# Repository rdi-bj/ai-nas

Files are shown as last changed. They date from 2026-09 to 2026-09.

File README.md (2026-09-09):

# AI NAS 开源项目

本仓库是北京 RDI 创新中心 AI NAS 项目的完整开源 monorepo，包含硬件设计源文件与自研软件/部署脚本。

```
ai-nas/
├── ai-nas-hardware/   # 硬件设计源文件（CERN-OHL-P v2）
└── ai-nas-software/   # 自研软件、固件、部署脚本（Mulan PSL v2）
```

## 子项目说明

| 目录 | 内容 | 许可证 |
|---|---|---|
| [`ai-nas-hardware/`](./ai-nas-hardware/README.md) | RISC-V AI NAS 主板、SATA 扩展板、FPC 排线的原理图、PCB 版图与 BOM | CERN-OHL-P v2 |
| [`ai-nas-software/`](./ai-nas-software/README.md) | 板级支持、NAS 服务、Web UI、部署脚本 | Mulan PSL v2（OMV submodule 为 GPLv3） |

## 快速开始

```bash
# 克隆整个 monorepo
git clone git@github.com:rdi-bj/ai-nas.git
cd ai-nas

# 查看硬件设计
cd ai-nas-hardware

# 查看软件与部署
cd ../ai-nas-software
```

## 双平台同步

本仓以 **GitHub 为主仓**，通过 `.github/workflows/mirror-to-gitee.yml` 单向镜像到 **Gitee**，请勿在 Gitee 端直接提交。

## 二进制发布（固件 / 系统镜像）

可烧录 / 部署的二进制资产（引导固件、系统镜像、OMV 安装包、内核 deb 等）通过 **GitHub Releases** 发布，不纳入 git 仓库：

- 最新发布包 `v1.0-sdk-20260722`：[GitHub Releases 下载](https://github.com/rdi-bj/ai-nas/releases/tag/v1.0-sdk-20260722)
- 全部发布历史：[GitHub Releases](https://github.com/rdi-bj/ai-nas/releases)

> 说明：受 Gitee 免费版单文件（≤100 MB）与 LFS 额度限制，本项目的二进制资产集中在 GitHub Releases；Gitee 仅镜像源码，下载请走上述 GitHub 链接。

## 许可证声明

- 硬件设计：CERN Open Hardware Licence v2 - Permissive（见 `ai-nas-hardware/LICENSE`）。
- 自研软件：木兰宽松许可证 v2（见 `ai-nas-software/LICENSE`）。
- 上游 OpenMediaVault（OMV）为 GPLv3，以 git submodule 形式在 `ai-nas-software/src/openmediavault/` 引用，不复制源码到本仓。

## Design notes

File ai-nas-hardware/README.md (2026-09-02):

# AI NAS 硬件开源仓库（ai-nas-hardware）

基于 RISC-V 的家用开源 AI NAS 硬件设计目录。本目录只包含**硬件设计文件**，软件部分见同仓 [`ai-nas-software`](../ai-nas-software/README.md)。

## 许可证

本仓库所有硬件设计文件以 **CERN Open Hardware Licence v2 - Permissive（CERN-OHL-P v2）** 发布。许可证全文见 [`LICENSE`](./LICENSE)。

> CERN-OHL-P v2 是最宽松的硬件开源许可证，允许任何人自由使用、研究、修改、制造与分发基于本设计的硬件产品，无"传染性"义务，仅要求保留声明（Notices）。

## 目录结构

```
ai-nas-hardware/
├── LICENSE                 # CERN-OHL-P v2 许可证全文
├── NOTICE.md               # 版权、软著与第三方归属声明
├── README.md
├── .gitignore
├── design/                # 设计源文件（按板卡分子目录）
│   ├── MainBoard/          # 主板（00-SCH 原理图 / 01-PCB 版图 / 02-BOM 物料）
│   ├── SATABoard/          # SATA 扩展板
│   └── FPCCable/           # FPC 排线（扁平软板）
└── docs/                  # 文档
    └── user-manual/       # 用户手册
```

> 各板卡的 `.DSN` / `.BRD` 为 Cadence Allegro 专有格式（需 Allegro 授权编辑），配套 `.pdf` 为可读版本；BOM 见各板卡 `02-BOM/`。详细的文件清单见 [`design/README.md`](./design/README.md)。

## 如何获取与组装本硬件

1. 各板卡 `02-BOM/` 提供元器件清单，可据此采购；
2. 软件固件与系统镜像见同仓 [`ai-nas-software`](../ai-nas-software/README.md)。

> 本仓库仅包含硬件**设计源文件**（原理图、PCB 版图、BOM）。Gerber 制板文件、结构件（3D 模型 / 2D 图纸）与制板工艺说明（fab-notes）**不纳入开源范围**，不随仓库公开。

## 声明

- 本仓库所含板级设计归项目承担单位所有，并已在 `NOTICE.md` 中声明。
- SoC（EIC7700）、内存、电源管理芯片等核心器件分别由其原厂所有，遵循各自厂商许可，不在本仓库许可范围内。
- 本仓库不含任何固件二进制或系统镜像；此类文件通过 Releases 分发。

## 关联目录

| 目录 | 内容 | 许可证 |
| --- | --- | --- |
| `ai-nas-hardware` | 硬件设计 | CERN-OHL-P v2 |
| `ai-nas-software` | 自研软件 / 固件 / 部署 | Mulan PSL v2  |

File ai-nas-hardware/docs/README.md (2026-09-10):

# docs/ — 文档

本目录存放 AI NAS 硬件相关**文档**，按用途分子目录：

| 子目录 | 内容 |
|---|---|
| `user-manual/` | 用户手册（开箱、接线、指示灯、注意事项） |

## user-manual/ 清单

| 文档 | 说明 |
|---|---|
| `AI NAS用户使用指导手册_CN_V1.1.docx` | 用户使用指导手册（中文） |
| `AI_NAS_板卡识别与烧录指南.docx` | 板卡识别与固件烧录指南 |

> 物料清单（BOM）已随各板卡在 `design/<板卡>/02-BOM/` 下开源（.xlsx 格式，含位号 / 型号 / 封装 / 用量）。

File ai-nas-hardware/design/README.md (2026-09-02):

# design/ — 设计源文件

本目录存放 AI NAS 板卡的**设计源文件**，按**板卡（board）**分子目录。每个板卡下沿用原交付物命名约定：

- `00-SCH/` 原理图（Allegro `.DSN` + 导出 PDF）
- `01-PCB/` PCB 版图（Allegro `.BRD`）
- `02-BOM/` 物料清单（`.xlsx`）

## 已归集的板卡

| 板卡 | 内容 | 原理图 | PCB | BOM |
| --- | --- | --- | --- | --- |
| `MainBoard/` | 主板（AI NAS 核心板，含 RISC-V SoC） | `00-SCH/AI_NAS_MB_A1_0723.DSN` + `.pdf` | `01-PCB/AI_NAS_MB_A2_pcb.brd`  | `02-BOM/SIBPAAINASE-001_V1.0_长鑫4GB 8533MHZ&长鑫64GB eMMC_260724.xlsx` |
| `SATABoard/` | SATA 扩展板 | `00-SCH/AI_NAS_DB_A1_0723.DSN` + `.pdf` | `01-PCB/AI_NAS_DB__A2_PCB.brd` | `02-BOM/SIBPAAINASC-001_V1.0_260724.xlsx` |
| `FPCCable/`  | FPC 排线（扁平软板，无独立子目录） | `AI_NAS_FPC_A0.DSN` + `.brd` + `.pdf` | （同目录 `.brd`） | `SIBPAAINASD-000_V1.0.xlsx` |

> **关于文件格式**：`.DSN` / `.BRD` 为 Cadence Allegro 专有格式，需 Allegro 授权方可编辑；配套 `.pdf` 为可读版本，便于无 Allegro 许可的社区成员查看。建议后续补充 **PDF 格式的 PCB 丝印/叠层图**，进一步降低阅读门槛。

## 来源

上述文件由`AI_NAS`项目交付物归集而来（版本：主板 A1/A2、SATA 板 A1/A2、FPC A0）。

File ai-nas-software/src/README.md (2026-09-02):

# src/ — 自研源码

本目录存放 AI NAS 的**自研软件源码**（以 Mulan PSL v2 许可）。底层存储管理系统 OpenMediaVault（OMV，GPLv3）以 git submodule 方式引用，见 `src/openmediavault/`（克隆后需 `git submodule update --init`）。

| 子目录 | 内容 | 许可建议 |
|---|---|---|
| `nas-services/` | 自研 NAS 服务（存储编排、网络、AI 推理、监控等） | Mulan PSL v2 |
| `web-ui/` | 管理界面前端 | Mulan PSL v2 |

> **板级支持（设备树、defconfig、U-Boot / OpenSBI 适配）不在本目录**，
> 已独立存放于仓库根目录的 [`board-support/`](../board-support/README.md)。
> 原因是这些文件源自上游 Linux / U-Boot / OpenSBI，须遵循 **GPL-2.0 / BSD-2-Clause** 等上游许可，
> 与 `src/` 的 Mulan PSL v2 自研区做许可证隔离，便于合规审计。

> 判定"衍生作品"时：仅调用 OMV 公开 API / 以独立进程通信的组件可用 Mulan PSL v2；直接修改或链接 OMV 内部、构成其衍生作品的插件须保持 GPLv3 兼容。具体以法务意见为准。

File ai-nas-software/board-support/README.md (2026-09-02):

# board-support — 板级支持（EIC7700 AI NAS）

本目录保存本项目针对 `eic7700-ai-nas` 板卡，对上游 Linux / U-Boot / OpenSBI 所做的**板级配置与适配**。

> **目录结构刻意保持与上游源码树一致**，便于直接将文件覆盖（或打补丁）到 submodule 挂载点。
> 例如 `board-support/linux/arch/riscv/configs/xxx` 对应 `source/linux/arch/riscv/configs/xxx`。

## 目录与许可

| 子目录 | 内容 | 许可 | 对应 submodule |
|---|---|---|---|
| `linux/` | 内核 defconfig、设备树、LED 绑定头、NPU 固件 | **GPL-2.0** | `source/linux` |
| `uboot/` | U-Boot defconfig、板级目录 `board/eswin/eic7700_nas` | **GPL-2.0+** | `source/uboot` |
| `opensbi/` | OpenSBI `platform/eswin/eic770x` 平台支持 | **BSD-2-Clause** | `source/opensbi` |

## 内容清单

### linux/
| 文件 | 说明 |
|---|---|
| `arch/riscv/configs/eic7700_ai_nas_defconfig` | 内核构建配置 |
| `arch/riscv/boot/dts/eswin/eic7700-ai-nas.dts` | 板卡主设备树 |
| `arch/riscv/boot/dts/eswin/eic7700-opptable.dtsi` | 工作点/调频表 |
| `arch/riscv/boot/dts/eswin/eic7700-pinctrl.dtsi` | 引脚复用定义 |
| `arch/riscv/boot/dts/eswin/eswin-win2030-die0-soc.dtsi` | SoC 级定义（die0） |
| `arch/riscv/boot/dts/eswin/eswin-win2030-die0-noc.dtsi` | NoC 互联定义（die0） |
| `arch/riscv/boot/dts/eswin/eswin-win2030-arch.dtsi` | 架构级公共定义 |
| `include/dt-bindings/leds/leds-ainas.h` | **本项目特有**：AI NAS 指示灯 LED 绑定宏 |
| `vendor/eswin/firmware/*.bin` | NPU 固件（二进制，授权见根目录 `NOTICE.md`） |

> 设备树依赖链已完整递归解析：修改 `eic7700-ai-nas.dts` 时，上述 `.dtsi` 均为其传递依赖，缺一不可编译。

### uboot/
| 文件 | 说明 |
|---|---|
| `configs/eic7700_ai_nas_defconfig` | U-Boot 构建配置 |
| `board/eswin/eic7700_nas/{Kconfig,Makefile,MAINTAINERS,eic7700_nas.c}` | 板级初始化代码 |

### opensbi/
| 文件 | 说明 |
|---|---|
| `platform/eswin/eic770x/` | EIC770x 平台支持（DRAM、mailbox、UART、platform） |

## 使用方式

```bash
# 1. 挂载上游源码
git submodule update --init source/linux source/uboot source/opensbi

# 2. 将板级配置覆盖到上游源码树（以 Linux 为例）
cp -r board-support/linux/* source/linux/

# 3. 编译（详见仓库根目录 setenv.sh）
make ARCH=riscv eic7700_ai_nas_defconfig
make ARCH=riscv CROSS_COMPILE=riscv64-unknown-linux-gnu- -j$(nproc)
```

## 重要限制

上游官方 Linux / U-Boot / OpenSBI **不包含芯片厂商的 SoC 支持代码**（驱动、时钟、pinctrl 等私有补丁），
这些补丁由芯片厂商提供且未包含在本仓库中。因此：

- 仅挂载上游 submodule **无法直接完成可启动的构建**；
- 本目录提供的板级配置需配合厂商 SDK 方能生效；
- 若要构建可运行的镜像，请先获取厂商 SDK，再将本目录内容覆盖到对应位置。

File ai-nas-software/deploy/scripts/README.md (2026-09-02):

# deploy/scripts/ — 部署 / 烧录脚本

集中存放设备部署相关脚本，例如：

- `build.sh`：本地构建 / 打包；
- `flash.sh`：将镜像写入 eMMC / SD / SPI Flash；
- `firstboot.sh`：首次启动初始化（分区扩容、服务注册）；
- `upgrade.sh`：OTA / 增量升级。

脚本请保持幂等、可重复执行，并在文件头注明用途、依赖与风险。

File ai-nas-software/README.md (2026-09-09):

# AI NAS 软件开源仓库（ai-nas-software）

基于 RISC-V（EIC7700）的家用开源 AI NAS 的**软件**目录。硬件设计见同仓 [`ai-nas-hardware`](../ai-nas-hardware/README.md)。

## 许可证

各部分许可**不同**，请勿混用：

| 范围 | 许可 |
| --- | --- |
| 本仓库自行整理/编写的部分（构建脚本、文档、目录组织） | **Mulan PSL v2** |
| `src/`（自研服务、Web UI） | **Mulan PSL v2** |
| `board-support/linux/**` | **GPL-2.0** |
| `board-support/uboot/**` | **GPL-2.0+** |
| `board-support/opensbi/**`  | **BSD-2 |
| 二进制固件（`*.bin`） | 见 `NOTICE.md` |

> Mulan PSL v2 是国内首个通过 OSI 认证的开源许可证，中英双语、含显式专利授权与防御性终止条款，宽松无传染性，适合本土企业与法务。

**第三方归属与完整许可声明见 [`NOTICE.md`](./NOTICE.md)。**

## 目录结构

```
ai-nas-software/
├── LICENSE                 # Mulan PSL v2 许可证全文
├── NOTICE.md               # 版权、第三方许可与脱敏声明（重要）
├── README.md
├── CONTRIBUTING.md
├── SECURITY.md
├── CODE_OF_CONDUCT.md
├── .gitignore
├── .gitmodules             # 上游源码 submodule 声明（linux / uboot / opensbi）
├── setenv.sh               # SDK 构建入口（已脱敏）
├── board-support/          # 本项目板级配置（保持上游目录结构，便于覆盖）
│   ├── linux/              #   defconfig、设备树、LED 绑定、NPU 固件   [GPL-2.0]
│   ├── uboot/              #   defconfig、board/eswin/eic7700_nas      [GPL-2.0+]
│   └── opensbi/            #   platform/eswin/eic770x                  [BSD-2-Clause]
├── source/                 # 上游与本项目自有内容
│   ├── linux/              #   submodule 挂载点 → torvalds/linux
│   ├── uboot/              #   submodule 挂载点 → u-boot/u-boot
│   ├── opensbi/            #   submodule 挂载点 → riscv-software-src/opensbi
│   ├── firmware/           #   预编译固件（仅 eic7700-ai-nas 使用部分）
│   └── mkimg/              #   镜像打包工具、es-* 服务、rootfs 构建脚本
├── src/                    # 自研源码 [Mulan PSL v2]
│   ├── nas-services/       # NAS 服务（存储/网络/AI 推理/监控）
│   └── web-ui/             # 管理界面前端
├── deploy/                 # 部署脚本与配置模板
└── docs/                   # 文档
```

## 上游源码：以 submodule 引用，不复制

上游源码体积约 **1.5 GB / 10 万文件**，不放入主仓。本仓库通过 `.gitmodules` 声明依赖，
**需要时按需挂载**：

```bash
# 全部挂载（约 1.5 GB，耗时较长）
git submodule update --init --recursive

# 或只挂载需要的组件
git submodule update --init source/linux
git submodule update --init source/uboot
git submodule update --init source/opensbi
```

| 组件 | 版本 | 许可 |
| --- | --- | --- |
| Linux | 6.6.138 | GPL-2.0 |
| U-Boot  | 2024.01 | GPL-2.0+ |
| OpenSBI | — | BSD-2-Clause |

> **重要限制**：上游官方源码**不含芯片厂商的 SoC 支持代码**（驱动、时钟、pinctrl 等私有补丁），
> 这些补丁由厂商提供且未包含在本仓库。因此仅挂载 submodule **无法直接构建出可启动镜像**；
> 需先获取厂商 SDK，再将 `board-support/` 内容覆盖到对应位置。

## 构建说明

```bash
# 1. 配置源码服务器（原 SDK 使用乙方内部 Gerrit，已脱敏为变量）
export GIT_SERVER_BASE="https://your-git-server.com"

# 2. 配置 Debian 软件源（原为乙方私有源，已脱敏为变量）
export DEBIAN_REPO_BASE="https://your-debian-mirror.com/debian"

# 3. 设置 rootfs 用户口令（切勿使用默认的弱口令 eswin）
export USER_PASSWORD="<强口令>"

# 4. 执行构建，交互菜单中选择板卡 eic7700-ai-nas
bash setenv.sh
```

构建环境要求：Debian/Ubuntu，工具链 `riscv64-unknown-linux-gnu-`（默认位于 `/opt/riscv/bin`）。

# 

## ⚠️ 安全提示

`source/mkimg/` 构建出的镜像**默认用户为 `eswin`、密码 `eswin`**，属弱口令。
任何接入同一网络的人都可登录设备。**部署到生产环境前务必修改口令**。

## 关联目录

| 目录 | 内容 | 许可证 |
| --- | --- | --- |
| `ai-nas-hardware` | 硬件设计 | CERN-OHL-P v2 |
| `ai-nas-software` | 软件、板级配置、构建脚本 | Mulan PSL v2（GPL/BSD 部分见上表） |

## 双平台同步

本仓以 **GitHub 为主仓**，通过 `.github/workflows/mirror-to-gitee.yml` 单向镜像到 **Gitee**（国内加速 + 数据本地化）。
请勿在 Gitee 端直接提交，避免双向同步冲突。

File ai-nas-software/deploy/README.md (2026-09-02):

# deploy/ — 部署

与设备部署、烧录、升级相关的文件。

| 子目录 | 内容 |
| --- | --- |
| `scripts/` | 烧录 / 部署 / 升级脚本（如镜像写入、分区、首次启动配置） |
| `configs/` | 配置模板（网络、存储、服务启停等，不含任何真实密钥） |

>

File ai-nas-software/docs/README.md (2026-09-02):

# docs/ — 文档

本目录存放软件侧设计文档，按类型分子目录：

| 子目录 | 内容 |
|---|---|
| `architecture/` | 架构设计、模块划分、数据流、构建体系说明 |
| `api/` | 对外 API / 内部接口文档（建议 OpenAPI / 注释生成） |

> 用户手册等面向终端用户的文档在硬件仓 `ai-nas-hardware/docs/` 中维护，避免重复。

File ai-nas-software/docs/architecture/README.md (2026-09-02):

# docs/architecture/ — 架构文档

存放 AI NAS 软件整体架构与关键设计决策记录（ADR）：

- 系统分层（板级支持 / 系统服务 / 应用服务 / 管理界面）；
- 存储与网络数据流；
- 与 OpenMediaVault 的集成边界；
- 构建、烧录、升级流程；
- 重决策记录（如为何选用某组件、许可证划分依据）。

建议新增设计变更时同步更新此处，并标注版本 / 日期。

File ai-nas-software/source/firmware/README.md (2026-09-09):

# firmware — 预编译固件（eic7700-ai-nas）

本目录包含 `eic7700-ai-nas` 板卡启动所需的**预编译二进制固件**。

## 内容清单

| 文件 | 用途 | 来源 |
| --- | --- | ---- |
| `secboot_eic7700_ai_nas/die0_sec_fw.bin` | 安全启动固件（die0） | 芯片厂商 |
| `secboot_eic7700_ai_nas/die1_sec_fw.bin` | 安全启动固件（die1） | 芯片厂商 |
| `ddr_fw_die0.bin` / `ddr_fw_die1.bin` | DDR 初始化固件 | 芯片厂商 |
| `ddr_fw_die0_nospi.bin` / `ddr_fw_die1_nospi.bin` | DDR 恢复用固件（无 SPI） | 芯片厂商 |
| `d2d.bin` | Die-to-Die 互联固件  | 芯片厂商 |
| `bootchain.config` | 启动链打包配置（文本） | SDK  |
| `bootchain_die0.config` / `bootchain_die1.config` | 分 die 启动链配置（文本）  | SDK  |

#

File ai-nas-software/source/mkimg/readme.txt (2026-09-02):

# 执行过gpt_partition 就可以flash分区
-> in uboot
fastboot usb 0

-> host
fastboot flash boot boot*.ext4
fastboot flash root root*.ext4

-> in boot
boot

就可以进系统了 用户eswin 密码eswin

> ⚠️ **安全提示**：默认口令 `eswin/eswin` 为弱口令，任何接入同一网络的人都可登录设备。
> 构建前请通过环境变量设置强口令：
>   export USER_PASSWORD="<你的强口令>"
> 首次登录后也请立即执行 `passwd` 修改。

# mkrootfs.sh
需要在debian环境下运行 

> 注意：脚本中的软件源地址已改为变量 `${DEBIAN_REPO_BASE}`，
> 原乙方私有源不随本项目发布，请先配置可用的镜像源地址。

依赖：
sudo apt install -y gdisk dosfstools build-essential autoconf automake autotools-dev ninja-build make \
                                  libncurses-dev gawk flex bison openssl libssl-dev tree \
                                  gcc-riscv64-linux-gnu gfortran-riscv64-linux-gnu libgomp1-riscv64-cross \
                                  qemu-user-static binfmt-support mmdebstrap

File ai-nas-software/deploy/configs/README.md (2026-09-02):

# deploy/configs/ — 配置模板

存放部署所需的**配置模板**（非真实运行配置）。

- 仅包含可公开的默认参数；
- 敏感字段（密钥、令牌、密码）一律以 `<PLACEHOLDER>` 占位；
- 真实配置通过部署时注入，不入库。

建议按环境分子目录（如 `default/`、`prod/`）。

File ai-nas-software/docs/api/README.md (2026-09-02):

# docs/api/ — API 文档

存放对外 / 内部接口文档：

- 管理界面调用的后端 API（建议 OpenAPI 3.0 描述）；
- 设备间 / 服务间内部接口；
- Webhook / 事件约定。

> 优先采用"文档即代码"：用注释或 schema 文件统一生成，避免文档与实现漂移。

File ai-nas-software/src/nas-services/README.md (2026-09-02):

# src/nas-services/ — 自研 NAS 服务

AI NAS 的核心自研服务，可包含（按需分模块）：

- 存储编排与管理（卷、配额、快照、RAID 之上的增值能力）；
- 网络与共享协议适配（SMB/NFS/iSCSI 等之上的增强）；
- AI 推理服务（本地模型加载、推理调度）；
- 监控、告警与运维 Agent。

以 **Mulan PSL v2** 许可发布。若某模块为 OMV 插件且构成衍生作品，须保持 GPLv3 兼容并在文件头声明。

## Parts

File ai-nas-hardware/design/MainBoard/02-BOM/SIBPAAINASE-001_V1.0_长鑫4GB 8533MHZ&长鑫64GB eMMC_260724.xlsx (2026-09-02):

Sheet: Changelist
Change From SIBPAAINASA-000-000-BOM_V1.3 to SIBPAAINASE-001_V2.0
Date | 2026-04-16 |  | Author | Zhangwenqiu | Version | 1.2
Item | Action | Part Reference | Before |  |  |  | After
 |  |  | Value | Description | Manufacture | MFT_Part_Number | Value | Description | Manufacture | MFT_Part_Number
1 | Change | U2,U3 | RS1G32LO5D2FDB-23BT | LPDDR5, 4GB, x32bits, 2channels, 315FBGA, 8533mbps,-25°C to +85°C | Rayson | RS1G32LO5D2FDB-23BT | CXDD5DBAM-MC-M | LPDDR5, 4GB, x32bits, 2channels, 315FBGA, 8533mbps,-25°C to +85°C | CXMT | CXDD5DBAM-MC-M
2 | Change | U10 | RS70B32G4S15G | 32GB EMMC Flash, 153-ball VFBGA, -25°C to +85°C | Rayson | RS70B32G4S15G | YMEC7C0TG1A2C3 | 64GB EMMC Flash, 153-ball VFBGA, -25°C to +85°C | YMTC | YMEC7C0TG1A2C3
3 | Change | D16,D19 | BAT54CW,115 | Vr 30V, Io 200mA, Vf 0.8V@100mA, Dual Diodes, SOT-323-3,BAT54CW,115 | Nexperia | BAT54CW,115 | BAT54CW | Vr 30V, Io 200mA, Vf 0.8V@100mA, Dual Diodes, SOT-323-3,BAT54CW,115 | R+O(宏嘉诚) | BAT54CW
4 | Change | U105 | 74LVC1G08GW,125 | Logic and gate 2 input 1 channel, 1.65v~5.5v,74LVC1G08GW,125 | Nexperia | 74LVC1G08GW,125 | AiP74LVC1G08GC353.TR | Logic and gate 2 input 1 channel, 1.65v~5.5v,AiP74LVC1G08GC353.TR | I-CORE(中微爱芯) | AiP74LVC1G08GC353.TR

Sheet: SIBPAAINASE-001
EIC7700X AI NAS BOM V2.0 8GB
Item | Part_Type | Value | Character1 | Quantity | Reference | Description | Manufacture | MFT_Part_Number | PCB Footprint
1 | MLCC | 22uF | 10V 20% | 59 | C1,C5,C6,C9,C10,C11,C12,C29,C35,C37,C38,C41,C62,C63,C183,C188,C200,C307,C334,C372,C435,C497,C499,C506,C517,C543,C562,C602,C612,C632,C846,C849,C1502,C1503,C1698,C1706,C1709,C1710,C1728,C1729,C1816,C1855,C1856,C1871,C1872,C2016,C2025,C2045,C2046,C2130,C2131,C2132,C2139,C2140,C2145,C2155,C2157,C2158,C2159 | MLCC,22uF,10V,20%,X5R,0603 | SAMSUNG | CL10A226MP8NUNE | C0603
2 | MLCC | 0.1uF | 50V 10% | 108 | C2,C7,C15,C30,C39,C47,C57,C64,C70,C75,C77,C121,C125,C127,C138,C181,C182,C184,C185,C186,C187,C190,C274,C1475,C1497,C1498,C1500,C1504,C1553,C1555,C1600,C1607,C1629,C1676,C1680,C1681,C1682,C1684,C1686,C1687,C1688,C1691,C1695,C1702,C1703,C1707,C1708,C1711,C1713,C1716,C1727,C1782,C1806,C1851,C1857,C1859,C1862,C1867,C1873,C1874,C1878,C1881,C2001,C2012,C2013,C2014,C2015,C2017,C2020,C2022,C2023,C2024,C2026,C2027,C2028,C2029,C2033,C2034,C2035,C2036,C2040,C2065,C2114,C2115,C2116,C2117,C2118,C2120,C2121,C2127,C2128,C2133,C2134,C2135,C2137,C2141,C2147,C2150,C2151,C2156,C2175,C2176,C2177,C2179,C2182,C2184,C2185,C2193 | MLCC,0.1uF,50V,10%,X7R,0402 | muRata | GRM155R71H104KE14D | C0402
3 | MLCC | 22uF | 25V 20% | 32 | C3,C59,C78,C80,C165,C1136,C1471,C1472,C1474,C1494,C1495,C1496,C1499,C1554,C1597,C1598,C1678,C1701,C1803,C1821,C1849,C1850,C1865,C1866,C1999,C2000,C2002,C2113,C2119,C2125,C2126,C2136 | MLCC,22uF,25V,20%,X5R,0805 | muRata | GRM21BR61E226ME44L | C0805
4 | MLCC | 2.2uF | 50V 10% | 2 | C8,C1493 | MLCC,2.2uF,50V,10%,X5R,0805 | SAMSUNG | CL21A225KBQNNNE | C0805
5 | MLCC | 0.1uF | 6.3V 10% | 259 | C13,C22,C23,C24,C25,C26,C27,C40,C42,C43,C45,C48,C49,C50,C51,C52,C56,C192,C193,C196,C197,C202,C203,C205,C206,C208,C209,C210,C212,C217,C221,C225,C229,C230,C231,C232,C233,C236,C238,C241,C272,C273,C278,C280,C289,C290,C291,C292,C293,C294,C295,C296,C297,C298,C299,C300,C301,C302,C303,C304,C315,C316,C318,C319,C320,C321,C322,C323,C324,C325,C326,C327,C328,C329,C343,C345,C346,C347,C348,C349,C351,C352,C353,C354,C355,C356,C357,C358,C359,C360,C361,C362,C363,C364,C366,C367,C368,C382,C383,C384,C385,C386,C387,C388,C389,C390,C391,C392,C393,C394,C395,C396,C397,C398,C399,C400,C401,C402,C403,C404,C496,C498,C500,C501,C502,C503,C504,C505,C507,C509,C515,C519,C520,C521,C522,C523,C524,C525,C526,C527,C530,C531,C532,C542,C546,C547,C548,C549,C550,C551,C552,C553,C554,C555,C556,C557,C558,C559,C560,C561,C563,C564,C565,C566,C567,C568,C572,C573,C574,C575,C576,C577,C578,C579,C580,C581,C589,C590,C591,C592,C593,C594,C595,C596,C597,C598,C599,C600,C601,C604,C605,C606,C607,C608,C609,C610,C613,C614,C615,C616,C617,C620,C621,C622,C623,C624,C625,C626,C627,C628,C629,C630,C631,C636,C637,C638,C639,C640,C641,C642,C643,C644,C645,C646,C647,C648,C649,C650,C651,C653,C654,C655,C656,C657,C658,C659,C660,C661,C662,C663,C664,C665,C666,C668,C669,C670,C671,C672,C673,C674,C1490,C1491,C1492,C1608,C1609,C1610,C1611,C2143,C2144 | MLCC,0.1uF,6.3V,10%,X7R,0201 | YAGEO(国巨) | CC0201KRX7R5BB104 | C0201
6 | MLCC | 22nF | 10V 10% | 6 | C14,C240,C827,C828,C829,C830 | MLCC,22nF,10V,10%,X5R,0201 | SAMSUNG | CL03A223KP3NNNC | C0201
7 | MLCC | 1uF | 6.3V 20% | 33 | C16,C17,C18,C19,C20,C21,C239,C242,C271,C287,C288,C313,C314,C317,C340,C341,C342,C344,C350,C380,C381,C449,C453,C454,C455,C512,C514,C571,C603,C635,C667,C821,C822 | MLCC,1uF,6.3V,20%,X5R,0201 | muRata | GRM033R60J105MEA2D | C0201
8 | MLCC | 0.22uF | 10V 10% | 3 | C36,C2153,C2154 | MLCC,0.22uF,10V,10%,X7R,0402 | SAMSUNG | CL05B224KP5NNNC | C0402
9 | MLCC | 4.7uF | 6.3V 20% | 19 | C44,C211,C216,C220,C224,C228,C235,C277,C279,C281,C285,C312,C338,C339,C378,C379,C448,C451,C1468 | MLCC,4.7uF,6.3V,20%,X5R,0201 | muRata | GRM035R60J475ME15D | C0201
10 | MLCC | 10uF | 6.3V 20% | 30 | C46,C191,C195,C201,C214,C215,C219,C223,C234,C284,C308,C309,C310,C311,C373,C450,C452,C513,C518,C544,C545,C569,C570,C618,C619,C633,C634,C847,C850,C1718 | MLCC,10uF,6.3V,20%,X5R,0402 | SAMSUNG | CL05A106MQ5NUNC | C0402
11 | MLCC | 8.2pF | 25V 0.25pF | 2 | C54,C55 | MLCC,8.2pF,25V,0.25pF,C0G,0201 | SAMSUNG | CL03C8R2CA3GNNC | C0201
12 | MLCC | 47uF | 6.3V 20% | 18 | C60,C61,C82,C83,C305,C306,C330,C331,C332,C333,C369,C371,C533,C1696,C1697,C1705,C1853,C1854 | MLCC,47uF,6.3V,20%,X5R,0603 | muRata | GRM188R60J476ME15D | C0603
13 | MLCC | 220pF | 50V 5% | 6 | C71,C76,C1694,C1699,C1868,C2129 | MLCC,220pF,50V,5%,C0G,0402 | SAMSUNG | CL05C221JB5NNNC | C0402
14 | MLCC | 1uF | 10V 10% | 48 | C72,C126,C189,C1556,C1712,C1717,C1875,C1876,C1879,C2067,C2068,C2070,C2072,C2073,C2074,C2075,C2076,C2077,C2078,C2079,C2080,C2082,C2085,C2086,C2087,C2088,C2089,C2090,C2091,C2093,C2094,C2095,C2096,C2097,C2098,C2099,C2101,C2102,C2103,C2104,C2107,C2109,C2110,C2111,C2112,C2171,C2172,C2180 | MLCC,1uF,10V,10%,X5R,0402 | SAMSUNG | CL05A105KP5NNNC | C0402
15 | MLCC | 4.7pF | 50V 0.25pF | 3 | C122,C123,C124 | MLCC,4.7pF,50V,0.25pF,C0G,0402 | SAMSUNG | CL05C4R7CB5NNNC | C0402
16 | MLCC | 4.7uF | 10V 10% | 10 | C180,C199,C588,C652,C1577,C1578,C1580,C1581,C2160,C2181 | MLCC,4.7uF,10V,10%,X5R,0402 | SAMSUNG | CL05A475KP5NRNC | C0402
17 | MLCC | 1nF | 50V 10% | 6 | C194,C198,C237,C1465,C1467,C2174 | MLCC,1nF,50V,10%,X7R,0201 | muRata | GRM033R71H102KA12D | C0201
18 | MLCC | 10nF | 10V 10% | 9 | C213,C218,C222,C226,C407,C408,C414,C415,C516 | MLCC,10nF,10V,10%,X7R,0201 | muRata | GRM033R71A103KA01D | C0201
19 | MLCC | 12pF | 25V 1% | 2 | C266,C268 | MLCC,12pF,25V,1%,C0G,0201 | muRata | GRM0335C1E120FA01D | C0201
20 | MLCC | 1nF | 50V 10% | 3 | C269,C1579,C1582 | MLCC,1nF,50V,10%,X7R,0402 | SAMSUNG | CL05B102KB5NNNC | C0402
21 | POS-CAP | 330uF | 2.5V 20% | 2 | C286,C1780 | POS-cap, 330uF,2.5V,20%,9m ohm@300KHZ,3.5x2.8x2mm | ROHM | TCOB0E337M8R-EN2 | CASE-B-3528-H2P0
22 | MLCC | 22uF | 6.3V 20% | 15 | C335,C336,C337,C508,C510,C2069,C2071,C2081,C2083,C2084,C2092,C2100,C2105,C2106,C2108 | MLCC,22uF,6.3V,20%,X5R,0402 | muRata | GRM155R60J226ME11D | C0402
23 | MLCC | 100uF | 6.3V 20% | 12 | C695,C777,C823,C825,C826,C890,C1140,C1704,C1778,C1844,C1869,C1870 | MLCC,100uF,6.3V,20%,X5R,1206 | SAMSUNG | CL31A107MQHNNNE | C1206
24 | MLCC | 47uF | 16V 20% | 14 | C862,C1135,C1690,C1700,C1792,C1796,C1797,C1798,C1822,C1823,C1863,C1864,C2146,C2194 | MLCC,47uF,16V,20%,X5R,1206 | TAIYO YUDEN(太诱) | EMK316BBJ476ML-T | C1206
25 | MLCC | 10nF | 50V 10% | 2 | C1464,C2178 | MLCC,10nF,50V,10%,X7R,0402 | SAMSUNG | CL05B103KB5NNNC | C0402
26 | TA-Polymer | 220uF | 6.3V 20% | 2 | C1473,C1599 | TA-Polymer,220uF,6.3V,20%,SMD-3528 | AVX | TLJB227M006R0500 | SMD-3528
27 | MLCC | 22pF | 50V 5% | 2 | C1501,C2138 | MLCC,22pF,50V,5%,C0G,0402 | SAMSUNG | CL05C220JB5NNNC | C0402
28 | MLCC | 12pF | 50V 1% | 2 | C1630,C1631 | MLCC,12pF,50V,5%,C0G,0402 | muRata | GRM1555C1H120JA01D | C0402
29 | MLCC | 0.22uF | 10V 10% | 26 | C1714,C1715,C1719,C1722,C1732,C1733,C2047,C2048,C2049,C2050,C2051,C2052,C2053,C2054,C2055,C2056,C2057,C2058,C2059,C2060,C2061,C2062,C2199,C2200,C2201,C2202 | MLCC,0.22uF,10V,10%,X5R,0201 | SAMSUNG | CL03A224KP3NNNC | C0201
30 | MLCC | 10pF | 50V 0.25pF | 3 | C1720,C1721,C2063 | MLCC,10pF,50V,0.25pF,C0G,0402 | SAMSUNG | CL05C100CB5NNNC | C0402
31 | E-CAP | 270uF | 16V 20% | 2 | C1771,C2192 | E-cap, 270uF,16V,20%,6.3x7.7mm | NCC | APXJ160ARA271MF80J | CAP-SMD-D6_3
32 | MLCC | 1nF | 2KV 10% | 7 | C1785,C1786,C1787,C1788,C2183,C2190,C2191 | MLCC,1nF,2KV,10%,X7R,1206 | FH | 1206B102K202NT | C1206
33 | MLCC | 2.2nF | 50V 10% | 1 | C2149 | MLCC,2.2nF,50V,10%,X7R,0402 | SAMSUNG | CL05B222KB5NNNC | C0402
34 | MLCC | 470pF | 50V 5% | 1 | C2205 | MLCC,470pF,50V,5%,C0G,0402 | muRata | GRM1555C1H471JA01D | C0402
35 | MLCC | 4.7nF | 50V 5% | 1 | C2206 | MLCC,4.7nF,50V,5%,C0G,0402 | muRata | GRM1555C1H472JE01D | C0402
36 | MLCC | 0.1uF | 6.3V 10% | 1 | C2207 | MLCC,0.1uF,6.3V,10%,X5R,0201 | SAMSUNG | CL03A104KQ3NNNC | C0201
37 | Diodes | B5819WS | 40V | 1 | D2 | Vr 40V, Io 1A, Vf 600mV@1A, Single Diodes, SOD_323,B5819WS | CJ | B5819WS | SOD323
38 | ESD | ESD5341N | Vbr=7.0V MIN | 19 | D3,D4,D7,D8,D9,D10,D11,D75,D76,D79,D80,D96,D97,D98,D100,D101,D120,D121,D123 | 1-Line bi-directional TVS, Vbr = 7.0V min,20KV,1pF,ESD5341N-2/TR | WILLSEMI | ESD5341N-2/TR | DFN1006-2
39 | Diodes | BAS70W-05 | 70V | 1 | D5 | Vr 70V, Io 70mA, Vf 1V@15mA, Dual Diodes, SOT-323,BAS70W-05 | CJ | BAS70W-05 | SOT-323-S
40 | Diodes | BAT54CW | 30V | 2 | D16,D119 | Vr 30V, Io 200mA, Vf 0.8V@100mA, Dual Diodes, SOT-323-3,BAT54CW,115 | R+O(宏嘉诚) | BAT54CW | SOT-323-S
41 | Diodes | NSR0620P2T5G | 20V | 1 | D124 | Vr 40V, Io 3A, Vf 350mV@100mA, Single Diodes, SOD-923,NSR0620P2T5G | ONSEMI | NSR0620P2T5G | SOD-923
42 | Diodes | DDZ22BSF-7 | 21.71V | 1 | D46 | D_ZENER_SOD323-DDZ22BSF-7,21.71V,5mA,0.9V@10MA,0.5W | DIODES | DDZ22BSF-7 | SOD323
43 | LED | LED | Red,White | 4 | D86,D89,D90,D91 | Red&White ,White Vf MAX=3.2V, Red Vf MAX=2.4V,HQ19-2232RWC | 宏齐光 | HQ19-2232RWC | LED0603-4P-1P6X1P5
44 | LED | LED | Green | 1 | D104 | Brilliant Yellow Green,Vf=1.75~2.35V, 19-21/G6C-FM1N2B/3T | EVERLIGHT | 19-21/G6C-FM1N2B/3T | Led0603
45 | Ferrite-Bead | 120R@100MHz | 2A | 13 | FB1,FB2,FB3,FB4,FB5,FB8,FB9,FB10,FB63,FB65,FB67,FB68,FB69 | FerriteBead,120R@100MHz,RDC=55mohm,2A | muRata | BLM15PX121SN1D | R0402
46 | FUSE | BSMD2920L-1000-24V | 24V | 1 | F1 | MAX voltage:24V,max current:30A,hold current:10A,trip current:20A,-40℃ to +85℃； | BHFUSE(佰宏) | BSMD2920L-1000-24V | F2920
47 | Screw | LLZN-NUT-0155 | M2 | 2 | H3,H4 | M2*4.5*4.85+0.75,SMT | Sinhoo | ZEC01-002CNJ | circle_pad_c3p5-smt
48 | Screw | LLZN-NUT-0200 | M2 | 3 | H5,H6,H19 | M2*5.0*0.7,SMT | Sinhoo | ZEC01-001CYJ | HOLE_C3R00_C5R00
49 | FAN CON | 4P-1.25 | 1.25mm | 1 | J2 | 1x4PIN,1.25mm,立贴,针座 | DEALON(德艺隆) | 1.25-4PS | CON4-1P25-9P8X4P0
50 | CON | RJ45 FC-GS15MWB6NL | 1x1 | 1 | J3 | RJ45, 1x1, W/ transformer, 10/100/1000M,-40~85℃,6''U Gold,FC-GS15MWB6NL,FLY-CORE | FLY_CORE | FC-GS15MWB6NL | RJ45-1X1-GS15MWB6NL
51 | CON | U231-091N-4BLCC14-F5 | TYPEA | 1 | J7 | USB3.0, Type A, Signle Port, Vertical, U231-091N-4BLCC14-F5,XKB | XKB | U231-091N-4BLCC14-F5 | TYPE-A-TH-13
52 | CON | MC-281-CH510 | TypeC | 1 | J8 | USB3.1, Type C, 5A Vbus max,侧贴,24pin,MC-281-CH510 | HANBO | MC-281-CH510 | TYPEC30-24P-MC281CH510
53 | CON | DC-JACK | MALE | 1 | J19 | DC-Jack, male, 10A@20V,-40~85°C，DC-044B-D025,G-SWITCH | G-Switch | DC-044B-D025 | DC-044B-D020-10A
54 | CON | HDMI-001C | HDMI | 1 | J21 | CON-HDMI,-40~85℃,弯插,HDMI-001C | XUNPU | HDMI-001C | CON_HDMI_TH1X1_LIE_C
55 | CON | BS-08-B2AA020 | CR2032 | 1 | J27 | CR2032 battery connector,30mohm,-25 to 85℃,SMD,BS-08-B2AA020 | MYOUNG | BS-08-B2AA020 | CR2032-BS-08-B2AA020
56 | CON | OK-118RF050/2-35 | 50PIN | 1 | J29 | 0.35mm,50pin,SMD,OK-118RF050/2-35 | 深圳亚奇科技 | OK-118RF050/2-35 | CON50-0p35-OK-118RF
57 | CON | WF13-131G1R | 13PIN | 1 | J30 | 1.25mm,13pin,SMD,WF13-131G1R | COTEX | WF13-131G1R | con13-1p25-21p4x6p7
58 | FAN CON | 2510 3+1 | 2.54mm | 1 | J32 | 1x4PIN,2.54mm,2510 3+1直针黑色 | 中元 | 2510 3+1直针黑色 | CON-254-4P-X2510WV
59 | CON | 40-42406-067B1HF | 75PIN | 2 | J33,J34 | M.2 M key connector, 0.5mm, Gold flash,6.4mm height,40-42406-067B1HF | SHENZHEN DEREN | 40-42406-067B1HF | PCIE75-M2-KEY-M-2280
60 | CON | GT-USB-7004N | TypeC | 1 | J35 | USB2.0, Type C, 5A Vbus max,GT-USB-7004N | G-Switch | GT-USB-7004N | TYPEC20-12P-7004N
61 | PIN Header | 5P-2_54 | 2.54mm | 1 | J36 | 1x5PIN,2.54mm | 连盛 | PH-00759 | CON5_2_54_1X5
62 | PIN Header | 4P-2_54 | 2.54mm | 1 | J37 | 1x4PIN,2.54mm | 连盛 | PH-00316 | CON4_2_54_1X4
63 | Inductor | 0.33uH | 6.8A | 2 | L1,L34 | 0.33uH, 20%, RDC=17mohm, Irms=6.1A,Isat=7.8A | CJIANG | FTC252012SR33MBCA | SMD2520
64 | Inductor | 0.68uH | 6.7A | 1 | L2 | 0.68uH, 20%, RDC=23mohm, Irms=7.5A,Isat=6.7A | CJIANG | FTC252012SR68MBCD | SMD2520
65 | Inductor | 3.3uH | 6.3A | 2 | L5,L30 | 3.3uH, 20%, RDC=35mohm, Irms=6.3A,Isat=8A | CJIANG | FTC404020S3R3MGCA | L414120
66 | Inductor | 0.15uH | 37A | 1 | L11 | 0.15uH, 20%, RDC=0.94mohm, Irms=37A,Isat=47A | YOUCHI(佑驰) | HCMC-0624-R15-M | SMD0624
67 | Inductor | 2.2uH | 2.5A | 3 | L18,L20,L37 | 2.2uH, 20%, RDC=120mohm, Irms=2.5A,Isat=3.0A | CJIANG | FTC201610S2R2MBCA | SMD2016
68 | Inductor | 0.47uH | 11.5A | 3 | L23,L31,L35 | 0.47uH, 20%, RDC=8.4mohm, Irms=11.5A,Isat=18A | CJIANG | FXL0618-R47-M | L706618
69 | Inductor | 1.5uH | 7.4A | 1 | L36 | 1.5uH, 20%, RDC=23.5mohm, Irms=7.4A,Isat=5.8A | CJIANG | FEXL0420A-1R5M | L414120
70 | MOS | RUM001L02T2CL | N-Channel | 20 | Q1,Q3,Q4,Q8,Q9,Q16,Q19,Q31,Q45,Q46,Q47,Q48,Q53,Q56,Q84,Q85,Q86,Q87,Q92,Q93 | N-Channel MOSEFET,Vds 20V,Id 100mA,3.5ohm@4.5V/5.3ohm@1.8V,Vgs(th) 1.1V@100uA,SOT-723,RUM001L02T2CL | ROHM | RUM001L02T2CL | SOT-723
71 | MOS | AONR21357 | P-Channel | 1 | Q17 | P-Channel MOSEFET,Vdss 30V,Id 34A,Vgs(th) 2.3V@250uA,AONR21357 | AOS | AONR21357 | DFN3X3-8
72 | BJT | MMBT3904 | NPN | 1 | Q32 | NPN,Vceo 40V,Ic 200mA,Pd 200mW,MMBT3904 | CJ | MMBT3904 | SOT23
73 | MOS | CJ3400 | N-Channel | 1 | Q49 | N-Channel MOSEFET,Vdss 30V,Id 5.8A,35mohm@10V 5.8A,Vgs(th) 1.4V@250uA,SOT-23,CJ3400 | CJ | CJ3400 | SOT23
74 | MOS | 2SK3018 | N-Channel | 13 | Q71,Q72,Q73,Q74,Q75,Q76,Q77,Q78,Q79,Q80,Q81,Q88,Q89 | N-Channel MOSEFET,Vds 30V,Id 100mA,7.5ohm@10V 400mA,Vgs(th) 2V@100uA,SOT-323,2SK3018 | CJ | 2SK3018 | SOT-323
75 | RES | 5R1 | 0.01 | 1 | R2 | RES,SMD,THKF,5R1,1%,0402,1/16W | YAGEO(国巨) | RC0402FR-075R1L | R0402
76 | RES | 0R | 0.01 | 60 | R3,R9,R11,R17,R27,R38,R42,R138,R203,R250,R254,R255,R259,R260,R689,R2303,R2304,R2389,R2415,R2471,R2473,R2476,R2506,R2530,R2534,R2540,R2561,R2583,R2584,R2593,R2646,R2657,R2665,R2692,R2774,R2826,R2840,R2841,R2842,R2843,R2861,R2907,R2908,R2929,R2930,R2959,R2960,R2961,R2962,R2964,R2966,R2967,R2968,R2969,R3009,R3010,R3011,R3012,R3014,R3019 | RES,SMD,THKF,0R,1%,0402,1/16W | YAGEO(国巨) | RC0402FR-070RL | R0402
77 | RES | 3.4K | 0.01 | 1 | R7 | RES,SMD,THKF,3.4K,1%, 0402, 1/16W | YAGEO(国巨) | RC0402FR-073K4L | R0402
78 | RES | 4.7K | 0.01 | 26 | R10,R20,R86,R2454,R2455,R2734,R2757,R2758,R2761,R2762,R2765,R2766,R2771,R2772,R2786,R2812,R2813,R2847,R2868,R2869,R2870,R2871,R2872,R2873,R2985,R2986 | RES,SMD,THKF,4.7K,1%,0402,1/16W | YAGEO(国巨) | RC0402FR-074K7L | R0402
79 | RES | 100K | 0.01 | 46 | R14,R25,R87,R231,R242,R244,R246,R247,R248,R257,R694,R706,R712,R2365,R2385,R2386,R2388,R2402,R2527,R2528,R2529,R2547,R2553,R2637,R2659,R2732,R2787,R2788,R2789,R2790,R2791,R2792,R2793,R2794,R2801,R2810,R2814,R2815,R2860,R2910,R2915,R2916,R2917,R2918,R3008,R3016 | RES,SMD,THKF,100K,1%,0402,1/16W | YAGEO(国巨) | AC0402FR-07100KL | R0402
80 | RES | 1M | 0.01 | 7 | R19,R21,R50,R51,R2592,R2999,R3000 | RES,SMD,THKF,1M,1%,1206,250mW | YAGEO(国巨) | RC1206FR-071ML | R1206
81 | RES | 510R | 0.01 | 3 | R22,R23,R2844 | RES,SMD,THKF,510R,1%,0402,1/16W | YAGEO(国巨) | AC0402FR-07510RL | R0402
82 | RES | 10K | 0.01 | 55 | R24,R96,R97,R98,R99,R124,R147,R149,R151,R153,R155,R156,R157,R160,R161,R215,R594,R2322,R2323,R2412,R2468,R2469,R2470,R2491,R2492,R2493,R2495,R2499,R2503,R2504,R2505,R2539,R2541,R2548,R2590,R2733,R2736,R2773,R2775,R2848,R2939,R2940,R2943,R2944,R2945,R2946,R2947,R2948,R2952,R2955,R2965,R2970,R2973,R2974,R3015 | RES,SMD,THKF,10K,1%,0402,1/16W | YAGEO(国巨) | RC0402FR-0710KL | R0402
83 | RES | 4.7K | 0.01 | 10 | R29,R30,R32,R35,R36,R40,R2297,R2299,R2300,R2302 | RES,SMD,THKF,4.7K,1%,0201,1/20W | YAGEO(国巨) | RC0201FR-074K7L | R0201
84 | RES | 1.8K | 0.01 | 3 | R41,R109,R110 | RES,SMD,THKF,1.8K,1%, 0402,1/16W | YAGEO(国巨) | RC0402FR-071K8L | R0402
85 | RES | 22R | 0.01 | 16 | R44,R45,R46,R47,R48,R49,R166,R651,R2899,R2900,R2901,R2902,R2903,R2904,R2905,R2906 | RES,SMD,THKF,22R,1% 0201,1/20W | YAGEO(国巨) | RC0201FR-0722RL | R0201
86 | RES | 120R | 0.01 | 2 | R53,R57 | RES,SMD,THKF,120R,1%,0201,1/20W | YAGEO(国巨) | RC0201FR-07120RL | R0201
87 | RES | 240R | 0.01 | 2 | R54,R56 | RES,SMD,THKF,240R,1%,0201,1/20W | YAGEO(国巨) | RC0201FR-07240RL | R0201
88 | RES | 13.3K | 0.01 | 1 | R83 | RES,SMD,THKF,13.3K,1%,0402,1/16W | YAGEO(国巨) | RC0402FR-0713K3L | R0402
89 | RES | 1K | 0.01 | 21 | R88,R2366,R2519,R2521,R2522,R2523,R2602,R2609,R2610,R2611,R2612,R2660,R2727,R2728,R2827,R2831,R2832,R2833,R2837,R2839,R2954 | RES,SMD,THKF,1K,1%, 0402, 1/16W | YAGEO(国巨) | RC0402FR-071KL | R0402
90 | RES | 22R | 0.01 | 11 | R103,R104,R105,R106,R107,R108,R120,R122,R2498,R2542,R2933 | RES,SMD,THKF,22R,1% 0402,1/16W | YAGEO(国巨) | RC0402FR-0722RL | R0402
91 | RES | 27K | 0.01 | 2 | R111,R2324 | RES,SMD,THKF,27K,1%,0402,1/16W | YAGEO(国巨) | RC0402FR-0727KL | R0402
92 | RES | 0R | 0.01 | 50 | R117,R118,R2307,R2308,R2325,R2326,R2327,R2328,R2329,R2330,R2403,R2404,R2405,R2406,R2607,R2608,R2708,R2709,R2710,R2711,R2712,R2713,R2824,R2825,R2874,R2875,R2876,R2877,R2878,R2879,R2880,R2881,R2882,R2883,R2884,R2885,R2886,R2887,R2888,R2889,R2890,R2893,R2975,R2976,R2977,R2978,C2195,C2196,C2197,C2198 | RES,SMD,THKF,0R,1%,0201,1/20W | YAGEO(国巨) | RC0201FR-070RL | R0201
93 | RES | 33R | 0.01 | 7 | R123,R2532,R2535,R2549,R2551,R2667,R2668 | RES,SMD,THKF,33R,1%, 0402, 1/16W | YAGEO(国巨) | RC0402FR-0733RL | R0402
94 | RES | 200R | 0.01 | 4 | R131,R132,R135,R136 | RES,SMD,THKF,200R,1%,0201,1/20W | YAGEO(国巨) | RC0201FR-07200RL | R0201
95 | RES | 30K | 0.01 | 2 | R133,R134 | RES,SMD,THKF,30K,1%,0402,1/16W | YAGEO(国巨) | AC0402FR-0730KL | R0402
96 | RES | 1.62K | 0.01 | 1 | R137 | RES,SMD,THKF,1.62K,1%, 0201, 50mW | YAGEO(国巨) | AC0201FR-071K62L | R0201
97 | RES | 100R | 0.01 | 27 | R162,R163,R647,R711,R2333,R2500,R2501,R2502,R2511,R2520,R2524,R2552,R2613,R2614,R2615,R2616,R2635,R2641,R2650,R2729,R2756,R2811,R2935,R2936,R2937,R2953,R2956 | RES,SMD,THKF,100R,1%, 0402, 1/16W | YAGEO(国巨) | RC0402FR-07100RL | R0402
98 | RES | 220K | 0.01 | 1 | R201 | RES,SMD,THKF,220K,1%, 0402, 1/16W | YAGEO(国巨) | RC0402FR-07220KL | R0402
99 | RES | 22K | 0.01 | 3 | R249,R2531,R2662 | RES,SMD,THKF,22K,1%, 0402, 1/16W | YAGEO(国巨) | RC0402FR-0722KL | R0402
100 | RES | 49.9K | 0.01 | 4 | R258,R2603,R2800,R2909 | RES,SMD,THKF,49.9K,1%,0402,1/16W | YAGEO(国巨) | RC0402FR-0749K9L | R0402
101 | RES | 2R2 | 0.01 | 2 | R270,R2543 | RES,SMD,THKF,2R2,1%, 0402, 1/16W | YAGEO(国巨) | RC0402FR-072R2L | R0402
102 | RES | 220R | 0.01 | 1 | R692 | RES,SMD,THKF,220R,1%, 0402, 1/16W | YAGEO(国巨) | RC0402FR-07220RL | R0402
103 | RES | 1.2M | 0.01 | 1 | R710 | RES,SMD,THKF,1.2M,1%,0402,1/16W | YAGEO(国巨) | RC0402FR-071M2L | R0402
104 | RES | 2.2K | 0.01 | 19 | R773,R774,R2452,R2453,R2586,R2587,R2588,R2589,R2845,R2931,R2932,R2971,R2972,R2983,R2984,R2987,R2988,R2991,R2992 | RES,SMD,THKF,2.2K,1%,0402,1/16W | YAGEO(国巨) | RC0402FR-072K2L | R0402
105 | RES | 402R | 0.01 | 1 | R828 | RES,SMD,THKF,402R,1%,0402,1/16W | YAGEO(国巨) | RC0402FR-07402RL | R0402
106 | RES | 2.49K | 0.01 | 1 | R2301 | RES,SMD,THKF,2.49K,1%,0201,1/20W | YAGEO(国巨) | RC0201FR-072K49L | R0201
107 | RES | 240K | 0.01 | 1 | R2367 | RES,SMD,THKF,240K,1%,0402,1/16W | YAGEO(国巨) | AC0402FR-07240KL | R0402
108 | RES | 60.4K | 0.01 | 3 | R2369,R2663,R2927 | RES,SMD,THKF,60.4K,1%, 0402, 1/16W | YAGEO(国巨) | RC0402FR-0760K4L | R0402
109 | RES | 4.42K | 0.01 | 3 | R2370,R2664,R2928 | RES,SMD,THKF,4.42K,1%,0402,1/16W | YAGEO(国巨) | RC0402FR-074K42L | R0402
110 | RES | 44.2K | 0.01 | 1 | R2390 | RES,SMD,THKF,44.2K,1%, 0402, 1/16W | YAGEO(国巨) | RC0402FR-0744K2L | R0402
111 | RES | 49.9R | 0.01 | 4 | R2537,R2538,R2544,R2545 | RES,SMD,THKF,49.9R,1%, 0402, 1/16W | YAGEO(国巨) | RC0402FR-0749R9L | R0402
112 | RES | 470R | 0.01 | 1 | R2550 | RES,SMD,THKF,470R,1%, 0402, 1/16W | YAGEO(国巨) | RC0402FR-07470RL | R0402
113 | RES | 5.1K | 0.01 | 2 | R2671,R2672 | RES,SMD,THKF,5.1K,1%,0402,1/16W | YAGEO(国巨) | RC0402FR-075K1L | R0402
114 | RES | 20K | 0.01 | 2 | R2799,R2867 | RES,SMD,THKF,20K,1%,0402,1/16W | YAGEO(国巨) | RC0402FR-0720KL | R0402
115 | RES | 12.1K | 0.01 | 3 | R2816,R2834,R2835 | RES,SMD,THKF,12.1K,1%,0402,1/16W | YAGEO(国巨) | RC0402FR-0712K1L | R0402
116 | RES | 19.1K | 0.01 | 1 | R2817 | RES,SMD,THKF,19.1K,1%,0402,1/16W | YAGEO(国巨) | RC0402FR-0719K1L | R0402
117 | RES | 42.2K | 0.01 | 1 | R2818 | RES,SMD,THKF,42.2K,1%, 0201 1/20W | YAGEO(国巨) | RC0402FR-0742K2L | R0402
118 | RES | 137K | 0.01 | 1 | R2819 | RES,SMD,THKF,137K,1%, 0402, 1/16W | YAGEO(国巨) | RC0402FR-07137KL | R0402
119 | RES | 133K | 0.01 | 2 | R2862,R2863 | RES,SMD,THKF,133K,1%, 0402, 1/16W | YAGEO(国巨) | RC0402FR-07133KL | R0402
120 | RES | 63.4K | 0.01 | 1 | R2864 | RES,SMD,THKF,63.4K,1%,0402,1/16W | YAGEO(国巨) | RC0402FR-0763K4L | R0402
121 | RES | 2K | 0.01 | 1 | R2919 | RES,SMD,THKF,2K,1%, 0402, 1/16W | YAGEO(国巨) | RC0402FR-072KL | R0402
122 | RES | 6.8K | 0.01 | 1 | R2934 | RES,SMD,THKF,6.8K,1%, 0402, 1/16W | YAGEO(国巨) | RC0402FR-076K8L | R0402
123 | TOGGLE Switch | 2-bit | 2.54mm | 1 | SW1 | 2-bit Toggle switch,2.54mm,SMT | XUNPU | DSIC-02-TS-GER | SW4-2P54-9P3X5
124 | BUTTON | TS-1088-AR02016 | Touch Button | 4 | S1,S2,S3,S7 | 2PIN Touch Button, 4*3*2mm,SMT,TS-1088-AR02016 | XUNPU | TS-1088-AR02016 | SW-SMD-2-4X3
125 | BUTTON | LYDKFC-L126W6-6AWRW | Touch Button | 1 | S4 | 4PIN Touch Button, DIP,WHITE and RED LED, LYDKFC-L126W6-6AWRW | 力扬达电子 | LYDKFC-L126W6-6AWRW | LYDKFC-L126W6-6AWRW
126 | BUTTON | TC-1101DE-C-A | Touch Button | 1 | S5 | 2PIN Touch Button, 3*6*0.5mm,侧插,WHITE,TC-1101DE-C-A | XKB | TC-1101DE-C-A | SW-TH-TC-1101DE-A-B
127 | IC | EIC7700-XFGCA1 |  | 1 | U1 | EIC7700X AI SoC,ESWIN | ESWIN | EIC7700-XFGCA1 | FCBGA1097-0p65-23x23
128 | DDR | CXDD5DBAM-MC-M | LPDDR5 | 2 | U2,U3 | LPDDR5, 4GB, x32bits, 2channels, 315FBGA, 8533mbps,-25°C to +85°C | CXMT | CXDD5DBAM-MC-M | FBGA315-0p8-12p4X15p0
129 | MCU | GD32F330G8U6TR | MCU | 1 | U4 | ARM Cortex-M4,84MHz, 2.6-3.6V, 64KB@Flash, 8KB@RAM, GD32F330G8U6TR,GigaDevice | GigaDevice | GD32F330G8U6TR | QFN28_0D4_4
130 | IC | RTL8211F-CG | GPHY | 1 | U5 | Integrated 10/100/1000M Ethernet transceiver,support 1.8V/2.5/3.3V; | RealTek | RTL8211F-CG | QFN40_5R00X5R00X0R90_T
131 | Sensor | TMP102AIDRLR | Temp sensor | 1 | U7 | Temp sensor.Voltage range:1.4V~3.6V,Temp range:-40℃~125℃； | TI | TMP102AIDRLR | SOT-563
132 | PWRIC | SY8156IADC | DCDC | 3 | U8,U78,U98 | 6A,4.5-18V,400KHz,Synchronous Step-Down Converter,SY8156IADC | SILERGY | SY8156IADC | TSOT23-6
133 | Flash | YMEC7C0TG1A2C3 | EMMC | 1 | U10 | 64GB EMMC Flash, 153-ball VFBGA, -25°C to +85°C | YMTC | YMEC7C0TG1A2C3 | BGA153C50P14X14_1150X1300X80R
134 | Flash | PY25Q128LA-SUH-I | SPI flash | 1 | U11 | 1.8V 128M Bit,serial flash memory with dual,quad SPI,SOP8 | PUYA | PY25Q128LA-SUH-I | SOIC8-1P27-7P9X5P3
135 | PWRIC | MP5435GQ | PMIC | 1 | U12 | LPDDR4/4X/5 one-chip power solution, Synchronous Buck Converter,MP5435GQ | MPS | MP5435GQ | QFN17-3X3
136 | PWRIC | TPS549D22RVFR | PMIC | 1 | U24 | 40A,1.5V-16V,315KHz-1.125MHz,Synchronous Step-Down Converter with PMBus,TPS549D22RVFR | TI | TPS549D22RVFR | LQFN40-0P5-5X7
137 | PWRIC | TLV75901PDRVR | LDO | 2 | U27,U59 | 1.0A,1.5~6V input, 0.55~5.5V ADJ output, LDO | TI | TLV75901PDRVR | WSON6-0P65-2X2
138 | ESD | TPD4E05U06 | Vbr=6.4V MIN | 7 | U48,U49,U50,U51,U65,U102,U103 | unidirectional,Vbr = 6.4V min, Contact 12KV,Air 15KV, 0.5pF max, 6Gbps Max,TPD4E05U06DQAR | TI | TPD4E05U06DQAR | USON-10
139 | PWRIC | SY8113BADC | DCDC | 2 | U52,U99 | 3A,4.5~18V,500KHz Synchronous Step-Down Converter,SY8113BADC | SILERGY | SY8113BADC | TSOT23-6
140 | LOGIC_GATE | NC7SZ38P5X | NAND | 2 | U53,U54 | Logic nand gate 2 input 1 channel, 1.65v~5.5v,NC7SZ38P5X | onsemi | NC7SZ38P5X | SC70-5
141 | PWRIC | SY81012VDC | DCDC | 3 | U57,U79,U86 | 12A,3.6~16V,1MHz Synchronous step-down buck controller,SY81012VDC | SILERGY | SY81012VDC | QFN19-0P5-3X4
142 | PWRIC | WS4612EAA-5/TR | Power Switch | 3 | U63,U100,U104 | Load Switch, MAX 2A,Programmable, 2.4~5.5V, WS4612EAA-5/TR | WILLSEMI | WS4612EAA-5/TR | SOT_23_5
143 | IC | FUSB303B | CC logic | 1 | U64 | USB Type-C CC logic controller,DFP,UFP,DRP mode selectable | onsemi | FUSB303BTMX | QFN12-0P4-1P6X1P6
144 | IC | FUSB340TMX | Switch Controller | 1 | U66 | USB Type-C Switch Controller fo SS, 10Gbps, 4 to 2, bi-direction | onsemi | FUSB340TMX | QFN18-0P4-2X2P8
145 | RTC IC | PCF85063ATL/1,118 | RTC IC | 1 | U72 | Real-time clock/calendar,I2C,0.9~5.5V, PCF85063ATL/1,118 | NXP | PCF85063ATL/1,118 | DFN10-0P5-2P6x2P6
146 | Flash | P25Q40SH-TSH-IR | SPI flash | 1 | U75 | 4M bits 3V Single I/O SPI Flash,P25Q40SH-TSH-IR | PUYA | P25Q40SH-TSH-IR | tssop8-0p65-3x6p4 | 预烧录
147 | Buzzer | TMB12A05 | Buzzer | 1 | U77 | Buzzer,12.9*9.5mm,5V,Electromagnetic active buzzer | 华能 | TMB12A05 | TH-TMB12A05
148 | Clock | PI6C557-03BLE | PCIE clk buffer | 1 | U80 | PCIE 3.0 Clock Generator with 2 HCSL outputs, 3.3V,LVDS compatible, 35ps Jitter | DIODES | PI6C557-03BLE | TSSOP16-0P65-5X6P4
149 | PWRIC | ETA355E | PMIC | 1 | U85 | PMIC, 1 Bucks, 2.5V to 5.5V input,5A, microBuck DCDC Converter with PMBus Interface | ETA | ETA355E | CSP20-0P4-1P97X1P57
150 | IC | CH340N | USB2UART | 1 | U87 | USB to UART transfer IC, 3.3/5V,CH340N,WCH | WCH | CH340N | SOIC8
151 | MUX IC | SN74LVC1G3157DCKR | MUX | 5 | U92,U93,U94,U95,U96 | 1 channel 2:1 SPDT MUX, 1.65~5.5V | TI | SN74LVC1G3157DCKR | SC70-6
152 | IC | ASM2812 | PCIE SWITCH 12 Lane | 1 | U97 | PCIE SWITCH,4 Upstream，8 down stream@6ports,ASM2812 | ASMEDIA | ASM2812 | BGA492-0P8-21X21
153 | LOGIC_IC | AiP74LVC1G08GC353.TR | AND | 1 | U105 | Logic and gate 2 input 1 channel, 1.65v~5.5v,AiP74LVC1G08GC353.TR | I-CORE(中微爱芯) | AiP74LVC1G08GC353.TR | SOT353
154 | XTAL | 24MHz | 9pF | 1 | Y1 | Crystal, 24MHz,9pf,±10ppm,-40~85℃,SMD2016 | TXC | 8Y24000028 | SMD2016-4P
155 | XTAL | 25MHz | 8pF | 2 | Y2,Y10 | Crystal, 25MHz,8pf,±10ppm,-40~85℃,SMD2016 | TXC | 8Y25000037 | SMD2016-4P
156 | XTAL | 32.768KHz | 12.5pf | 1 | Y7 | Crystal, 32.768KHz,12.5pf,±20ppm,-40~85℃,SMD2012 | TXC | 9H03200012 | SMD2012-2P
157 | XTAL | 25MHz | 16pF | 1 | Y12 | Crystal, 25MHz,16pf,±10ppm,-40~85℃,SMD2016 | TXC | 8Y25000014 | SMD2016-4P

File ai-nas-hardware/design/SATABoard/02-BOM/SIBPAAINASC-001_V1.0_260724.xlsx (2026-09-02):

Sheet: Changelist
Change From SIBPAAINASC-000-BOM_V1.0 to SIBPAAINASC-000-BOM_V1.1
Date | 2026-07-24 |  | Author | guopeipei | Version | 2
Item | Action | Part Reference | Before |  |  |  | After
 |  |  | Value | Description | Manufacture | MFT_Part_Number | Value | Description | Manufacture | MFT_Part_Number
1 | Add | Q21,Q22,Q23,Q24,Q25,Q26,Q27,Q28 |  |  |  |  | CJ2310 | N-Channel MOSEFET,Vdss 60V,Id 3A,125mohm@4.5V ,Vgs(th) 500mV,SOT-23,CJ2310 | CJ | CJ2310

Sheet: SIBPAAINASC-001
AI NAS DB BOM V2.0
Item | Part_Type | Value | Character1 | Quantity | Reference | Description | Character2 | Character3 | Manufacture | MFT_Part_Number | PCB Footprint
1 | MLCC | 0.22uF | 10V 10% | 8 | C3,C4,C7,C8,C54,C60,C73,C74 | MLCC,0.22uF,10V,10%,X5R,0201 | 201 | X5R | SAMSUNG | CL03A224KP3NNNC | C0201
2 | E-CAP | 270uF | 16V 20% | 5 | C17,C35,C48,C65,C82 | E-cap, 270uF,16V,20%,6.3x7.7mm | 6.3x7.7mm | E-Cap | NCC | APXJ160ARA271MF80J | CAP-SMD-D6_3
3 | MLCC | 0.1uF | 50V 10% | 27 | C18,C19,C25,C27,C33,C39,C42,C46,C50,C53,C59,C63,C66,C68,C78,C80,C1676,C2127,C2128,C2133,C2160,C2161,C2166,C2195,C2196,C2197,C2198 | MLCC,0.1uF,50V,10%,X7R,0402 | 402 | X7R | muRata | GRM155R71H104KE14D | C0402
4 | MLCC | 12pF | 25V 1% | 2 | C20,C21 | MLCC,12pF,25V,1%,C0G,0201 | 201 | C0G | muRata | GRM0335C1E120FA01D | C0201
5 | MLCC | 10nF | 10V 10% | 16 | C23,C24,C28,C29,C38,C41,C43,C44,C55,C56,C57,C61,C69,C70,C75,C76 | MLCC,10nF,10V,10%,X7R,0201 | 201 | X7R | muRata | GRM033R71A103KA01D | C0201
6 | MLCC | 1uF | 25V 10% | 4 | C26,C37,C51,C72 | MLCC,1uF,25V,10%,X5R,0402 | 402 | X5R | muRata | GRM155R61E105KA12D | C0402
7 | MLCC | 22uF | 25V 20% | 18 | C30,C31,C32,C36,C40,C45,C49,C52,C58,C62,C67,C71,C77,C79,C2125,C2126,C2158,C2159 | MLCC,22uF,25V,20%,X5R,0805 | 805 | X5R | muRata | GRM21BR61E226ME44L | C0805
8 | E-CAP | 220uF | 6.3V 20% | 4 | C34,C47,C64,C81 | E-cap, 220uF,6.3V,20%,6.3x4.4mm | 6.3x4.4mm | E-Cap | LELON | OVZ221M0JTR-0604 | CAP-SMD-D6_3
9 | MLCC | 4.7uF | 10V 10% | 2 | C1577,C1578 | MLCC,4.7uF,10V,10%,X5R,0402 | 402 | X5R | SAMSUNG | CL05A475KP5NRNC | C0402
10 | MLCC | 1nF | 50V 10% | 7 | C1579,C2172,C2176,C2180,C2184,C2188,C2192 | MLCC,1nF,50V,10%,X7R,0402 | 402 | X7R | SAMSUNG | CL05B102KB5NNNC | C0402
11 | MLCC | 220pF | 50V 5% | 2 | C2129,C2157 | MLCC,220pF,50V,5%,C0G,0402 | 402 | C0G | SAMSUNG | CL05C221JB5NNNC | C0402
12 | MLCC | 22uF | 10V 20% | 6 | C2130,C2131,C2132,C2163,C2164,C2165 | MLCC,22uF,10V,20%,X5R,0603 | 603 | X5R | SAMSUNG | CL10A226MP8NUNE | C0603
13 | MLCC | 0.1uF | 6.3V 10% | 23 | C2134,C2135,C2136,C2137,C2138,C2139,C2140,C2141,C2142,C2143,C2144,C2145,C2146,C2147,C2148,C2149,C2150,C2151,C2152,C2153,C2154,C2155,C2156 | MLCC,0.1uF,6.3V,10%,X7R,0201 | 201 | X7R | YAGEO(国巨) | CC0201KRX7R5BB104 | C0201
14 | MLCC | 10nF | 50V 10% | 6 | C2171,C2175,C2179,C2183,C2187,C2191 | MLCC,10nF,50V,10%,X7R,0402 | 402 | X7R | SAMSUNG | CL05B103KB5NNNC | C0402
15 | MLCC | 100pF | 50V 5% | 6 | C2173,C2177,C2181,C2185,C2189,C2193 | MLCC,100pF,50V,5%,C0G,0402 | 402 | C0G | muRata | GRM1555C1H101JA01D | C0402
16 | MLCC | 10pF | 50V 0.25pF | 6 | C2174,C2178,C2182,C2186,C2190,C2194 | MLCC,10pF,50V,0.25pF,C0G,0402 | 402 | C0G | SAMSUNG | CL05C100CB5NNNC | C0402
17 | ESD | ESD5451N | Vbr=5.1V MIN | 4 | D1,D2,D4,D6 | 1-Line bi-directional TVS, Vbr = 5.1V min,30KV,17.5pF,ESD5451N-2/TR | DFN1006-2 | COMMON | WILLSEMI | ESD5451N-2/TR | DFN1006-2
18 | Ferrite-Bead | 120R@100MHz | 2A | 6 | FB1,FB2,FB3,FB4,FB5,FB6 | FerriteBead,120R@100MHz,RDC=55mohm,2A | 402 | RDC=55mohm | muRata | BLM15PX121SN1D | R0402
19 | FUSE | BSMD0805-125-6V | 6V | 4 | F1,F3,F5,F7 | MAX voltage:6V,max current:40A,hold current:1.25A,trip current:2.5A,-40℃ to +85℃ | 2A | 60mΩ | BHFUSE(佰宏) | BSMD0805-125-6V | F0805
20 | FUSE | BSMD1210-200-16V | 16V | 4 | F2,F4,F6,F8 | MAX voltage:16V,max current:100A,hold current:2A,trip current:4A,-40℃ to +85℃ | 2A | 70mΩ | BHFUSE(佰宏) | BSMD1210-200-16V | F1210
21 | Screw | LLZN-NUT-0200 | M2 | 2 | H1,H2 | M2*5.0*0.7,SMT | 0.7mm | COMMON | VICTOR | LLZN-NUT-0200 | HOLE_C3R00_C5R00
22 | CON | OK-118RF050/2-35 | 50PIN | 1 | J1 | 0.35mm,50pin,SMD,OK-118RF050/2-35 | SMT | COMMON | 深圳亚奇科技 | OK-118RF050/2-35 | CON50-0p35-OK-118RF
23 | CON | WF13-131G1R | 13PIN | 1 | J2 | 1.25mm,13pin,SMD,WF13-131G1R | SMT | COMMON | COTEX | WF13-131G1R | con13-1p25-21p4x6p7
24 | CON | LYDSA-L5ZLC985M-221N | SATA | 2 | J3,J4 | SATA Connector,22 pin,LYDSA-L5ZLC985M-221N | 22 PIN | COMMON | 力扬达电子 | LYDSA-L5ZLC985M-221N | sata30_22p_v_dip
25 | CON | LYDSF-8639430-683N | U.2 | 2 | J5,J6 | U.2 Connector,68 pin,LYDSF-8639430-683N | 68 PIN | COMMON | 力扬达电子 | LYDSF-8639430-683N | SSF-8639-4030683N
26 | Inductor | 3.3uH | 6.3A | 1 | L5 | 3.3uH, 20%, RDC=35mohm, Irms=6.3A,Isat=8A | 20% | 47mΩ | CJIANG | FTC404020S3R3MGCA | L414120
27 | Inductor | 1.5uH | 7.4A | 1 | L36 | 1.5uH, 20%, RDC=23.5mohm, Irms=7.4A,Isat=5.8A | 20% | 23.5mΩ | CJIANG | FEXL0420A-1R5M | L414120
28 | MOS | CJ3401 | P-Channel | 8 | Q1,Q4,Q5,Q8,Q11,Q13,Q17,Q20 | P-Channel MOSEFET,Vdss 30V,Id 4.2A,65mohm@10V 4.2A,Vgs(th) 1.3V@250uA,SOT-23,CJ3401 | 30V 4.2A | COMMON | CJ | CJ3401 | SOT23
29 | BJT | MMBT3904 | NPN | 4 | Q3,Q7,Q12,Q19 | NPN,Vceo 40V,Ic 200mA,Pd 200mW,MMBT3904 | Vceo 40V | COMMON | CJ | MMBT3904 | SOT23
30 | MOS | CJ2310 | N-Channel | 8 | Q21,Q22,Q23,Q24,Q25,Q26,Q27,Q28 | N-Channel MOSEFET,Vdss 60V,Id 3A,125mohm@4.5V ,Vgs(th) 500mV,SOT-23,CJ2310 | 60V 3A | COMMON | CJ | CJ2310 | SOT-23
31 | RES | 0R | 1% | 28 | R1,R2,R3,R4,R5,R6,R7,R8,R9,R10,R11,R12,R13,R14,R15,R16,R17,R19,R2929,R2930,R2931,R2932,R2933,R2934,R2935,R2936,R2937,R2938 | RES,SMD,THKF,0R,1%,0201,1/20W | 201 | COMMON | YAGEO(国巨) | RC0201FR-070RL | R0201
32 | RES | 12K | 1% | 2 | R21,R22 | RES,SMD,THKF,12K,1%,0201,1/20W | 201 | COMMON | YAGEO(国巨) | RC0201FR-0712KL | R0201
33 | RES | 4.7K | 1% | 1 | R23 | RES,SMD,THKF,4.7K,1%,0201,1/20W | 201 | COMMON | YAGEO(国巨) | RC0201FR-074K7L | R0201
34 | RES | 100K | 1% | 14 | R25,R29,R32,R35,R41,R43,R52,R87,R2385,R2386,R2859,R2860,R2925,R2926 | RES,SMD,THKF,100K,1%,0402,1/16W | 402 | COMMON | YAGEO(国巨) | AC0402FR-07100KL | R0402
35 | RES | 820K | 1% | 4 | R26,R31,R42,R53 | RES,SMD,THKF,820K,1%, 0402, 1/16W | 402 | COMMON | YAGEO(国巨) | RC0402FR-07820KL | R0402
36 | RES | 1K | 1% | 4 | R44,R55,R68,R69 | RES,SMD,THKF,1K,1%, 0402, 1/16W | 402 | COMMON | YAGEO(国巨) | RC0402FR-071KL | R0402
37 | RES | 4.7K | 1% | 2 | R49,R57 | RES,SMD,THKF,4.7K,1%,0402,1/16W | 402 | COMMON | YAGEO(国巨) | RC0402FR-074K7L | R0402
38 | RES | 13.3K | 1% | 1 | R83 | RES,SMD,THKF,13.3K,1%,0402,1/16W | 402 | COMMON | YAGEO(国巨) | RC0402FR-0713K3L | R0402
39 | RES | 20K | 1% | 2 | R201,R2862 | RES,SMD,THKF,20K,1%,0402,1/16W | 402 | COMMON | YAGEO(国巨) | RC0402FR-0720KL | R0402
40 | RES | 10K | 1% | 3 | R2468,R2469,R2470 | RES,SMD,THKF,10K,1%,0402,1/16W | 402 | COMMON | YAGEO(国巨) | RC0402FR-0710KL | R0402
41 | RES | 0R | 1% | 6 | R2471,R2473,R2476,R2593,R2692,R2861 | RES,SMD,THKF,0R,1%,0402,1/16W | 402 | COMMON | YAGEO(国巨) | RC0402FR-070RL | R0402
42 | RES | 91K | 1% | 1 | R2863 | RES,SMD,THKF,91K,1%,0402,1/16W | 402 | COMMON | YAGEO(国巨) | AC0402FR-0791KL | R0402
43 | RES | 300R | 1% | 8 | R2940,R2941,R2942,R2943,R2944,R2945,R2946,R2947 | RES,SMD,THKF,300R,1%,1210,1/2W | 1210 | COMMON | YAGEO(国巨) | RC1210FR-07300RL | R1210
44 | IC | JMB585 | PCIE X2 to 5-Port SATA | 1 | U1 | PCIE Gen3x2 to 5 SATA 6Gb/s Bridge, JMB585 | QFN76 | COMMON | JMicron | JMB585-QHBB0A | QFN76-0P4-9X9
45 | PWRIC | SY8156IADC | DCDC | 2 | U8,U98 | 6A,4.5-18V,400KHz,Synchronous Step-Down Converter,SY8156IADC | TSOT23-6 | COMMON | SILERGY | SY8156IADC | TSOT23-6
46 | PWRIC | TLV75901PDRVR | LDO | 1 | U27 | 1.0A,1.5~6V input, 0.55~5.5V ADJ output, LDO | WSON6 | COMMON | TI | TLV75901PDRVR | WSON6-0P65-2X2
47 | Flash | P25Q40SH-TSH-IR | SPI flash | 1 | U75 | 4M bits 3V Single I/O SPI Flash,P25Q40SH-TSH-IR | TSSOP-8 | COMMON | PUYA | P25Q40SH-TSH-IR | tssop8-0p65-3x6p4 | 预烧录
48 | XTAL | 25MHz | 8pF | 1 | Y1 | Crystal, 25MHz,8pf,±10ppm,-40~85℃,SMD2016 | 10ppm | COMMON | TXC | 8Y25000037 | SMD2016-4P

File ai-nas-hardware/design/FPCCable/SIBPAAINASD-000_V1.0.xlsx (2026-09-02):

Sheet: Changelist
SIBPAAINASD-000-BOM_V1.0 Initial Release
Date | 2026-04-08 |  | Author |  | Version | 1.2
Item | Action | Part Reference | Before |  |  |  | After
 |  |  | Value | Description | Manufacture | MFT_Part_Number | Value | Description | Manufacture | MFT_Part_Number

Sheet: SIBPAAINASA-000
AI NAS FPC BOM V1.0
Item | Part_Type | value | Character1 | Quantity | Reference | Description | Manufacture | MFT_Part_Number | PCB Footprint
1 | CON | OK-118RM050/2-35 | 50PIN | 2 | J29,J30 | 0.35mm,50pin,SMD,OK-118RM050/2-35 | 深圳亚奇科技 | OK-118RM050/2-35 | CON50-0P35-OK-118RM

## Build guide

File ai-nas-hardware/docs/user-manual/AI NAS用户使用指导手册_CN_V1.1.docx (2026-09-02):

AINAS用户使用指导手册

Version 1.1

2026年6月25日

修订记录

文档版本 | 日期 | 说明
Version 1.0 | 2026/6/25 | 初始版本
Version 1.1 | 2026/6/26 | 添加软件部分

## 重要安全信息

警告

- 必须在通风良好的环境中操作AI NAS。
- 只能在平坦、不导电的表面上使用本产品，且任何时候都绝不能与导体接触。
- 将不兼容的设备连接到AI NAS上可能会损坏单板计算机。
- 所有与AI NAS一起使用的配件和外围设备必须符合本国规定标准，且必须贴上相应标签，以确保满足安全要求。
- 所有与AI NAS一起使用的线缆和连接设备必须根据安全标准和要求采取正确的绝缘处理措施。

安全须知

须遵守如下所述的要求，从而避免AI NAS出现故障和损坏。

- 不要让AI NAS接触水或暴露在湿气中。
- 在操作过程中，不要将AI NAS放在或靠近导体表面。
- 不要把AI NAS暴露在高温下，按本文规定，只能在室温和空气流通的环境下使用AI NAS。
- 避免对AI NAS上的印刷电路板、接口和集成电路造成任何机械或电气损坏。
- 当AI NAS通电后，应避免拿起或移动。

目录

# 1.简介

AI NAS单板采用ESWIN EIC7700 SoC芯片，采用64位RISC-V四核CPU和自主研发的13.3 TOPS NPU，支持INT8/INT16/FP16数据格式。该产品具有丰富的接口，强大的音频/视频处理能力。

其他亮点包括高达6400Mbps的64位LPDDR5内存，高速闪存，USB3.2 Gen1的外部连接器，千兆以太网等。

AI NAS主要部件如下图所示。

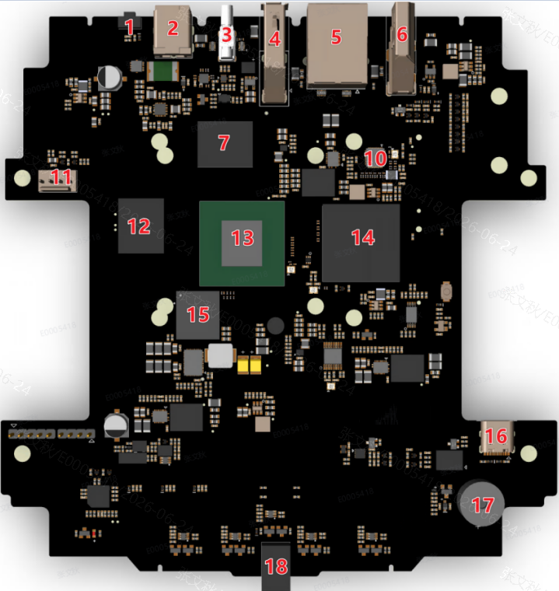
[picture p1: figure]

## Figure 1-1 AI NAS主板表面

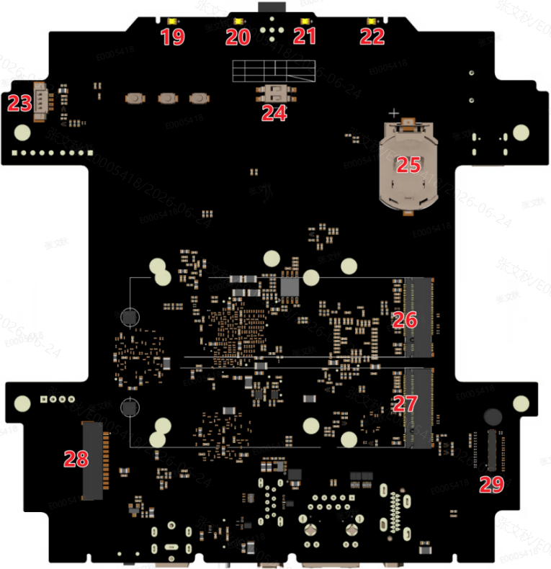
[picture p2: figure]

## Figure 1-2 AI NAS主板底面

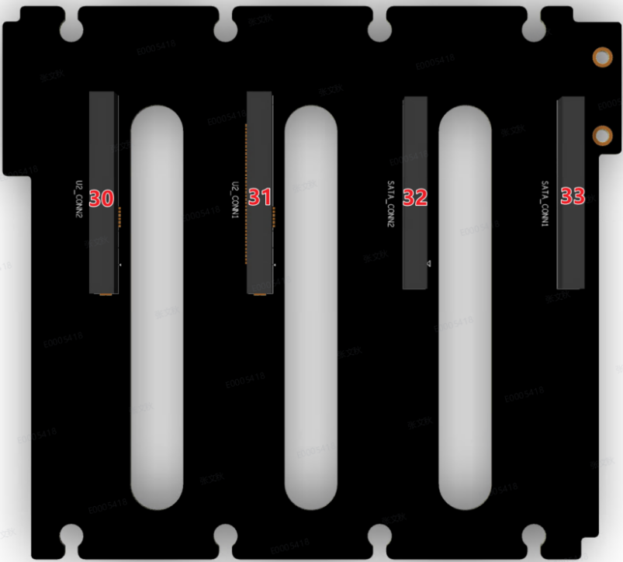
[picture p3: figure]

## Figure 1-3 AI NAS背板

## Table 1 AI NAS组件

编号 | 组件名称 | 编号 | 组件名称 | 编号 | 组件名称
1 | Factory Default Key | 13 | EIC7700 SoC | 25 | RTC BAT Connector
2 | DC Jack | 14 | PCIE Switch | 26 | M.2 NVME Connector
3 | USB 3.0 Gen 1 type C host only | 15 | EMMC Flash | 27 | M.2 NVME Connector
4 | USB 3.0 Gen 1 type A host only | 16 | Debug USB Type C | 28 | Data board power connector
5 | 1000Mbps RJ45 | 17 | Buzzer | 29 | Data board signal connector
6 | HDMI2.0 Type A | 18 | Power Key | 30 | SATA/U.2 Connector
7,12 | LPDDR5 | 19,20,21,22 | SATA LED Indicator | 31 | SATA/U.2 Connector
10 | Gigabit PHY | 23 | Fan Connector | 32 | SATA Connector
| | 24 | Toggle switch for boot mode sel. | 33 | SATA Connector

# 2.设计框图

## 2.1.系统框图

## Figure 2-1 AI NAS系统框图

## 2.2.AI NAS效果图

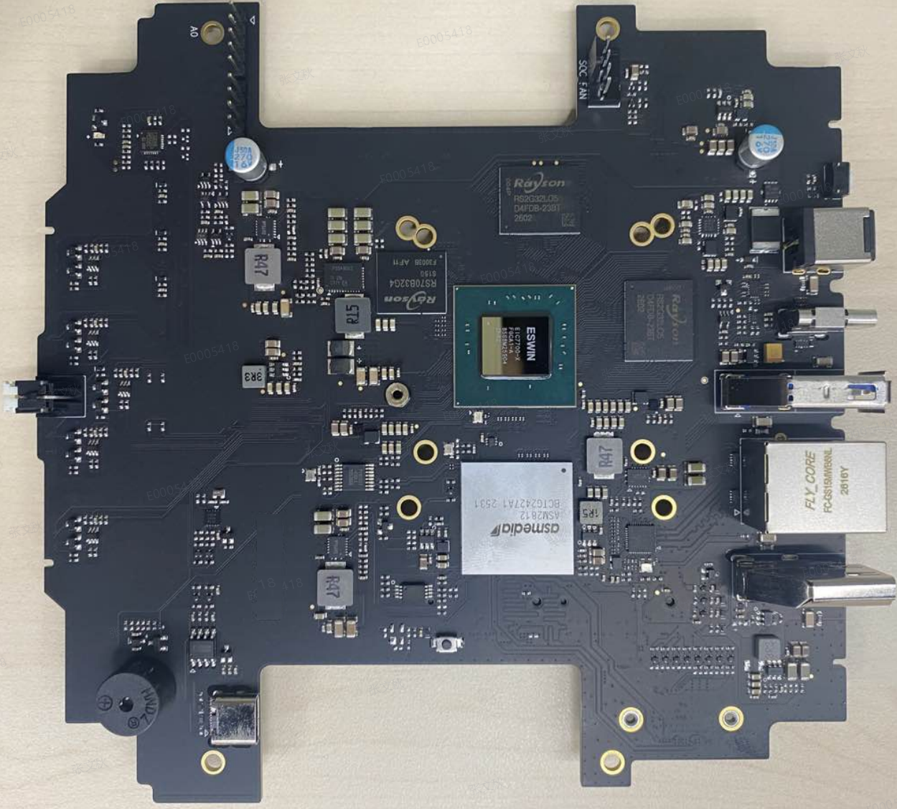
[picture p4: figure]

## Figure 2-2 AI NAS PCBA快照

## 2.3. AI NAS关键特征描述

## Table 2 关键特征参数

类目 | 参数
CPU | - RISC-V RV64GC 4核心 - 时钟频率高达1.4GHz - L1 Cache 32KB(I) + 32KB(D)（私有） - L2 Cache 256KB（私有） - L3 Cache 4MB（共享） - Cache支持ECC（支持SECDED）
DNN加速器 | - Up to 13.3TOPS in INT8
Vision DSP | - 多核DSP单集群 1040MHz，支持512位SIMD和单周期512个INT8 MAC操作
Memory | - 可选8GB/16GB 64位LPDDR5，高达6400MT/s - 可选Inline ECC（支持SECDED）
Flash | - 16MB SPI flash - 32GB EMMC flash
RAS | - SRAM DDR支持奇偶校验和ECC
视频编码 | 视频编码支持高达8K@25fps 或16路1080P@25fps H.265 (HEVC)： - ITU-T Rec. H.265 (04/2013), ISO/IEC 23008-2 - Main Profile, Level 5.1, High Tier - Main10 profile, Level 5.1, High Tier - Main Still Profile H.264 (AVC)： - Spec Version 12:ISO/IEC 14496-10 / ITU-T Rec. H.264 (03/2010) - Baseline Profile, levels 1 - 5.2 - Main Profile, levels 1 - 5.2 - High Profile, levels 1 - 5.2 - High 10 Profile, levels 1 - 5.2

视频解码

视频解码支持高达8K@50fps 或32路1080P@30fps

H.265 (HEVC)：

- ITU-T Rec. H.265 (04/2013), ISO/IEC 23008-2
- Main Profile, up to Level 5.1, High Tier
- Main10 profile, up to Level 5.1, High Tier
- Main Profile, Level 6, High Tier
- Main10 profile, Level 6, High Tier
- Main Still Profile

H.264 (AVC)：

- Spec Version 12:ISO/IEC 14496-10 / ITU-T Rec. H.264 (03/2010)
- Baseline Profile, Levels 1 – 5.2 (up to 4K)
- Main Profile, Levels 1 – 5.2 (up to 4K)
- High Profile, Levels 1 – 5.2 (up to 4K)
- Constrained Baseline, levels 1 – 5.2 (up to 4K)
- Progressive High profile, levels 1 – 5.2 (up to 4K)
- High 10 profile (progressive only), levels 1 – 5.2 (up to 4K)
- High 10 Intra profile (progressive only), levels 1 – 5.2 (up to 4K)
- Constrained Baseline, level 6 (up to 8K)
- Progressive High profile, level 6 (up to 8K)
- High 10 profile (progressive only), level 6 (up to 8K)
- High 10 Intra profile (progressive only), level 6 (up to 8K)

JPEG 编解码 | JPEG ISO/IEC 10918-1, ITU-T T.81. - 支持最大分辨率32K x 32K - Baseline process (内部支持Huffman coding Interleaved YUV420, YUV422，Monochrome) - Lossless process (内部支持8-bit with Huffman coding Interleaved YUV420，Monochrome) - MJPEG format (T.81 Annex H) in AVI container
Vision Engine | - HAE (2D Blit, Crop, Resize, Normalization)
GPU | - 3D GPU (支持 OpenGL-ES 3.2、EGL 1.4、OpenCL 1.2/2.1 EP2、Vulkan 1.2、Android NN HAL)
显示系统 | - OSD (3个图像层，分别为视频层、鼠标层、背景层)
LLC | - 4MB (128Bytes cache line，16 ways associativity) - ECC（支持SECDED）
安全 | - TEE, TRNG, ECDSA, ECC, RSA, AES, SM3/4, SHA256, DES, HMAC, CRC32 - 16KB OTP
USB接口 | - 1x USB3.2 Gen 1 Type C - 1x USB3.2 Gen 1 Type A
以太网 | - 千兆以太网，RJ45接口
HDMI | - HDMI接口，支持HDMI2.0协议 - 支持HDCP1.4/2.2
按键 | - 1x 恢复出厂设置按键 - 1x 电源按键 - 1x 硬件复位按键（板内） - 3x 用户自定义按键（板内）
FAN接口 | - PWM 速度控制 - Tachometer转速反馈
NVME | - 2x M.2 NVME x1接口
SATA接口 | - 4x SATA接口，其中两个兼容U.2硬盘
RTC电池接口 | - 3V RTC电池接口
整体功耗 | - 依赖于应用场景，建议使用支持12V，至少8A供电能力的适配器
工作温度 | - 0~35°C
PCBA尺寸 | - 151.6*152.4*1.6mm

# 3.硬件介绍

## 3.1.电源接口

AI NAS采用5525 DC JACK接口，适配器采用12V/8A适配器，以满足不同应用场景的供电需求。注意AI NAS最大支持电压为12V，大于12V电压会导致AI NAS损毁。

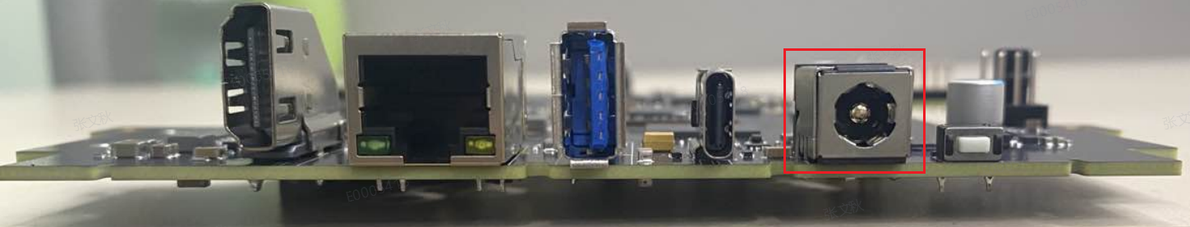
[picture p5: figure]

## Figure 3-1 5525 DC JACK供电接口

## 3.2.USB接口

AI NAS集成2个USB接口，1x USB 3.0 Gen 1 Type C接口，和1x USB 3.2 Gen 1 Type A接口。注意，这些接口都是Host only的，只有在USB启动模式或者Uboot下使用Fastboot模式下，Type C接口用于下载接口被配置成Device，连接到Host端。

所有这些USB端口都支持键盘、鼠标和其他USB外设。

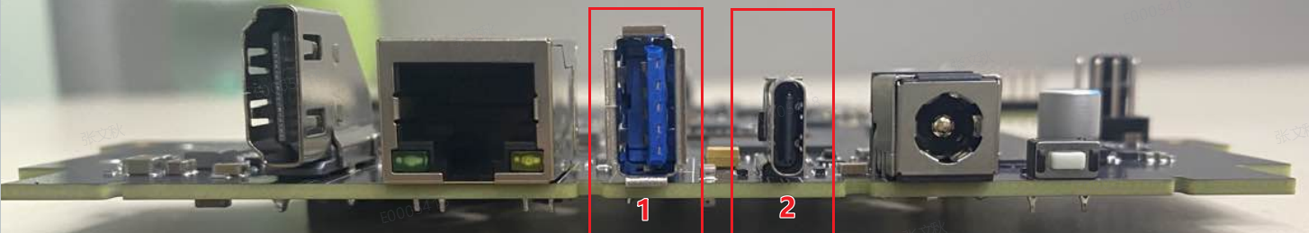
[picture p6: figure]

## Figure 3-2 USB接口

## Table 3 USB接口描述

USB接口 | 描述 | 备注
1 | USB3.2 GEN 1 Type A, 兼容USB2.0 | 提供最大2A电流
2 | USB3.2 GEN 1 Type C, 兼容USB2.0 | a. 强制恢复模式下使用该端口作为软件下载接口 b. 在Uboot中使用此端口进行Fast boot。 c. 提供最大3A电流

备注：2接口在Uboot下为Device模式

## 3.3.显示接口

AI NAS集成了1x HDMI端口。

HDMI接口支持HDMI 2.0/1.4b TX，支持1080P@120Hz、4Kx2K、3D （340MHz TMDS时钟）。

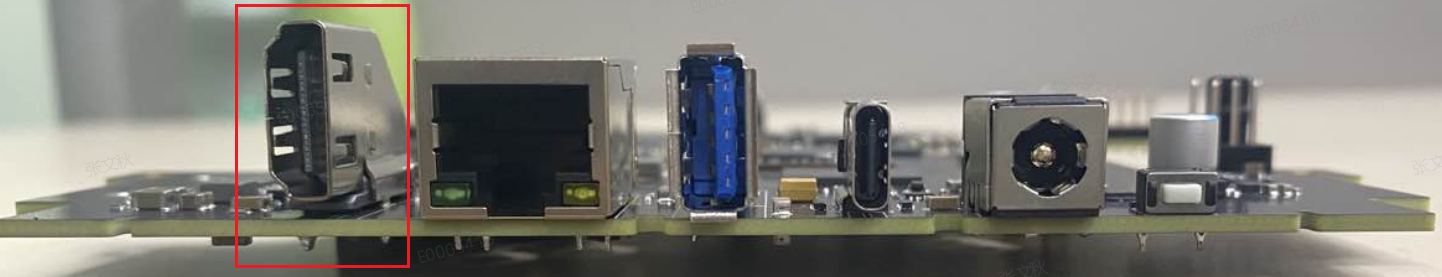
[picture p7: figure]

## Figure 3-3 AI NAS HDMI

## 3.4.网络接口

AI NAS集成了1x RJ45端口。

RJ45接口最高支持1000Mbps传输速率。

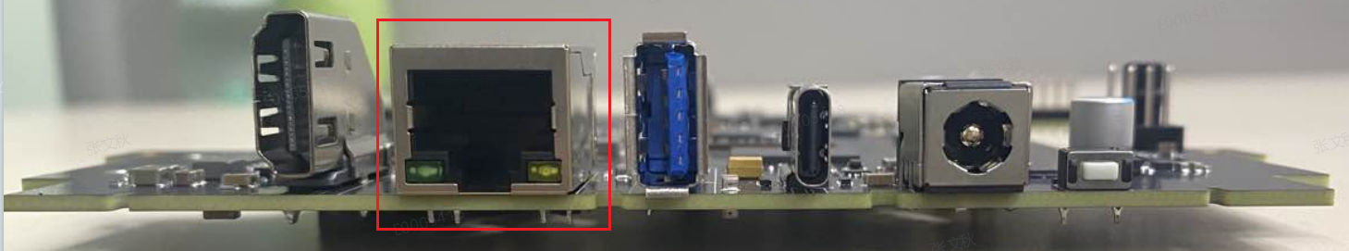
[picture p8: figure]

## Figure 3-4 AI NAS RJ45接口

## 3.5.按键

AI NAS板上有6个按键，位置请参考下图：

参照Figure 3-5，按键1为电源开关按键，在关机状态下，短按（<1s)可开机，在开机的状态下，长按2s释放，系统执行shutdown流程，长按超过8s，则强制断电。

参照Figure 3-5，按键2为复位按键，按下并释放此按键，完成硬件复位；

参照Figure 3-5，按键3为恢复出厂设置按键，长按超过20s钟，直到电源灯和硬盘灯同时红色快速闪烁，系统进入恢复出厂设置流程；恢复出厂设置不影响硬盘数据。

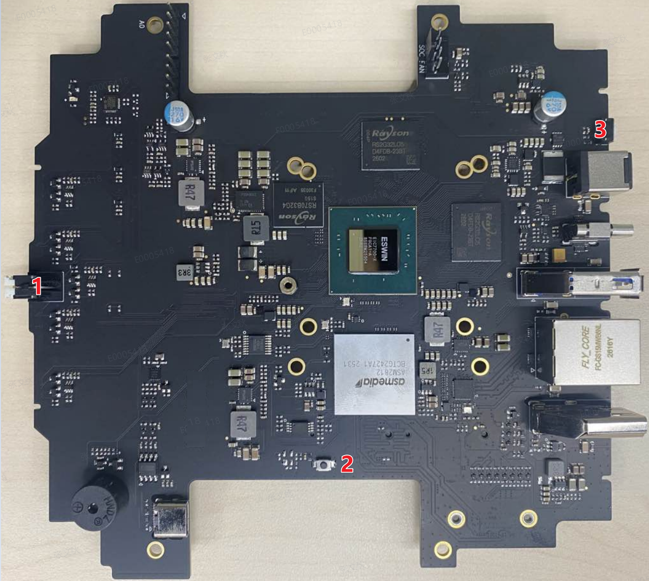
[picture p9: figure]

## Figure 3-5 AI NAS PCBA正面按键

参照Figure 3-6，按键4，5，6为用户自定义按键，可根据需求从软件层面设定这三个按键的相关功能；

## Figure 3-6 AI NAS PCBA背面按键

## 3.6.启动模式

AI NAS的启动模式由拨码开关控制，拨码开关位置见图Figure 3-7，编号1位置，拨码开关上部为bootsel0，下部为bootsel1，拨码至1侧，则为1，拨码至0侧，则为0。

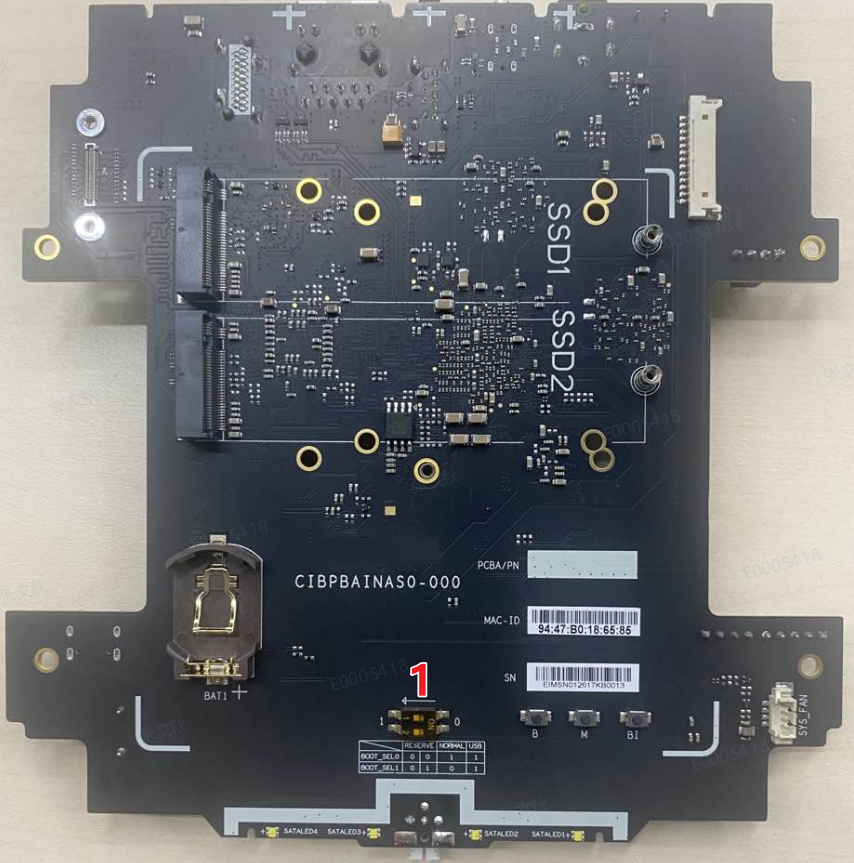
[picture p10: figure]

## Figure 3-7 AI NAS 拨码开关

启动模式见下表

## Table 4 启动模式描述

启动模式 | SPI NOR Flash模式（正常启动） | 强制恢复模式
Bootsel0 | 0 | 1
Bootsel1 | 1 | 1

Boot相关程序已预烧录在板载SPI NOR flash中，在正常模式下，开机时系统将从SPI NOR flash启动。

以下方法可以使AI NAS进入Force Recovery模式：

上电前，将拨码开关的boot sel 0和bootsel 1拨到1侧，并用Type C线将AI NAS的Type C接口连接至Host端，然后上电。

当AI NAS进入恢复模式后，主机端将识别AI NAS为一个U盘，将恢复引导文件复制到该位置，AI NAS将自动启动，进而可以通过串口进行相关的系统恢复操作。

## 3.7.FAN接口

风扇接口采用1.25mm间距、4pin连接器，包括风扇PWM控制、转速反馈，12V电源和GND。此连接器可驱动12V风扇。

连接器位置及信号详细说明请参考下图及表格。

## Figure 3-8 AI NAS FAN接口

Table 5 FAN Connector PIN

Pin No. | Pin Name | Description
1 | GND | Reference ground
2 | 12.0V | 12.0V power supply for FAN
3 | TACH | Speed feedback signal
4 | PWM | PWM for FAN speed control

## 3.8.RTC电池接口

RTC备用电池接口采用了CR2032标准电池座连接器。

连接器位置及信号详细说明请参考下图及表格。

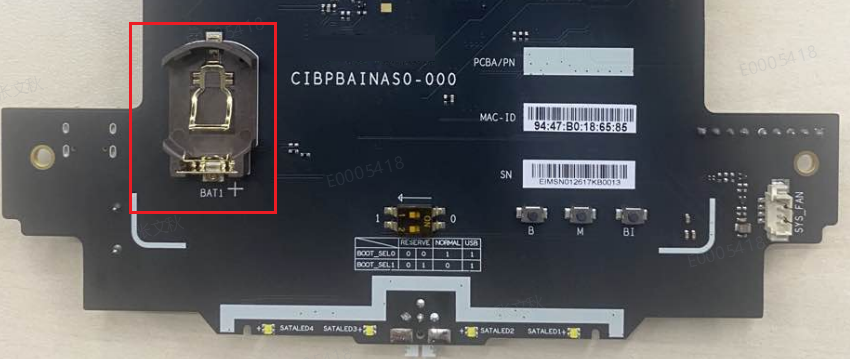
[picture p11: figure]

## Figure 3-9 AI NAS RTC电池接口

## 3.9.LED指示灯

AI NAS共计5个双色LED（红、白双色）指示灯，用于指示电源和硬盘接口状态，其中电源指示灯嵌入电源在电源按键中。

位置及状态详细说明请参考下图及表格。

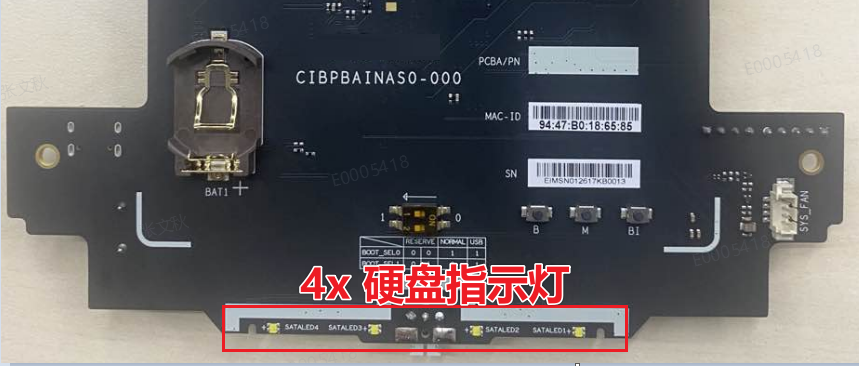
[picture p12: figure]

## Figure 3-10 AI NAS 硬盘指示灯

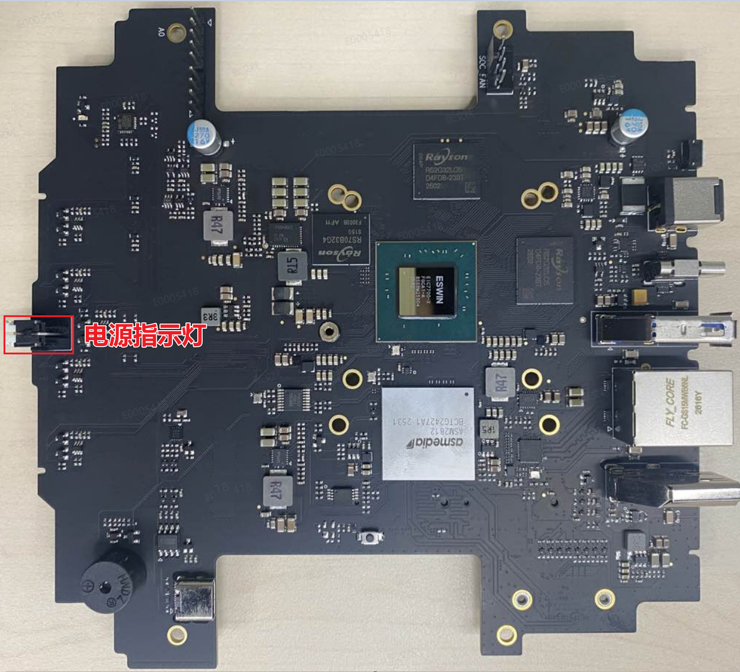
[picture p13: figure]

## Figure 3-11 AI NAS 电源指示灯

Table 6 LED状态定义

| 熄灭 | 白色 | 红色
硬盘指示灯 | 未检测到硬盘 | 正常状态 | 硬盘读写（闪烁）
电源指示灯 | 关机 | 开机 | 暂无逻辑

## 3.10.蜂鸣器

AI NAS带1个蜂鸣器，在DDR Training PASS后，会“滴”一声，如果DDR Training fail（故障），蜂鸣器会“滴”五声。

在后续程序中，软件可调用蜂鸣器功能，以达到用户所需要的效果。

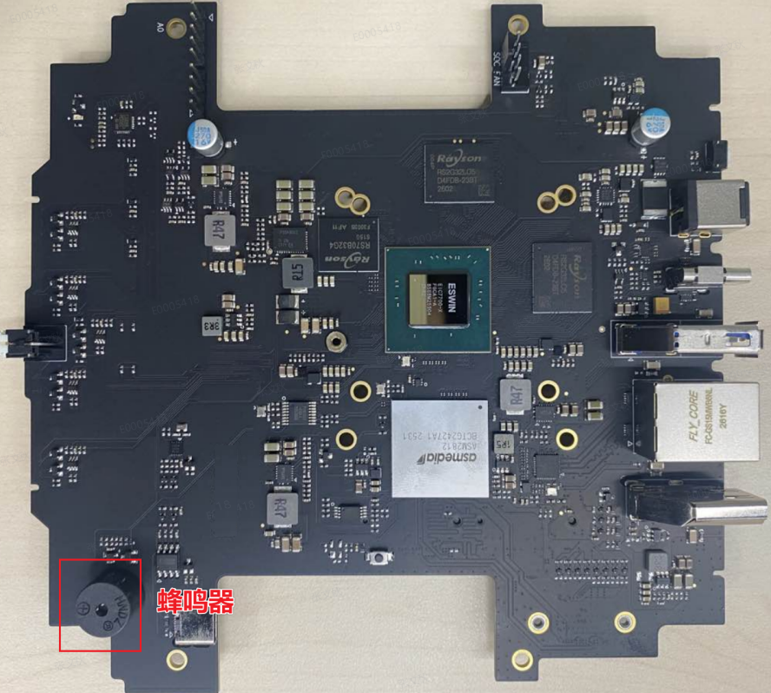
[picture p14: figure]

## Figure 3-12 AI NAS 蜂鸣器

## 3.11.调试接口

AI NAS在板内提供一个USB Type C转UART的调试接口，该接口波特率为115200，8N1，无流控，使用Type C线连接AI NAS和HOST(PC端），使用串口工具（如putty、minicom等），可以查看7700相关日志以及进行烧录升级等操作。

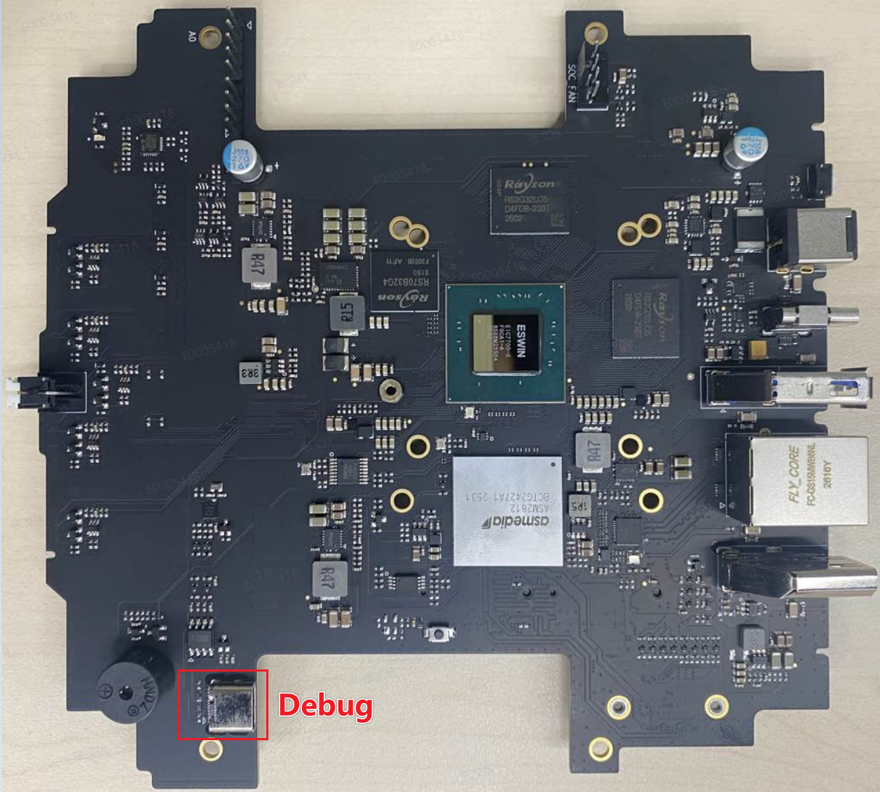
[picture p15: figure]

## Figure 3-13 AI NAS Debug接口

# 4 软件介绍

## 4.1 软件规格说明 操作系统：Debian Trixie版本

NAS系统：采用开源OpenMediaVault V7.x原生代码进行RISC-V架构的移植编译
OMV插件列表：

- 支持RAID插件，可本地安装
- 支持Gossa插件，可以浏览图片，以及流媒体支持的视频播放

## 4.2 板卡烧录

参考《AINAS板卡识别与烧录指南_Readme_New.docx》文档

## 4.3 OMV安装说明

1. sudo -i（输入密码）

2. apt install salt-minion -y

3. mkdir -p /etc/wsdd-server

4. sed -i.bak '50s#///##' /usr/lib/python3/dist-packages/salt/utils/url.py

5. apt install openmediavault -y（网络配置选5. Local only，邮箱名任意填写）

6. sed -i '43s/\bondemand\b/performance/' /etc/init.d/cpufrequtils

7. sed -i -e 's/^#DNS=/DNS=10.11.2.32 10.11.2.33/' -e 's/^#Domains=/Domains=xxx.cn/' /etc/systemd/resolved.conf (这里xxx.cn需要替换实际的域)

8. reboot

## 4.4 OMV登陆

登陆主板IP对应的网址：http://IP，所有的omv操作都可以基于该网页操作。
默认用户名称：admin
默认登陆密码：openmediavault

登陆页面

4.5 设置固定 IP 地址
DHCP 分配 IP 地址，意味着每次开机后 NAS 的 IP 地址会变化，显然容易影响 OMV 的使用体验。所以需要给 NAS 分配固定的 IP 地址。

第一步：在管理后台左侧，依次点击「网络」==>「接口」，可以看到如下图所示的界面。默认情况下这里是没有添加任何项目的。

OMV 的网络接口（网卡）管理页面

第二步：点击列表左上角的「加号」按钮，在弹出的菜单中选择「以太网」：

OMV 支持五种不同类型的网络，其中有线网卡对应的是「以太网」

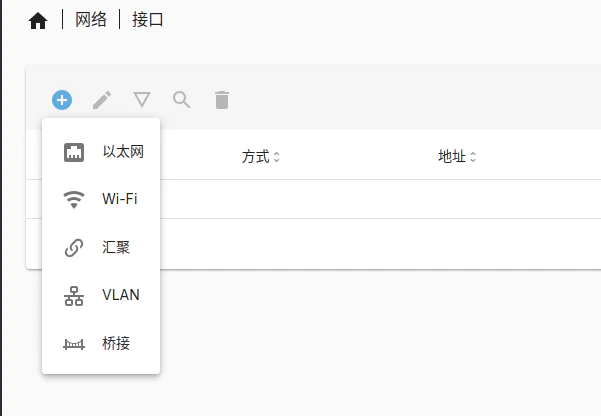
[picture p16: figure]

第三步：接下来就会打开网卡设置的界面，如下图所示。
在顶部的「设备」下拉框中，选择要使用的网卡。通常格式为「enp0sxx」的是板载有线网卡；而名称一长串、以「enx」开头的网卡则为独立安装的网卡，图中这个网卡「enx00e04c6800e1」是扩展卡上的千兆网卡。
在「IPv4」一栏中，将「方式」设为「静态」，然后依次指定 IP 地址、子网掩码和网关地址。
「IPv6」这一栏则按需设置。如果不使用或很少使用 IPv6，保持默认设置（「自动」）即可。

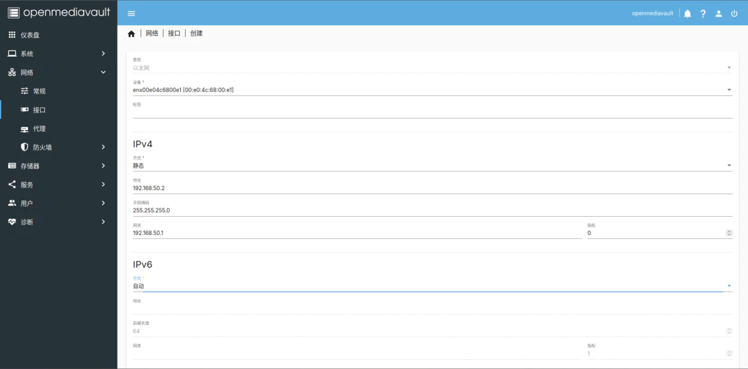
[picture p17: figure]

网卡设置界面

第四步：设置 DNS。把网页拉到最下面，可以看到「高级设置」一栏。在「DNS 服务器」一栏中填入服务器地址，例如阿里 DNS（223.5.5.5）。其它设置保持默认值。

DNS 服务器设定界面

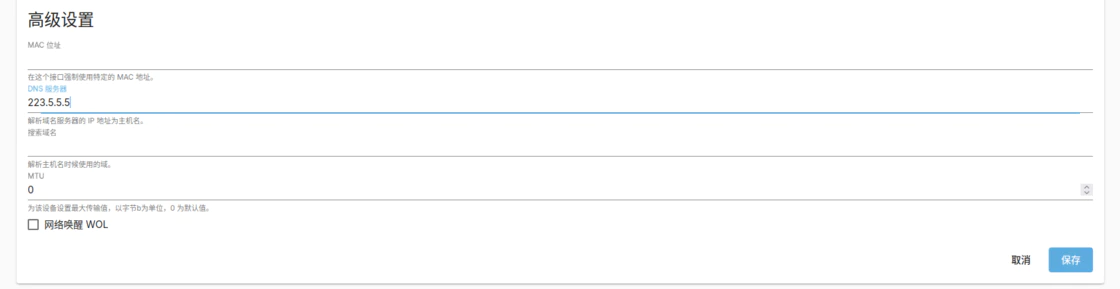
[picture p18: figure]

第五步：确认设置。点击页面最底部右下角的「保存」按钮，随后会回到网卡列表的页面，并且顶部会出现一个黄色横幅：「待应用的配置更改」。点击横幅右上角的「✅」图标，应用设置。

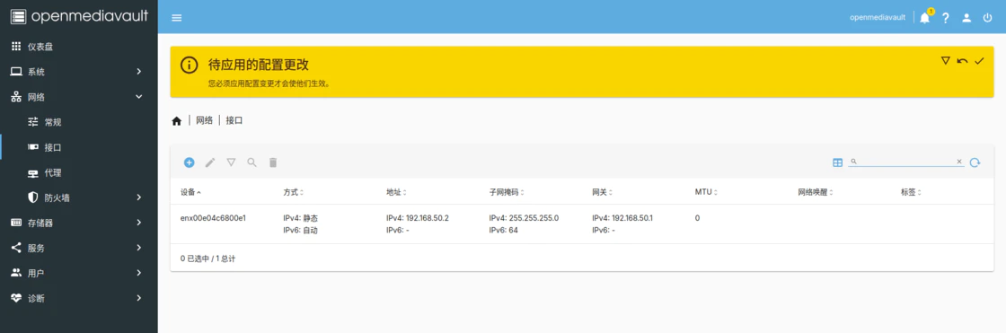
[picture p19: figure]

操作等待更新确认

此时网卡已经完成配置，但要手动点击横幅上的「✅」按钮才能生效。
稍等片刻，网络设置就生效。接下来，就可以直接用固定的 IP 地址来访问 NAS 了。

提示：从现在开始，可以拔掉 NAS 的显示信号线了，之后的操作都不需要再使用显示器和键鼠。

4.6 修改管理员密码
为了保证 OMV 的安全，网页管理界面的密码也需要重新设置。

在 OMV 管理界面中，点击右上角的「用户」图标，在弹出的菜单中选择「更改密码」，如下图所示：

然后在弹出的界面中指定新密码即可。

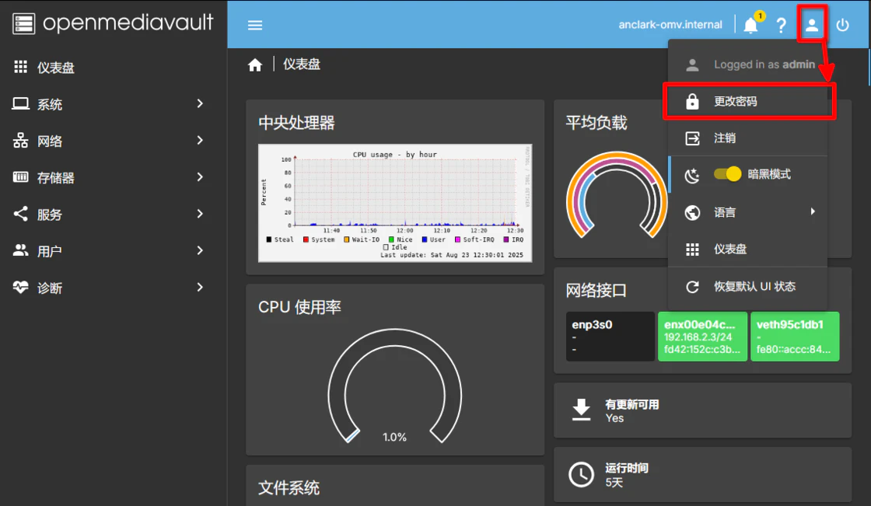
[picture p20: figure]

ℹ️提示：不建议设置为与 root 相同的密码。

4.7 创建用户
SMB/CIFS、FTP 等文件共享协议允许匿名访问，也就是无需登录即可访问 NAS 的共享文件夹。但如果有一些重要的文件，希望用户在登录后才能访问。

因此，为了让其它设备安全可信地访问 NAS 上的文件，需要新建一个用户。这样，我们就可以在为 OMV 配置文件共享协议时，禁止匿名访问特定的共享文件夹。

第一步：在左侧的功能列表中，依次点击「用户」==>「用户」，打开「用户管理」界面：

第二步：点击工具栏上的「带圆圈的加号」按钮，在弹出的菜单中选择「添加」，开始创建用户。随后，指定用户的【名称】和【密码】，并在【确认密码】中再输一次你指定的密码。其它值保持默认不用修改。

本例中，假设用户名为robin
确认无误后，拉到最下方点击「保存」，并提交更改。

用户维护界面

在此基础上，你还可以创建更多的用户，在之后的操作里给不同的用户指定不同的权限等设置。

4.8 配置文件系统
在 OMV 中，要想用上数据盘，让局域网内的设备访问 NAS 中的数据，需要「三步走」：

挂载数据盘的文件系统

设置共享文件夹及其权限

设置 SMB/CIFS 共享，让局域网的设备能够访问 NAS 上的文件。
上面三个步骤环环相扣，连接紧密，务必循序渐进一步步操作。首先第一步就是要挂载文件系统。

## 4.9 挂载文件系统

OMV 不会自动识别并挂载数据盘，需要手动在 OMV 的「文件系统」管理器中挂载数据盘的分区。

第一步：在 OMV 的网页端管理界面中，依次点击「存储器」==>「文件系统」，可以看到下面这个界面：

「文件系统」管理界面

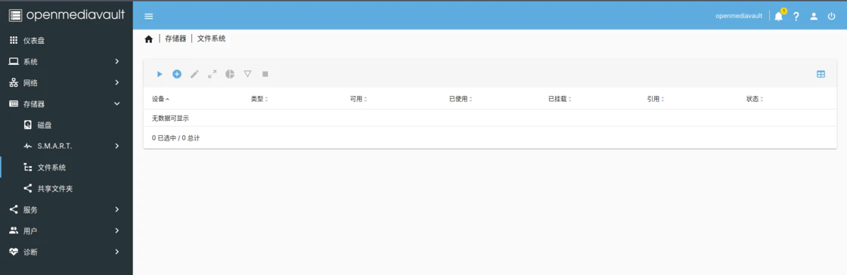
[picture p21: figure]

现在是空的，还没有挂载文件系统。

第二步：点击工具栏「右三角（▶️）」按钮，进入「挂载」界面，该界面用于挂载磁盘上已有的分区。
在「文件系统」下拉框中，选择要挂载的分区，可以根据容量和文件系统来判断。图中的/dev/sda2是示例笔记本电脑 1TB 硬盘上的数据分区，此前一直在 Windows 下使用，为 NTFS 文件系统。
「标签」用于直观地标识你挂载的分区，可以按个人喜好来指定，例如「数据盘」「Notebook HDD」等。可以指定多个标签。
「用量警告阈值」可以按需设置。

第三步：确认无误后，点击「保存」，回到「文件系统」界面。此时网页上还会出现「待应用的配置更改」横幅，点击横幅上的「✅」按钮使设置生效。
如果你还有其他的分区要挂载，则重复上面的步骤。

擦除磁盘并创建文件系统（对于新磁盘，或者无须保留数据的磁盘）
如果购入了新硬盘，或者是要清除原有磁盘的数据并用作 NAS 存储，则可以在磁盘管理界面中，选中要清除数据的硬盘，然后点击「橡皮擦（清除磁盘数据）」按钮。

随后，OMV 会要求你确认。若要继续清除磁盘，则确认即可。

⚠️注意：
由于 OMV 的设计，如果不清除整个磁盘的数据，则无法在 OMV 中创建文件系统。

完成擦除后，进入「文件系统」管理器页面，找到「带圆圈的加号」按钮——也就是创建新文件系统的按钮。点击后，出现一个菜单，其中列出了 OMV 支持创建的几个文件系统：

OMV 创建文件系统的菜单

可以选择你需要的文件系统，不同的文件系统有不同的特性，根据需要选择：

文件系统 | 特点
BTRFS | 非常强大的文件系统，具有稳定的表现和较高的容错率，还支持快照、分卷等高级特性。同时适用于 HDD 和 SSD
EXT4 | Linux 的老牌文件系统，中规中矩，兼容性最强，同时适用于 HDD 与 SSD
F2FS | 专为 SSD 优化的文件系统，可以充分发挥闪存性能，只能在 SSD 使用
JFS | 以日志为特色的文件系统，为面向事务的高性能系统开发，注重性能与可靠性，数据恢复能力强，主要面向企业
XFS | 适合高性能、高并发的存储，如果有数量庞大的设备同时读写 NAS 上的文件系统，则可考虑使用

首推 BTRFS，主要是看重它的灵活性、便利性与容错率。

注意：
OMV 创建文件系统，是将整块硬盘作为文件系统，没有分区表。
因此，如果打算拆下硬盘连接到 Windows 上读数据，那么系统是无法识别的。只能在 Linux 下手动进行挂载（使用sudo mount /dev/sdX）。

随后进入创建文件系统的界面。其中：

【介绍】这一栏，选择「Single」，表示只使用单个磁盘，不要创建磁盘阵列；
【设备】这一栏，则选择你要创建文件系统的磁盘。

确认后，OMV 就会立即开始格式化磁盘，随即自动打开「挂载」界面，以便立即挂载刚创建的这个文件系统。

4.10 设置「共享文件夹」
在挂载磁盘后，需要在 OMV 的「共享文件夹」管理器中，将已挂载文件系统上的文件夹作为一个「共享文件夹」来配置。有别于平时熟悉的 Windows 共享文件夹，OMV 的「共享文件夹」实际上是一个个映射：每个「共享文件夹」的条目，都会映射到文件系统上指定的一个文件夹。

共享文件夹的作用
在配置 SMB/CIFS、NFS 等传统的文件共享功能时，就可以在「共享文件夹」列表中选择一个条目，将其中的文件共享给网络中的设备。

与此同时，「共享文件夹」还可以用来给 OMV 其他的功能组件提供文件存储。为了防止用户更换磁盘导致路径失效，OMV 不允许功能组件使用绝对路径，只能使用设置好的「共享文件夹」。高阶的应用（如基于 Docker 的 openmediavault-compose 插件）需要你选择你配置好的「共享文件夹」来存储数据。

4.11 添加共享文件夹
第一步：在 OMV 的网页端管理界面中，依次点击「存储器」==>「共享文件夹」，会看到下面这个界面：

「共享文件夹」列表

第二步：点击工具栏上的「带圆圈的加号」按钮，进入「创建共享文件夹」界面。
【名称】：输入共享文件夹的名称，这是之后会在 Windows 的「网络（网上邻居）」等局域网共享工具中看到的名称。
【文件系统】：选择在「挂载文件系统」这一步中挂载好的文件系统。
【相对路径】：指定的是想把文件系统上的哪一个文件夹共享出去。要共享整个文件系统，就输入「/」（根目录）。
【权限】：保持默认即可（管理员可读写，用户可读写，其他只读）。

确认无误后，点击「保存」，提交更改。

4.12 设置权限
在使用 NAS 文件共享的过程中，可能会遇到以下两个麻烦：

无法写入文件，操作系统显示「权限不够」，即使用了正确的用户名和密码来访问共享文件夹；
访问共享文件夹时出错，无法进入，同样提示「权限不够」。
这种情况下，就需要正确地设置共享文件夹的权限。

第一步：选中要配置权限的共享文件夹，点击下图中箭头指向的按钮，打开「权限」设置面板。

点击箭头指向的按钮，以打开「权限」设置面板。
第二步：在「权限」设置面板中，OMV 会罗列设备上所有的用户，以及它们对该文件夹享有的权限。每个用户可以设置三种权限：
「Read/Write」：支持读写；
「Read-only」：只读；
「No access」：禁止访问。
以「robin」用户为例，如果想允许该用户读写该共享文件夹，那么点击「Read/Write」按钮即可。

在「权限」设置面板中，允许「robin」读写该共享文件夹。

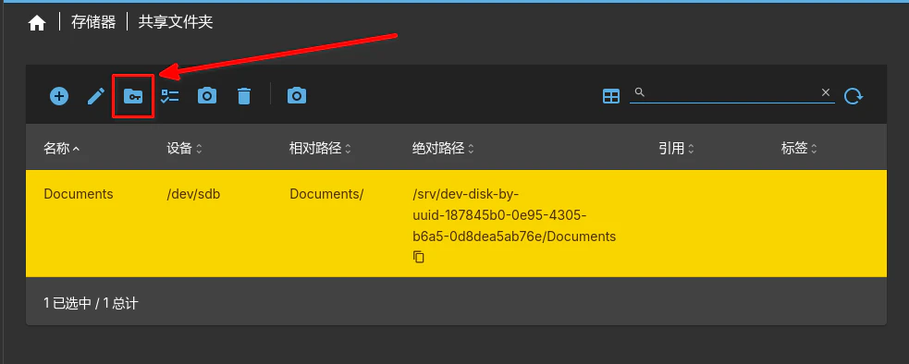
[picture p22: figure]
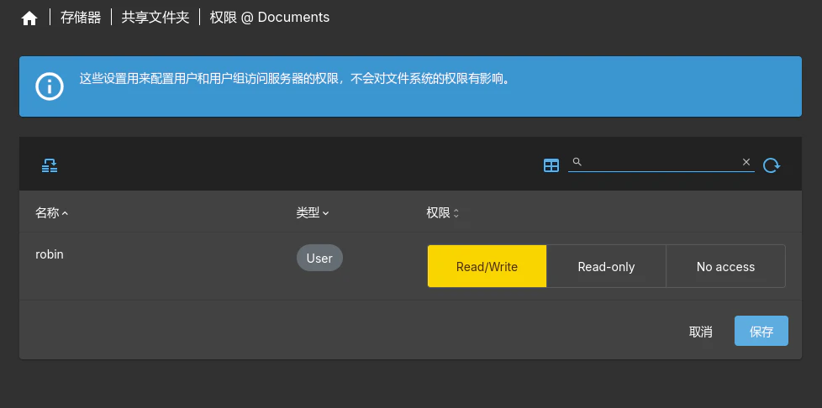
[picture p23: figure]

第三步：设置完成后，OMV 自动返回「共享文件夹」页面。此时依然会弹出黄色横幅，告知需要提交更改才能生效。

注意：
「权限」设置面板适用于采用 Linux 文件系统的共享文件夹，如 Ext4、BtrFS、XFS 等。
对于 NTFS、exFAT 等 Windows 文件系统，即使不设置权限也不影响用户读写文件，在用户通过 SMB/CIFS 匿名访问共享文件夹时也是如此。

后续维护
共享文件夹不是一成不变的。OMV 允许用户在创建共享文件夹后，随时修改其指向的文件系统和相对路径。

例如，用户配置了一个名为「多媒体」的共享文件夹，「文件系统」设为一块 2 TB 的磁盘 /dev/sda。后来你购入了一块 4 TB 的硬盘，创建为/dev/sdb这个文件系统，那么就可以在「共享文件夹」界面中选中「多媒体」文件夹，点击工具栏上的「铅笔」按钮进入编辑界面，随后将「文件系统」设为 /dev/sdb 即可。

4.13 配置文件共享协议（SMB/CIFS）
使用 NAS，最主要的用途应该就是文件共享了。

最为常用的局域网文件共享协议就是 SMB/CIFS，是 Windows 默认采用的文件共享协议，配置灵活，支持各种高级特性。后来，SAMBA 项目让该协议实现了跨平台，现在可在 macOS、Linux、Android 等平台中使用。

优先推荐使用 SMB/CIFS 的：一方面，OMV 默认支持该协议，开箱即用；另一方面，Windows 原生支持，加之 Linux、Android 等平台都有软件支持该协议，极大降低了不同平台设备访问 NAS 的门槛。

启用 SMB/CIFS
OMV 预装了 SMB/CIFS 的支持。在左侧导航栏中，依次展开「服务」>「SMB/CIFS」>「设置」，打开 SMB/CIFS 的全局设置：

只需要打开上面的「已启动」开关即可，其他选项保持默认值不用更改。

随后，勾选最上面的「已启动」复选框，其余设置保持默认值即可。然后将网页拉到底部，点击「确认」，随即按提示提交更改，即可启动 SMB 服务。

将共享文件夹添加到 SMB/CIFS 的共享列表中
在 OMV 中，无论是哪种文件共享协议，在上一章创建的「共享文件夹」都不会自动共享给网络上的设备；只有在这些文件共享协议中，手动将共享文件夹加入其中。SMB/CIFS 就是如此。

第一步：在左侧导航栏中，依次展开「服务」>「SMB/CIFS」>「共享」，打开 SMB/CIFS 的文件夹共享列表。

上图展示已经配置的 5 个共享文件夹。

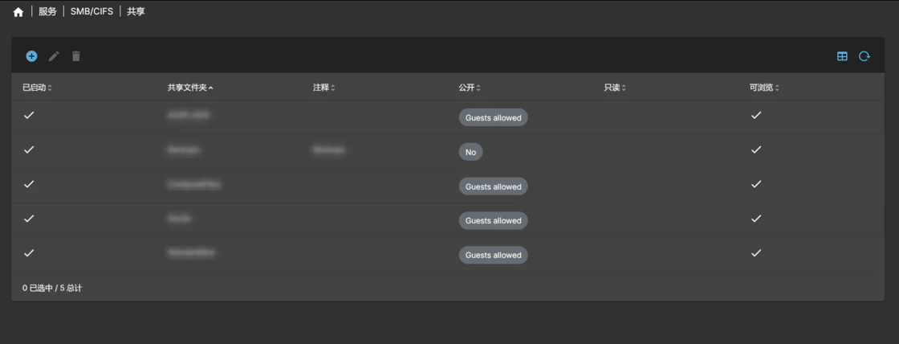
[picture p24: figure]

第二步：点击工具栏上的「带圆圈加号」按钮，开始添加共享，会看到如下的界面：

「创建共享文件夹」页面

第三步：点击「共享文件夹」，会列出用户设置的所有共享文件夹。可以在这里选择想要共享的文件夹。
第四步：设置可访问性。在「公开」这个参数中，可以指定是否让未登录用户（即访客）在文件管理器输入你的主机地址时，看到共享的文件夹。

支持的选项有以下三种，根据你的实际需求选择：
「否」：只有用正确的账户登录的用户才能看到，对访客是不可见的。适用于需要保护、只允许授权访问的文件夹。
「允许访客」：访客可以看到，适用你希望与局域网的电脑公开共享的文件夹。
「仅访客」：访客可以看到，并且无论是否用账户登录，所有的访问都是以访客的名义。适用于非重要的文件，或者是需要临时在局域网里共享的文件，因为这种方式不能保证安全性。
第四步：根据实际情况，还可以修改以下参数。其余参数保持默认值即可。

参数名 | 说明
只读 | 启用后，用户将无法创建或修改共享中的文件，只能在 OMV 上修改
启用回收站 | 默认情况下，在 Windows 中删除共享文件夹上的文件时，是会彻底删除的。打开该选项可以启用「回收站」，防止误删文件
传输加密 | 只允许支持加密的客户端存取共享文件夹，可以保证数据安全
存储 DOS 属性 | 打开此项，可以让 OMV 兼容与存储 DOS/Windows 文件系统的扩展属性（系统、只读、隐藏、存档）。如果你使用的系统以 Windows 为主，且有软件依赖于这些属性，可以考虑启用
允许主机和拒绝主机 | 白名单和黑名单，可以允许或拒绝特定的主机访问这个共享文件夹。留空则为默认值

第五步：设置完成后，弹出黄色横幅，告知我们需要提交更改才能生效。

# 5 附录参考

1　 OMV的自带服务中还提供了NFS、RSync、SSH等服务，可以参考https://docs.openmediavault.org/en/8.x/features.html#services进行配置
2　 Raid和Gossa插件的安装使用另文说明

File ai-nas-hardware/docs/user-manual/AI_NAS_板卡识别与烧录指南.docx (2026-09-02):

EIC7700 AI NAS 板卡识别与烧录指南

硬件识别 · 启动模式 · 烧录流程 · 常见问题

文档定位

本文档面向开发板调试、烧录和基础验收场景，用于快速识别接口、设置拨码、完成 boot/root 镜像烧录，并对常见问题给出处理路径。

适用对象：硬件调试人员、软件测试人员、现场支持人员。

文档范围：本文档用于说明 EIC7700 AI NAS 板卡接口识别、启动拨码、镜像烧录、串口连接、软件包安装与常见问题处理。

# 目录

1. 硬件接口识别

2. 启动模式与拨码设置

3. 烧录流程

4. Windows 串口驱动与工具

5. 软件包安装与基础功能检查

6. 扩展测试项目与性能验证

7. 已知问题与 FAQ

# 1.1 关键接口说明——正面

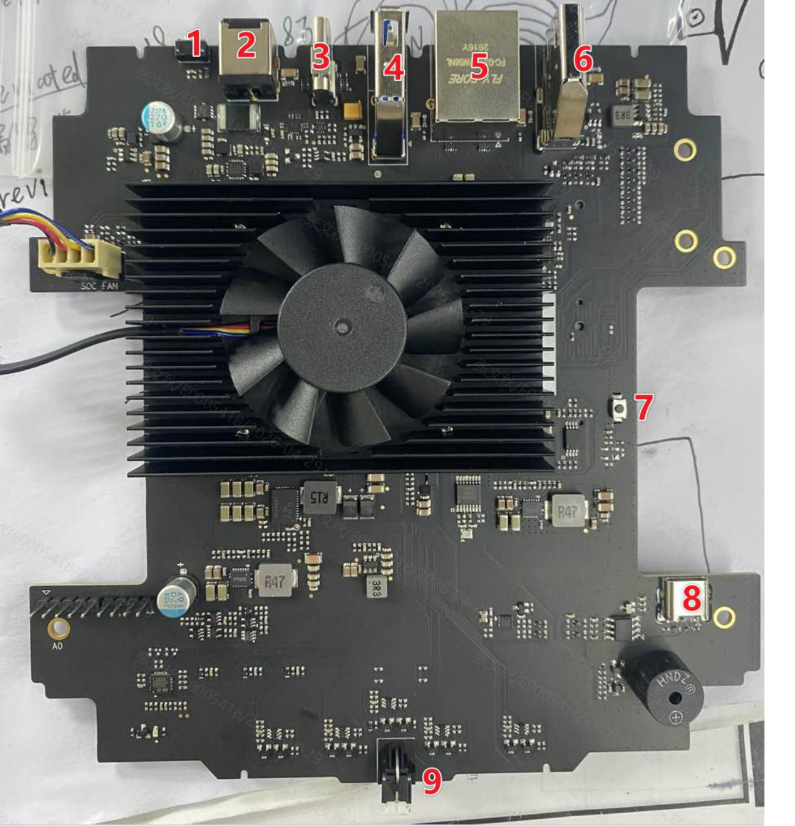
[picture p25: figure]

| 正面接口速查 编号 接口/按键 用途说明 1 恢复出厂设置 恢复板卡出厂配置，操作前需确认不会影响当前环境。 2 DC 电源接口 连接外部 DC 电源适配器。 3 USB0 Type-C 接口（Host Only） USB 烧录/连接电脑时优先确认此接口。 4 USB1 Type-A 接口（Host Only） 连接 U 盘、键鼠等 USB 外设。 5 千兆网口 用于有线网络、SSH 登录、网络连通性验证。 6 HDMI 2.0 接口 连接显示器，验证图形界面与分辨率。 7 复位按键 系统异常或烧录完成后可用于 reset 重启。 8 Debug UART 转 USB Type-C 接口 串口调试接口，用于查看启动日志和进入 U-Boot。 9 电源开关 按下后上电启动；长按可用于关机/重启场景。

# 1.2 关键接口说明——背面

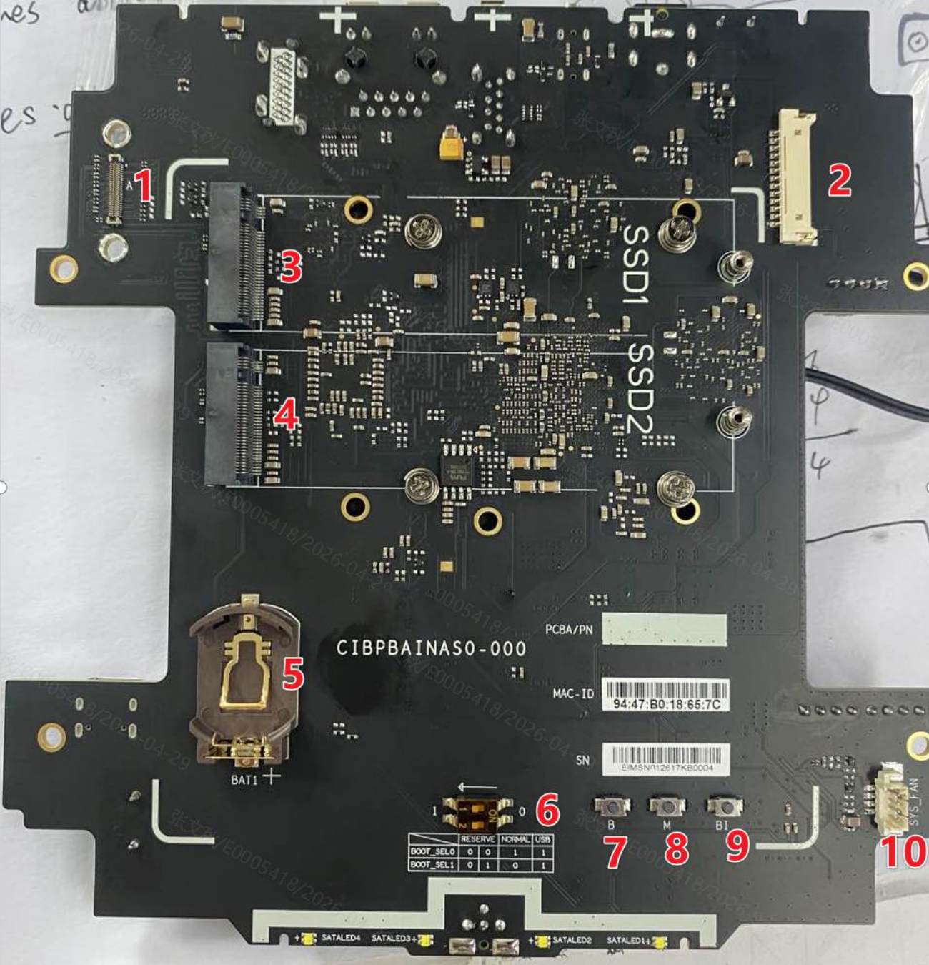
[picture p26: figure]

| 背面接口速查 编号 接口/按键 用途说明 1 背板高速信号连接器 连接背板高速信号。 2 背板电源连接器 连接背板供电。 3 NVMe 接口 连接 NVMe SSD，用于存储或系统盘测试。 4 NVMe 接口 第二路 NVMe 接口。 5 RTC 电池接口 连接 RTC 电池。 6 BOOT MODE 切换拨码开关 用于切换 USB 烧录、SPI 启动等启动模式。 7 用户自定义 GPIO 按键 用户按键，可结合驱动/应用验证。 8 用户自定义 GPIO 按键 用户按键，可结合驱动/应用验证。 9 用户自定义 GPIO 按键 用户按键，可结合驱动/应用验证。 10 机壳风扇连接器 连接机壳风扇。

# 2. 启动模式与拨码设置

使用原则

调整 BOOT_SEL0/BOOT_SEL1 前请断电；完成烧录后按目标启动模式恢复拨码，再通过 reset 或电源键重启。
模式 | BOOT_SEL0 | BOOT_SEL1 | 操作说明
USB 烧录模式 | 1 侧 | 1 侧 | 电脑连接 USB0 Type-C 接口后上电；主机侧出现 WIN2030 磁盘，用于复制启动文件。
SPI 启动模式 | 0 侧 | 1 侧 | 插入电源并按电源键，等待串口打印启动日志。

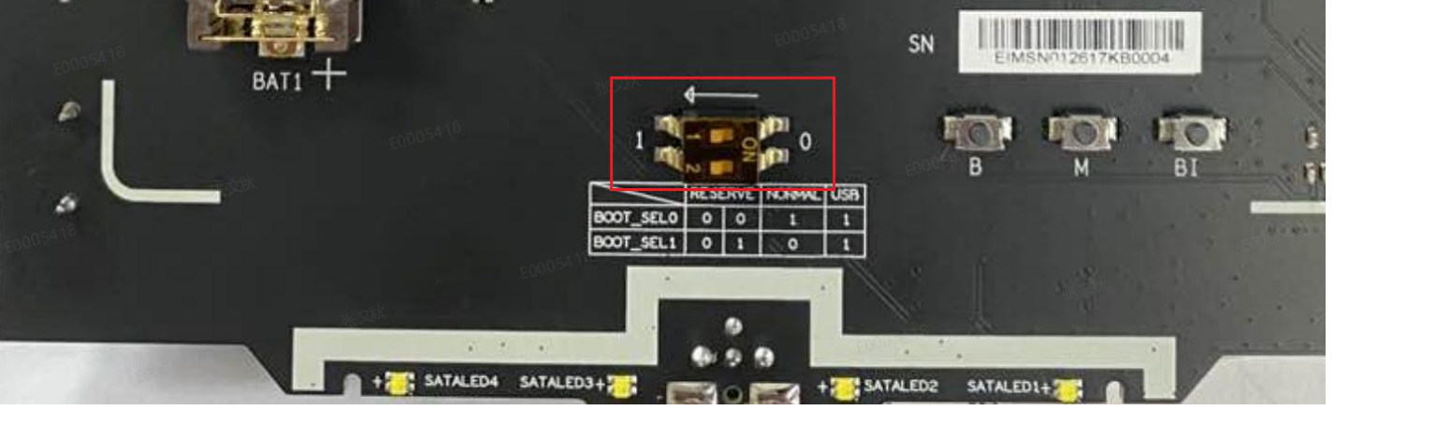
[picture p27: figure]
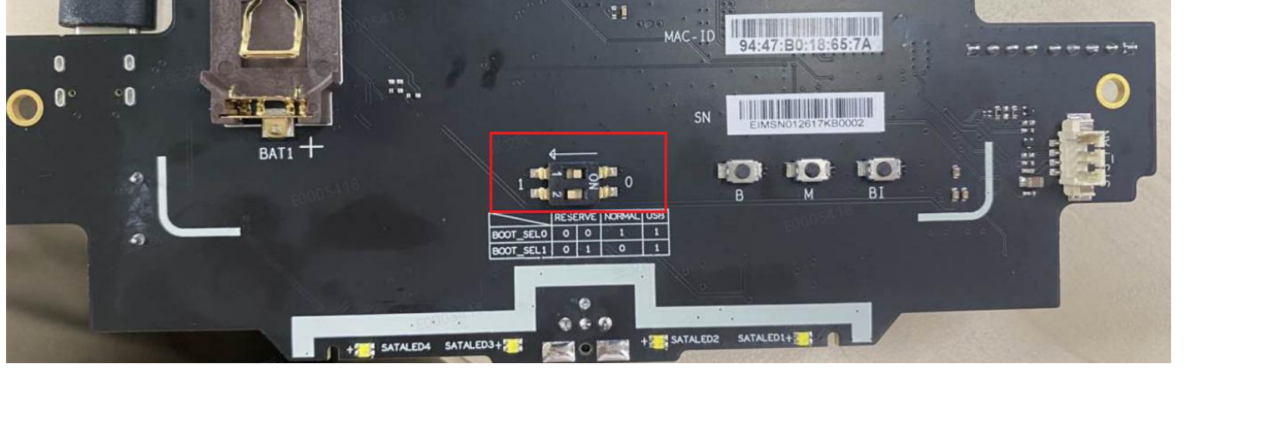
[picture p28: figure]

USB 烧录模式示意 BOOT_SEL0=1，BOOT_SEL1=1 | SPI 启动模式示意 BOOT_SEL0=0，BOOT_SEL1=1

# 2.1 如何进入 USB 烧录模式

| 操作步骤 - 将 BOOT_SEL0 与 BOOT_SEL1 均拨至 1 侧。 - 电脑连接板卡 USB0 Type-C 接口。 - 插入电源并按下电源键；主机侧出现 WIN2030 磁盘后，将启动文件复制到该磁盘。 - 等待串口打印，观察 DDR Training 结果。 项目 BOOT_SEL0 BOOT_SEL1 拨码位置 1 侧 1 侧 注意：DDR Training PASS 后蜂鸣器响一声；Training Fail 时蜂鸣器间隔响 5 次。

# 2.2 如何进入 SPI 启动模式

| 操作步骤 - 将 BOOT_SEL0 拨至 0 侧，BOOT_SEL1 拨至 1 侧。 - 插入电源并按下电源键。 - 通过串口工具观察启动日志。 项目 BOOT_SEL0 BOOT_SEL1 拨码位置 0 侧 1 侧 注意：DDR Training PASS 后蜂鸣器响一声；Training Fail 时蜂鸣器间隔响 5 次。

# 3. 烧录流程

适用场景

Bootloader 烧录分为 ：
1、recover 自动模式烧录 （通过主机/USB/U-Boot 升级 boot 与 root 文件系统镜像的流程。首次烧录、正常升级、bootloader 被破坏后的恢复均应按现场状态选择对应步骤。）

2、usb 手动烧录（适用于非首次烧录bootloader ，uboot 正常可以进入的 可直接跳转到3.3章节）

## 3.1 烧录准备与主机侧识别

第一步是需要拨码将设备变成usb 模式如下图

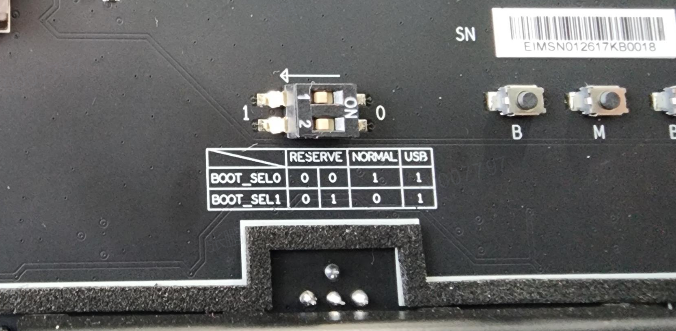
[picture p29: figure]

图 3-1：USB 烧录模式拨码示意（BOOT_SEL0=1，BOOT_SEL1=1）

在 Linux 主机上连接板卡后，可通过 lsblk 观察新出现的设备，例如 /dev/sdb。请务必确认设备号，避免误操作主机系统盘。

第二步与主机相连 使用type c 线缆（一端 type c 一端 usb即可）

USB 模式下，Type-C 线缆需要连接到主机，用于主机侧识别 WIN2030 磁盘并拷贝烧录文件。

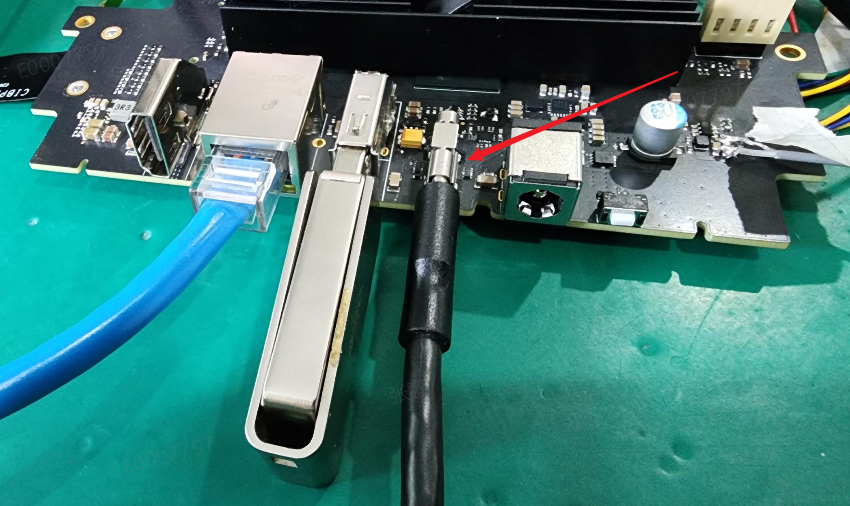
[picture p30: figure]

图 3-2：USB 模式 Type-C 线缆连接主机拷贝文件

图 3-3：Linux 主机侧识别到 /dev/sdb 示例

第三步 recover 模式烧录过程（举例为对端为linux 主机 如windows 主机 需要 CH347 串口驱动 ）

# 示例：挂载板卡枚举出来的磁盘

mkdir -p ~/sdb

sudo mount /dev/sdb ~/sdb

# 示例：复制 recovery bootloader 文件

sudo cp -r recovery_nsign_bootloader_secboot_ddr.bin ~/sdb/

sync

sudo umount ~/sdb

风险提示

上面的 /dev/sdb 仅为示例。实际环境中请先通过 lsblk -f、dmesg | tail 或容量信息确认设备，避免把文件复制到错误磁盘。

# 3.2 recovery bootloader 烧录成功后处理

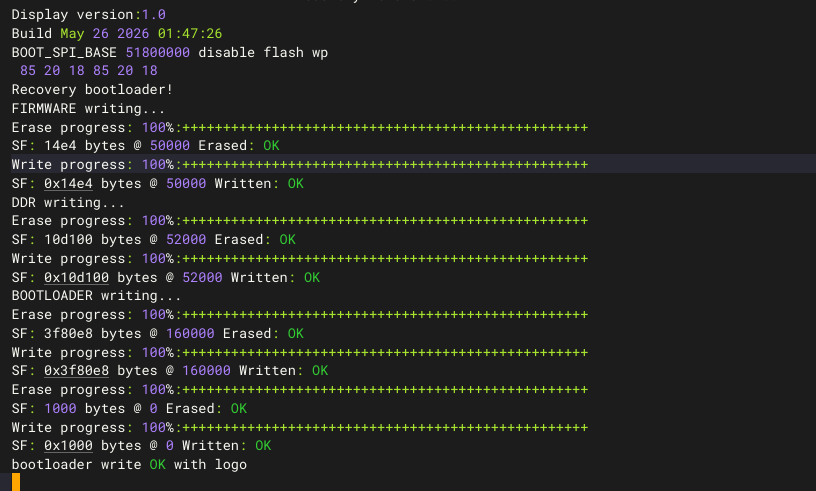
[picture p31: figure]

图 3-4：bootloader 写入 OK 示例

烧录成功后，将拨码恢复为目标启动模式；若需从 SPI 启动，请将 BOOT_SEL0 拨至 0 侧、BOOT_SEL1 拨至 1 侧，然后点击板卡正面的 reset 按键（正面编号 7），或长按电源按钮重启。

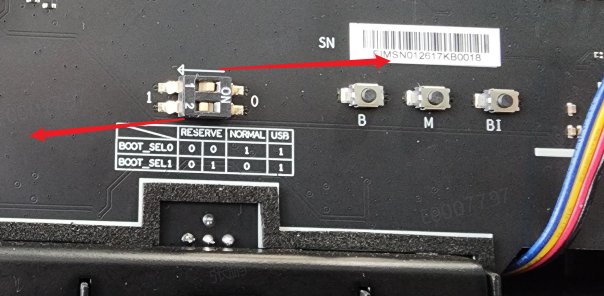
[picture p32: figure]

图 3-5：烧录完成后拨码恢复与 reset 示例

# 3.3 进入 U-Boot 并继续烧录系统

设备启动过程中，在串口出现对应启动信息时按 Ctrl + C，可打断启动流程并进入 U-Boot 命令行。

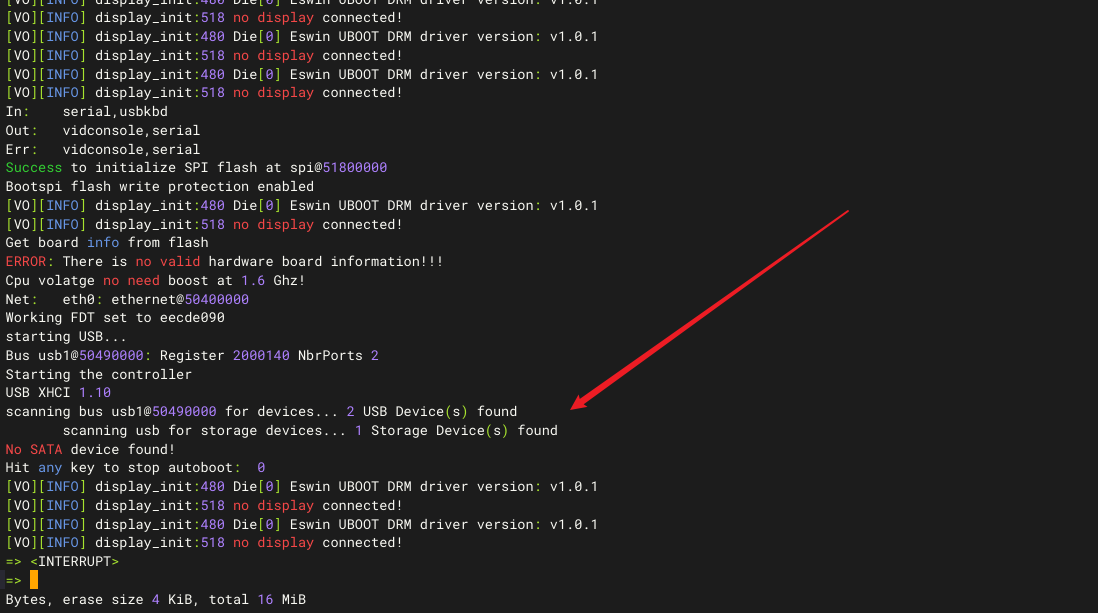
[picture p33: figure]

图 3-6：启动过程中按 Ctrl + C 进入 U-Boot 示例

## U 盘文件准备

- nsign_bootloader_secboot_ddr.bin （示例文件名，按实际版本替换）
- recovery_nsign_bootloader_secboot_ddr.bin （示例文件名，按实际版本替换）
- boot-eic7700-ai-nas-20260515-063302.ext4（示例文件名，按实际版本替换）
- root-eic7700-ai-nas-20260515-063302.ext4（示例文件名，按实际版本替换）

补充说明：USB 盘烧录时，将准备好的 U 盘接入下图箭头所示位置；进入 U-Boot 后按实际目录与文件名执行后续烧录命令。

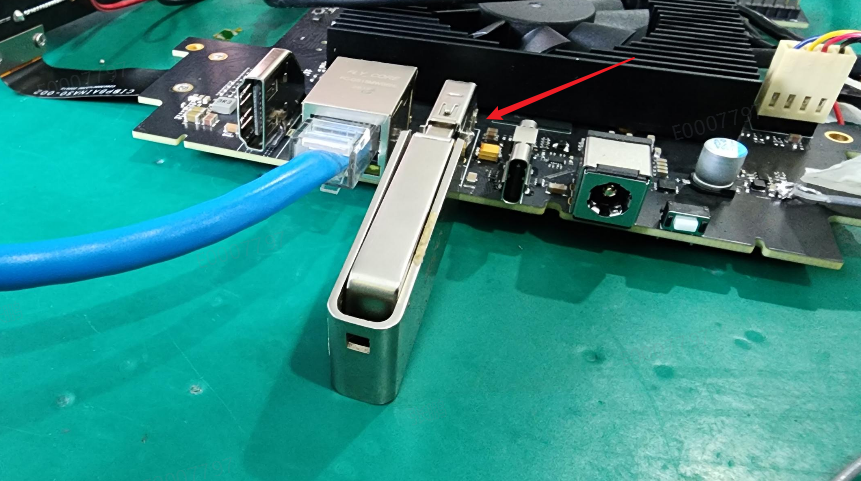
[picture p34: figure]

图 3-7：USB 盘烧录 U 盘接入位置

## U-Boot 烧录命令

setenv stdout serial

ext4load usb 0 0x100000000 0526bootloader/nsign_bootloader_secboot_ddr.bin

es_burn write 0x100000000 flash

es_fs update usb 0 boot-eic7700-ai-nas-20260515-063302.ext4 mmc 0:1

es_fs update usb 0 root-eic7700-ai-nas-20260515-063302.ext4 mmc 0:3

命令说明

setenv stdout serial 用于降低串口粘贴命令时丢字符的概率；0526bootloader 是 U 盘中的目录名示例，实际执行时需按真实目录调整。

# 3.4 烧录过程截图与完成确认

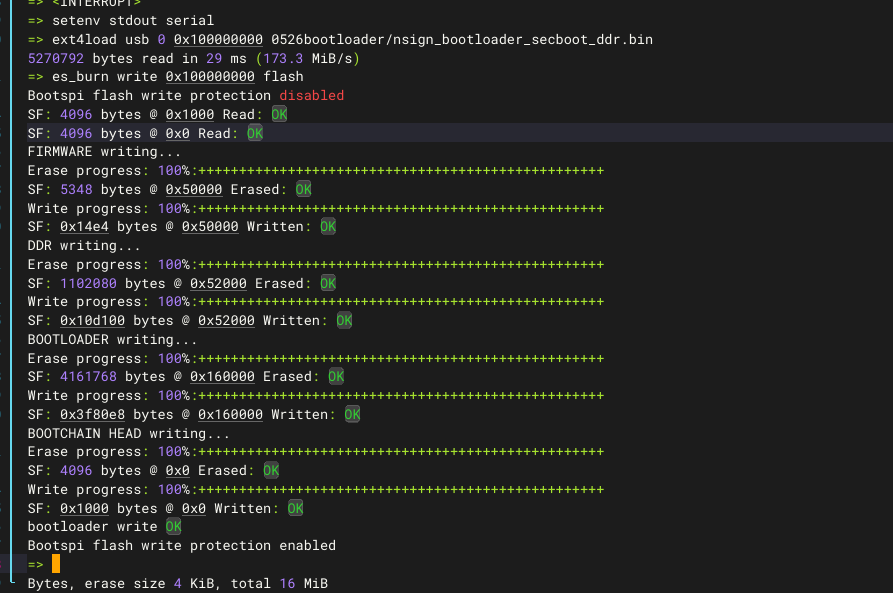
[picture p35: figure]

图 3-8：U-Boot 中执行 bootloader 写入示例

当 boot、root 文件系统镜像均显示写入成功后，输入 reset 重启系统，完成整套烧录流程。

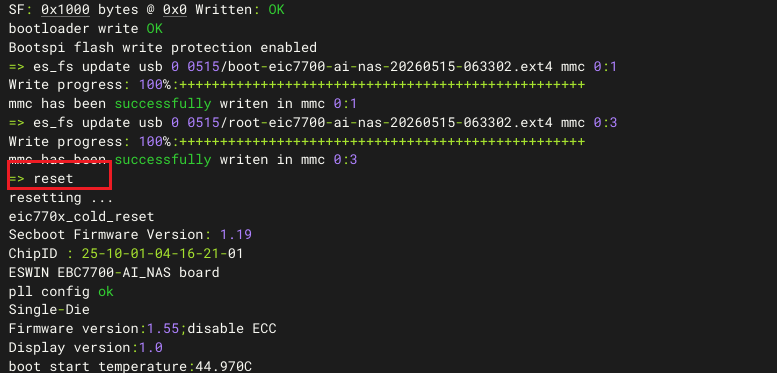
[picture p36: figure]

图 3-9：boot/root 文件系统写入成功并 reset 示例

## 烧录完成后的基本确认

- 串口日志中无明显 bootloader/kernel panic 或文件系统挂载失败。
- U-Boot 日志中的编译时间与本次烧录版本一致。
- 内核启动日志中的版本时间与镜像包一致。
- 系统可正常登录，网络、USB、存储设备均可识别。

# 4. Windows 串口驱动与 MobaXterm 配置

Windows 系统首次连接该板卡时，可能需要安装 CH347 串口驱动。安装完成后重新连接串口线，并使用 MobaXterm 打开串口会话。

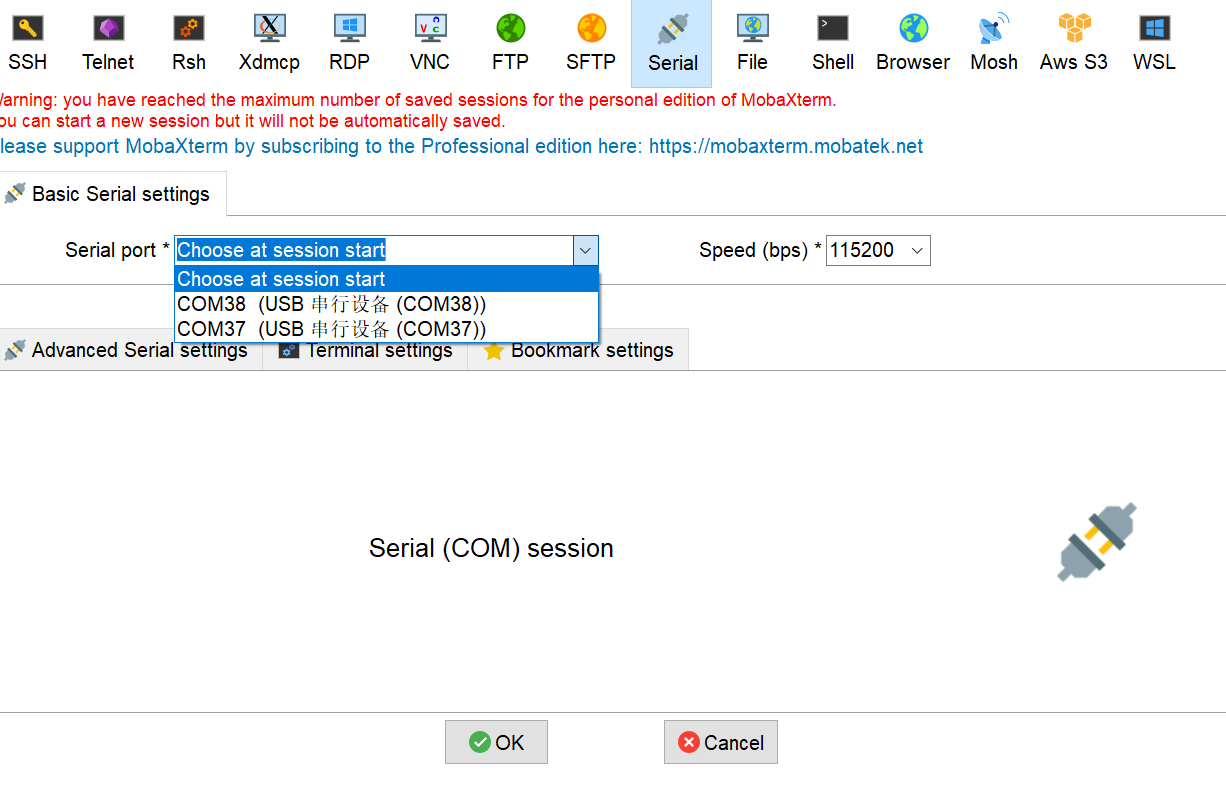
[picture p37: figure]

图 4-1：MobaXterm 串口会话配置示例

1. 安装 CH347SER.EXE 串口驱动。
2. 通过 Debug UART Type-C 接口重新连接板卡与计算机。
3. 打开 MobaXterm，选择 Serial 会话。
4. 选择对应 COM 口，波特率建议使用 115200。
5. 进入串口后，按本文档烧录或启动流程继续操作。

# 5. 软件包安装与基础功能检查

## 5.1 Deb 包安装

官方可提供基础 deb 包，例如 es-sdk-npu、es-sdk-video、es-sdk-ak 等，用于启用 NPU、视频、音频等基础软件能力。

# 1. 本地 deb 安装（可下载到板卡，或通过 U 盘复制到板卡）

sudo dpkg -i ./*.deb

# 2. 如出现依赖问题或 iU 状态，执行依赖修复

sudo apt --fix-broken install -y

# 3. 配置所有已解包但未配置完成的软件包

sudo dpkg --configure -a

# 4. 检查是否仍有异常包

sudo dpkg --audit

## 5.2 基础项目检查表

模块 | 分类 | 测试项 | 结果 | 备注
M1 | 启动&基础能力 | 镜像烧录成功 | Pass
M1 | 启动&基础能力 | bootloader.bin 烧录并启动成功 | Pass
M1 | 启动&基础能力 | recovery_bootloader 烧录并启动成功 | Pass
M1 | 启动&基础能力 | 系统正常启动 | Pass
M1 | 启动&基础能力 | 登录正常 | Pass
M1 | 启动&基础能力 | uname 正确 | Pass
M1 | 启动&基础能力 | 有线网络可用 | Pass
M1 | 启动&基础能力 | USB 识别正常 | Pass
M1 | 启动&基础能力 | 存储挂载正常（SATA/eMMC/PCIe） | Pass
M1 | 启动&基础能力 | 图形界面正常 | Pass
M1 | 启动&基础能力 | 分辨率正常 | Pass
M1 | 启动&基础能力 | 鼠标/键盘正常 | Pass

## 5.3 sys 频率及电压检查

根据当前板卡基础验收记录，补充 sys 类频率及电压检查项；该项用于确认默认电压、CPU/NPU 最高频率是否符合版本规格。

case | description | Note
sys | 频率及电压检查，默认是以下规格 cpu_vdd：0.8V soc_vdd：0.8V ddr_vdd：0.8V cpu max frequency：1.4G NPU_VDD：0.8V | NPU_VDD 待机 0.7V、运行 0.8V 之后 要改成 待机也是0.8V（修改验证中，之后的版本会有体现）

# 6. 扩展测试项目与性能验证

本章节整理本次新增的板卡存储兼容性、RAID0 多盘 FIO 场景及 UnixBench 基础性能验证结果，用于补充前述烧录和基础功能检查结论。

## 6.1 存储介质兼容性与基础 FIO 验证

已覆盖机械硬盘、SATA SSD、M.2/NVMe SSD 及其他存储介质。测试内容以基础 FIO 读写验证为主，当前未观察到读写异常或设备识别异常。

序号 | 存储型号 | 类型 | 测试内容 | 结果
1 | TOSHIBA HDWG740UZSVC | 机械硬盘 | 基础 FIO 读/写验证 | 未见异常
2 | SK hynix BC511 HFM256GDJTNI-82A0A | M.2 SSD | 基础 FIO 读/写验证 | 未见异常
3 | Fanxiang S500Pro 256GB | M.2 SSD | 基础 FIO 读/写验证 | 未见异常
4 | Fanxiang S690 500GB | M.2 SSD | 基础 FIO 读/写验证 | 未见异常
5 | U330 | Usb 存储设备 | 基础 FIO 读/写验证 | 未见异常
6 | HP SSD S650 240GB | SATA SSD | 基础 FIO 读/写验证 | 未见异常
7 | Samsung SSD 870 EVO 250GB | SATA SSD | 基础 FIO 读/写验证 | 未见异常
8 | WD Green 2.5 240GB | SATA SSD | 基础 FIO 读/写验证 | 未见异常
9 | J.ZAO 5 SERIES 256GB SSD | SSD | 基础 FIO 读/写验证 | 未见异常
10 | SAMSUNG MZQLB960HBJR-00W07 | NVMe SSD | 基础 FIO 读/写验证 | 未见异常
11 | ZHITAI Ti600 1TB | NVMe SSD | 基础 FIO 读/写验证 | 未见异常

## 6.2 多盘 FIO 与 RAID0 验证

在系统中安装 mdadm 后，使用 4 块 SATA/SCSI 盘与 2 块 NVMe 盘组成 6 盘 RAID0，用于多盘并发读写和大容量存储验证。

sudo apt install -y mdadm
cat /proc/mdstat
sudo mdadm --detail /dev/md0
检查项 | 结果
RAID 级别 | RAID0
阵列设备 | /dev/md0
成员盘 | /dev/sda、/dev/sdb、/dev/sdc、/dev/sdd、/dev/nvme0n1、/dev/nvme1n1
阵列容量 | 15.24 TiB / 16.76 TB
Chunk Size | 512K
阵列状态 | clean
Active / Working / Failed Devices | 6 / 6 / 0
测试结论 | 6 盘 RAID0 建组成功，成员盘均为 active sync，基础多盘 FIO 读写未见异常

### 6.2.1 RAID0 FIO 性能测试汇总（表格已直接嵌入）

以下内容来自《RAID0_fio性能测试汇总》表格，已转换为 Word 表格直接插入到 6.2 之后，作为多盘 RAID0 验证的补充数据。

表 6-2-1 RAID0 FIO 核心指标汇总

项目 | 结果 | 说明
RAID挂载点 | /raid0 | 测试基于文件系统 /raid0/fio_raid0_full_test.bin
RAID设备 | /dev/md0 | 6盘 RAID0：4块 SATA HDD + 2块 NVMe
测试时长 | 60s / case | 本次上传日志为 60s/case；
顺序只写 | 1637 MiB/s | 1M block，write
顺序只读 | 1189 MiB/s | 1M block，read
顺序读写合计 | 922 MiB/s | 50:50，读+写合计
随机只写 | 12.50 MiB/s / 3211 IOPS | 4K randwrite
随机只读 | 4.32 MiB/s / 1105 IOPS | 4K randread
整体状态 | 7/7 PASS | 各 case ret=0，err=0

表 6-2-2 RAID0 FIO Case 明细：基础信息与执行状态

序号 | Case ID | 测试项 | 类型 | rw | bs | 读比例% | 写比例% | 时长(s) | ret | err | 状态
1 | 01_seq_write_1M | 顺序只写 | 顺序 | write | 1M | 0 | 100 | 60.131 | 0 | 0 | PASS
2 | 02_seq_read_1M | 顺序只读 | 顺序 | read | 1M | 100 | 0 | 60.088 | 0 | 0 | PASS
3 | 03_seq_rw_1M_50_50 | 顺序读写 50:50 | 顺序 | rw | 1M | 50 | 50 | 60.227 | 0 | 0 | PASS
4 | 04_randwrite_4K | 随机只写 | 随机 | randwrite | 4K | 0 | 100 | 60.024 | 0 | 0 | PASS
5 | 05_randread_4K | 随机只读 | 随机 | randread | 4K | 100 | 0 | 60.211 | 0 | 0 | PASS
6 | 06_randrw_4K_50_50 | 随机读写 50:50 | 随机 | randrw | 4K | 50 | 50 | 60.119 | 0 | 0 | PASS
7 | 07_randrw_4K_30_70 | 随机读写 3:7 | 随机 | randrw | 4K | 30 | 70 | 60.117 | 0 | 0 | PASS

表 6-2-3 RAID0 FIO Case 明细：性能数据

序号 | Case ID | 测试项 | 读BW(MiB/s) | 写BW(MiB/s) | 总BW(MiB/s) | 读IOPS | 写IOPS | 总IOPS | 读IO量(GiB) | 写IO量(GiB) | 状态
1 | 01_seq_write_1M | 顺序只写 | | 1637 | 1637 | | 1637 | 1637 | | 96.1 | PASS
2 | 02_seq_read_1M | 顺序只读 | 1189 | | 1189 | 1188 | | 1188 | 69.8 | | PASS
3 | 03_seq_rw_1M_50_50 | 顺序读写 50:50 | 458 | 464 | 922 | 457 | 463 | 920 | 26.9 | 27.3 | PASS
4 | 04_randwrite_4K | 随机只写 | | 12.5 | 12.5 | | 3211 | 3211 | | 0.735 | PASS
5 | 05_randread_4K | 随机只读 | 4.319 | | 4.319 | 1105 | | 1105 | 0.254 | | PASS
6 | 06_randrw_4K_50_50 | 随机读写 50:50 | 3.448 | 3.465 | 6.913 | 882 | 887 | 1769 | 0.202 | 0.203 | PASS
7 | 07_randrw_4K_30_70 | 随机读写 3:7 | 2.576 | 6.008 | 8.584 | 659 | 1537 | 2196 | 0.151 | 0.353 | PASS

表 6-2-4 测试环境与 RAID 配置

配置项 | 值 | 备注
测试目录 | /raid0 | RAID0 挂载目录
测试文件 | /raid0/fio_raid0_full_test.bin | fio 文件测试路径
测试时长 | 60s / case | 本次日志记录
测试大小 | 80G | fio size 参数
ioengine | posixaio | 板端 fio 使用 posixaio
iodepth | 32 | 队列深度
numjobs | 8 | 并发 job 数
文件系统容量 | 16T / 已用 41G / 可用 15T | df -h /raid0

表 6-2-5 RAID0 成员盘清单

设备 | 型号 | 容量 | 接口 | 挂载/归属
sda | TOSHIBA HDWG740UZSVC | 3.6T | sata | /raid0
sdb | TOSHIBA HDWG740UZSVC | 3.6T | sata | /raid0
sdc | TOSHIBA HDWG740UZSVC | 3.6T | sata | /raid0
sdd | TOSHIBA HDWG740UZSVC | 3.6T | sata | /raid0
nvme0n1 | Fanxiang S500Pro 256GB | 238.5G | nvme | /raid0
nvme1n1 | Fanxiang S690 500GB | 465.8G | nvme | /raid0

表 6-2-6 RAID0 FIO 测试结论与说明

序号 | 结论/说明
1 | 本次 RAID0 已正常挂载到 /raid0，df 显示 /dev/md0 容量约 16T。
2 | 顺序吞吐表现：顺序只写约 1637 MiB/s，顺序只读约 1189 MiB/s，顺序 50:50 读写合计约 922 MiB/s。
3 | 随机 4K 表现明显低于顺序场景，主要受机械盘随机寻道、HDD 与 NVMe 混合 RAID0 调度影响。
4 | 随机 4K 30:70 读写总 IOPS 高于 50:50，主要因为写侧占比更高，写 IOPS 为 1537。
5 | 所有 7 个 fio case 均 ret=0 且 err=0，说明本次测试过程中未出现 fio 执行失败。
6 | 当前仅仅验证多盘能否做raid ，后续将 4 块 SATA HDD RAID0 与 2 块 NVMe RAID0 分开测试，不会混合成一个 RAID0 直接做峰值性能结论。

表 6-2-7 Case 样本与结果统计

Case ID | 测试项 | read样本数 | write样本数 | 最终err | 最终ret
01_seq_write_1M | 顺序只写 | 0 | 62 | 0 | 0
02_seq_read_1M | 顺序只读 | 61 | 0 | 0 | 0
03_seq_rw_1M_50_50 | 顺序读写 50:50 | 61 | 61 | 0 | 0
04_randwrite_4K | 随机只写 | 0 | 61 | 0 | 0
05_randread_4K | 随机只读 | 61 | 0 | 0 | 0
06_randrw_4K_50_50 | 随机读写 50:50 | 61 | 61 | 0 | 0
07_randrw_4K_30_70 | 随机读写 3:7 | 61 | 61 | 0 | 0

## 6.3 UnixBench 基础性能验证

UnixBench 用于评估系统基础 CPU/进程/文件等综合性能。本次记录单进程与多进程两组结果，用于版本基线对比。

测试项目 | 测试结果 | 说明
UnixBench 单进程 | 466.0 | 反映单任务基础性能
UnixBench 多进程 | 1535.3 | 反映多核并行场景综合能力

## 6.4 新增测试结论

类别 | 结论
存储兼容性 | 已测试 1 款机械硬盘，以及 SATA SSD、M.2/NVMe SSD 等共 10 款 SSD/存储设备，基础 FIO 读写未见异常。
多盘 RAID0 | 6 盘 RAID0 状态 clean，所有成员盘 active sync，Failed Devices 为 0。
基础性能 | UnixBench 单进程 466.0，多进程 1535.3，可作为后续版本性能回归对比基线。

# 7. 已知问题与 FAQ

## 7.1 Known Issues

编号 | 问题描述 | 当前状态 | 建议处理
1 | 休眠唤醒问题 | 解决中 | 跟踪新版本修复情况，并保留复现日志。
2 | NPU 执行异常 | 待 5 月 26 日版本迭代修复 | 使用新版本镜像/软件包复测，重点关注 NPU 初始化、模型加载和驱动错误日志。

## 7.2 FAQ

Q：如何熟悉 U-Boot 相关功能？

A：在 U-Boot 命令行输入 help 可查看命令列表；单个命令也可通过 help <cmd> 查看详细帮助信息。

Q：网络不通怎么办？

A：先确认接入网络有权限；再通过 print 查看 ethaddr 等 MAC 地址参数是否存在。如无 MAC，可使用 env set ethaddr aa:bb:cc:11:22:33 设置并 saveenv 保存。EBC7702 多网口场景还需设置 eth1addr/eth2addr/eth3addr 等。

Q：串口粘贴长度受限，后半段命令丢失怎么办？

A：先执行 setenv stdout serial，可减少 HDMI 输出对粘贴/显示的影响；注意该命令会让 U-Boot 输出只走串口。

Q：烧录后启动报错怎么办？

A：旧版本环境变量可能残留。烧录 bootloader 后 reset，进入 U-Boot 执行 env default -a 清除旧配置，再 saveenv 保存。注意该动作会清除手动添加的环境变量。

Q：烧录报分区不存在或分区太小怎么办？

A：先执行 mmc part 查看分区信息。确认 bootloader 正确后，可 reset 进入 U-Boot，执行 env default -a、saveenv、reset，再执行 run gpt_partition 重新分区。

Q：默认分区大小不够，如何重新分区？

A：print 查看 partitions 参数，使用 edit partitions 或 env set partitions 重新设置后，执行 run gpt_partition 重新分区。

Q：如何确认镜像确实烧录进去了？

A：观察 U-Boot 启动日志中的编译时间，以及内核启动日志中的内核编译时间，与本次镜像包时间进行比对。

Q：SD 和 eMMC 都有系统时如何从 SD 启动？

A：当前环境使用 UUID 标识文件系统，可能需要擦除 eMMC 数据以避免优先从 eMMC 启动，例如 mmc erase 0 0xa00000。操作前务必确认设备编号，避免误擦。

Q：U-Boot 支持设备热插拔吗？

A：USB 热插拔后需要执行 usb reset 重新扫描；SD 卡不支持热插拔。

# 附录 A：RAID0 创建与挂载步骤完整记录

本附录将 RAID0 创建、磁盘确认、旧签名清理、阵列创建、格式化、挂载、mdadm 持久化、fstab 自动挂载和验证命令完整插入正文，作为多盘 RAID0 测试过程证据。

适用环境：ESWIN Debian/RISC-V 板卡

目标：将 4 块 SATA HDD + 2 块 NVMe SSD 创建为 RAID0，并挂载到 /raid0

## 一、最终结果

RAID 设备：/dev/md0

RAID 级别：RAID0

参与磁盘：

/dev/sda TOSHIBA HDWG740UZSVC 3.6T
/dev/sdb TOSHIBA HDWG740UZSVC 3.6T
/dev/sdc TOSHIBA HDWG740UZSVC 3.6T
/dev/sdd TOSHIBA HDWG740UZSVC 3.6T
/dev/nvme0n1 Fanxiang S500Pro 256GB 238.5G
/dev/nvme1n1 Fanxiang S690 500GB 465.8G

系统盘：

/dev/mmcblk0

说明：系统盘 mmcblk0 不参与 RAID，不能清理或格式化。

最终挂载点：

/raid0

最终容量：

/dev/md0 约 16T，挂载到 /raid0

验证结果：

df -h /raid0
Filesystem Size Used Avail Use% Mounted on
/dev/md0 16T 2.1M 15T 1% /raid0

## 二、安装 RAID 工具 mdadm

检查 mdadm 是否已安装：

command -v mdadm

如果没有安装，执行：

sudo apt update
sudo apt install -y mdadm

实际执行中，系统提示：

mdadm is already the newest version (4.3+20240723-2).

说明 mdadm 已经安装，可以直接创建 RAID。

## 三、确认磁盘信息

执行：

lsblk -d -o NAME,MODEL,SIZE,TYPE,TRAN

实际识别到的磁盘：

NAME MODEL SIZE TYPE TRAN
sda TOSHIBA HDWG740UZSVC 3.6T disk sata
sdb TOSHIBA HDWG740UZSVC 3.6T disk sata
sdc TOSHIBA HDWG740UZSVC 3.6T disk sata
sdd TOSHIBA HDWG740UZSVC 3.6T disk sata
mmcblk0 29.1G disk mmc
nvme0n1 Fanxiang S500Pro 256GB 238.5G disk nvme
nvme1n1 Fanxiang S690 500GB 465.8G disk nvme

确认：

/dev/mmcblk0 是系统盘，不操作。
/dev/sda /dev/sdb /dev/sdc /dev/sdd /dev/nvme0n1 /dev/nvme1n1 用于 RAID0。

## 四、设置 RAID 磁盘变量

执行：

DISKS="/dev/sda /dev/sdb /dev/sdc /dev/sdd /dev/nvme0n1 /dev/nvme1n1"

确认变量：

echo $DISKS

预期输出：

/dev/sda /dev/sdb /dev/sdc /dev/sdd /dev/nvme0n1 /dev/nvme1n1

## 五、清理旧挂载、旧文件系统签名和旧 RAID 超级块

注意：该步骤会清理参与 RAID 的磁盘签名，属于破坏性操作。

不要把系统盘 /dev/mmcblk0 加入 DISKS。

执行：

for d in $DISKS; do sudo umount ${d}* 2>/dev/null || true; sudo wipefs -a "$d"; sudo mdadm --zero-superblock --force "$d" 2>/dev/null || true; done

实际执行中，部分磁盘清理到 ext4 签名，例如：

/dev/sdd: 2 bytes were erased at offset 0x00000438 (ext4): 53 ef
/dev/nvme0n1: 2 bytes were erased at offset 0x00000438 (ext4): 53 ef

## 六、创建 RAID0

执行：

sudo mdadm --create /dev/md0 --level=0 --raid-devices=6 --chunk=512K --run $DISKS

实际结果：

mdadm: Defaulting to version 1.2 metadata
mdadm: array /dev/md0 started.

说明 /dev/md0 创建成功。

## 七、查看 RAID 状态

执行：

cat /proc/mdstat

实际结果：

Personalities : [raid0]
md0 : active raid0 nvme1n1[5] nvme0n1[4] sdd[3] sdc[2] sdb[1] sda[0]
16365725696 blocks super 1.2 512k chunks

执行：

sudo mdadm --detail /dev/md0

关键结果：

Raid Level : raid0
Array Size : 16365725696 (15.24 TiB 16.76 TB)
Raid Devices : 6
Total Devices : 6
State : clean
Active Devices : 6
Working Devices : 6
Failed Devices : 0
Spare Devices : 0
Chunk Size : 512K

说明：

RAID0 状态 clean。
6 块盘全部 active。
没有 Failed Devices。

## 八、格式化 RAID0 为 ext4

执行：

sudo mkfs.ext4 -F /dev/md0

实际结果：

Creating filesystem with 4091431424 4k blocks and 511430656 inodes
Filesystem UUID: 99e6f480-82af-4309-bd01-77f64cf79bc4
Writing superblocks and filesystem accounting information: done

说明：

/dev/md0 已格式化为 ext4。
文件系统 UUID 为 99e6f480-82af-4309-bd01-77f64cf79bc4。

## 九、创建挂载目录并挂载

创建目录：

sudo mkdir -p /raid0

挂载 RAID0：

sudo mount /dev/md0 /raid0

查看容量：

df -h /raid0

实际结果：

Filesystem Size Used Avail Use% Mounted on
/dev/md0 16T 2.1M 15T 1% /raid0

查看设备树：

lsblk -o NAME,SIZE,TYPE,MOUNTPOINTS

实际结果中可以看到：

sda 3.6T disk
└─md0 15.2T raid0 /raid0
sdb 3.6T disk
└─md0 15.2T raid0 /raid0
sdc 3.6T disk
└─md0 15.2T raid0 /raid0
sdd 3.6T disk
└─md0 15.2T raid0 /raid0
nvme0n1 238.5G disk
└─md0 15.2T raid0 /raid0
nvme1n1 465.8G disk
└─md0 15.2T raid0 /raid0

## 十、保存 mdadm 配置

创建 mdadm 配置目录：

sudo mkdir -p /etc/mdadm

保存 RAID 阵列配置：

sudo mdadm --detail --scan | sudo tee /etc/mdadm/mdadm.conf

实际写入内容：

ARRAY /dev/md0 metadata=1.2 UUID=141648d6:172eeeab:71bb279d:37493674

## 十一、写入 /etc/fstab，实现自动挂载

先获取 /dev/md0 文件系统 UUID：

UUID=$(sudo blkid -s UUID -o value /dev/md0)

写入 /etc/fstab：

echo "UUID=${UUID} /raid0 ext4 defaults,nofail 0 0" | sudo tee -a /etc/fstab

本次 RAID0 文件系统 UUID：

99e6f480-82af-4309-bd01-77f64cf79bc4

对应 fstab 行：

UUID=99e6f480-82af-4309-bd01-77f64cf79bc4 /raid0 ext4 defaults,nofail 0 0

注意：

如果之前 tee 命令少写了 /etc/fstab，会只打印内容，不会真正写入文件。
正确命令必须包含：
| sudo tee -a /etc/fstab

## 十二、验证 fstab 自动挂载

如果 /raid0 当前已经挂载，可以先卸载：

sudo umount /raid0

重新按 fstab 挂载：

sudo mount -a

验证：

df -h /raid0

正确结果：

Filesystem Size Used Avail Use% Mounted on
/dev/md0 16T 2.1M 15T 1% /raid0

如果看到 /dev/mmcblk0p3，说明 /raid0 没有挂载成功，需要检查 /etc/fstab 是否真的写入了 /raid0 那一行。

## 十三、常用检查命令

查看 RAID 阵列状态：

cat /proc/mdstat

查看 RAID 详细信息：

sudo mdadm --detail /dev/md0

查看挂载容量：

df -h /raid0

查看设备挂载关系：

lsblk -o NAME,SIZE,TYPE,MOUNTPOINTS

查看 fstab 中的 RAID0 配置：

grep raid0 /etc/fstab

查看 mdadm 配置：

cat /etc/mdadm/mdadm.conf

## 十四、注意事项

1. RAID0 没有冗余。

任意一块参与 RAID0 的磁盘异常、掉线或损坏，整个 RAID0 数据都会不可用。

2. 本次 RAID0 混用了 HDD 和 NVMe。

该方案可以用于临时容量池或性能测试，但正式性能结论不建议混合 HDD 与 NVMe，因为两类盘性能差异很大，结果不易分析。

3. 系统盘是 /dev/mmcblk0。

后续任何 wipefs、mkfs、mdadm 创建命令都不要包含 /dev/mmcblk0。

4. 如果重启后 /raid0 没自动挂载，优先检查：

cat /proc/mdstat
sudo mdadm --detail /dev/md0
grep raid0 /etc/fstab
sudo mount -a
df -h /raid0

## 十五、完整命令汇总

sudo apt update
sudo apt install -y mdadm

lsblk -d -o NAME,MODEL,SIZE,TYPE,TRAN

DISKS="/dev/sda /dev/sdb /dev/sdc /dev/sdd /dev/nvme0n1 /dev/nvme1n1"
echo $DISKS

for d in $DISKS; do sudo umount ${d}* 2>/dev/null || true; sudo wipefs -a "$d"; sudo mdadm --zero-superblock --force "$d" 2>/dev/null || true; done

sudo mdadm --create /dev/md0 --level=0 --raid-devices=6 --chunk=512K --run $DISKS

cat /proc/mdstat
sudo mdadm --detail /dev/md0

sudo mkfs.ext4 -F /dev/md0
sudo mkdir -p /raid0
sudo mount /dev/md0 /raid0

df -h /raid0
lsblk -o NAME,SIZE,TYPE,MOUNTPOINTS

sudo mkdir -p /etc/mdadm
sudo mdadm --detail --scan | sudo tee /etc/mdadm/mdadm.conf

UUID=$(sudo blkid -s UUID -o value /dev/md0)
echo "UUID=${UUID} /raid0 ext4 defaults,nofail 0 0" | sudo tee -a /etc/fstab

sudo umount /raid0
sudo mount -a
df -h /raid0

# 附录 B：U-Boot 常用命令速查

命令 | 用途 | 注意事项
help / help <cmd> | 查看 U-Boot 命令帮助 | 适合不熟悉命令时快速查询
print | 查看环境变量 | 重点看 ethaddr、fdtfile、partitions、boot_targets 等
env set ethaddr xx:xx:xx:xx:xx:xx | 设置主网口 MAC 地址 | 设置后需 saveenv 保存
saveenv | 保存环境变量 | 保存后重启仍生效
env default -a | 恢复默认环境变量 | 会清除手动添加的变量，执行前需确认
mmc part | 查看 eMMC/SD 分区 | 用于排查分区不存在或大小不足
run gpt_partition | 重新写入 GPT 分区表 | 会改变分区布局，执行前确认数据风险
usb reset | 重新扫描 USB 设备 | USB 热插拔后需要执行
reset | 重启板卡 | 烧录完成后常用

内部测试/调试资料，请结合实际版本与板卡实物信息使用

EIC7700 AI NAS 板卡识别与烧录指南

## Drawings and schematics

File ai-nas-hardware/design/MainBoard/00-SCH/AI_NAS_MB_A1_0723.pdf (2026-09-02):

D | D

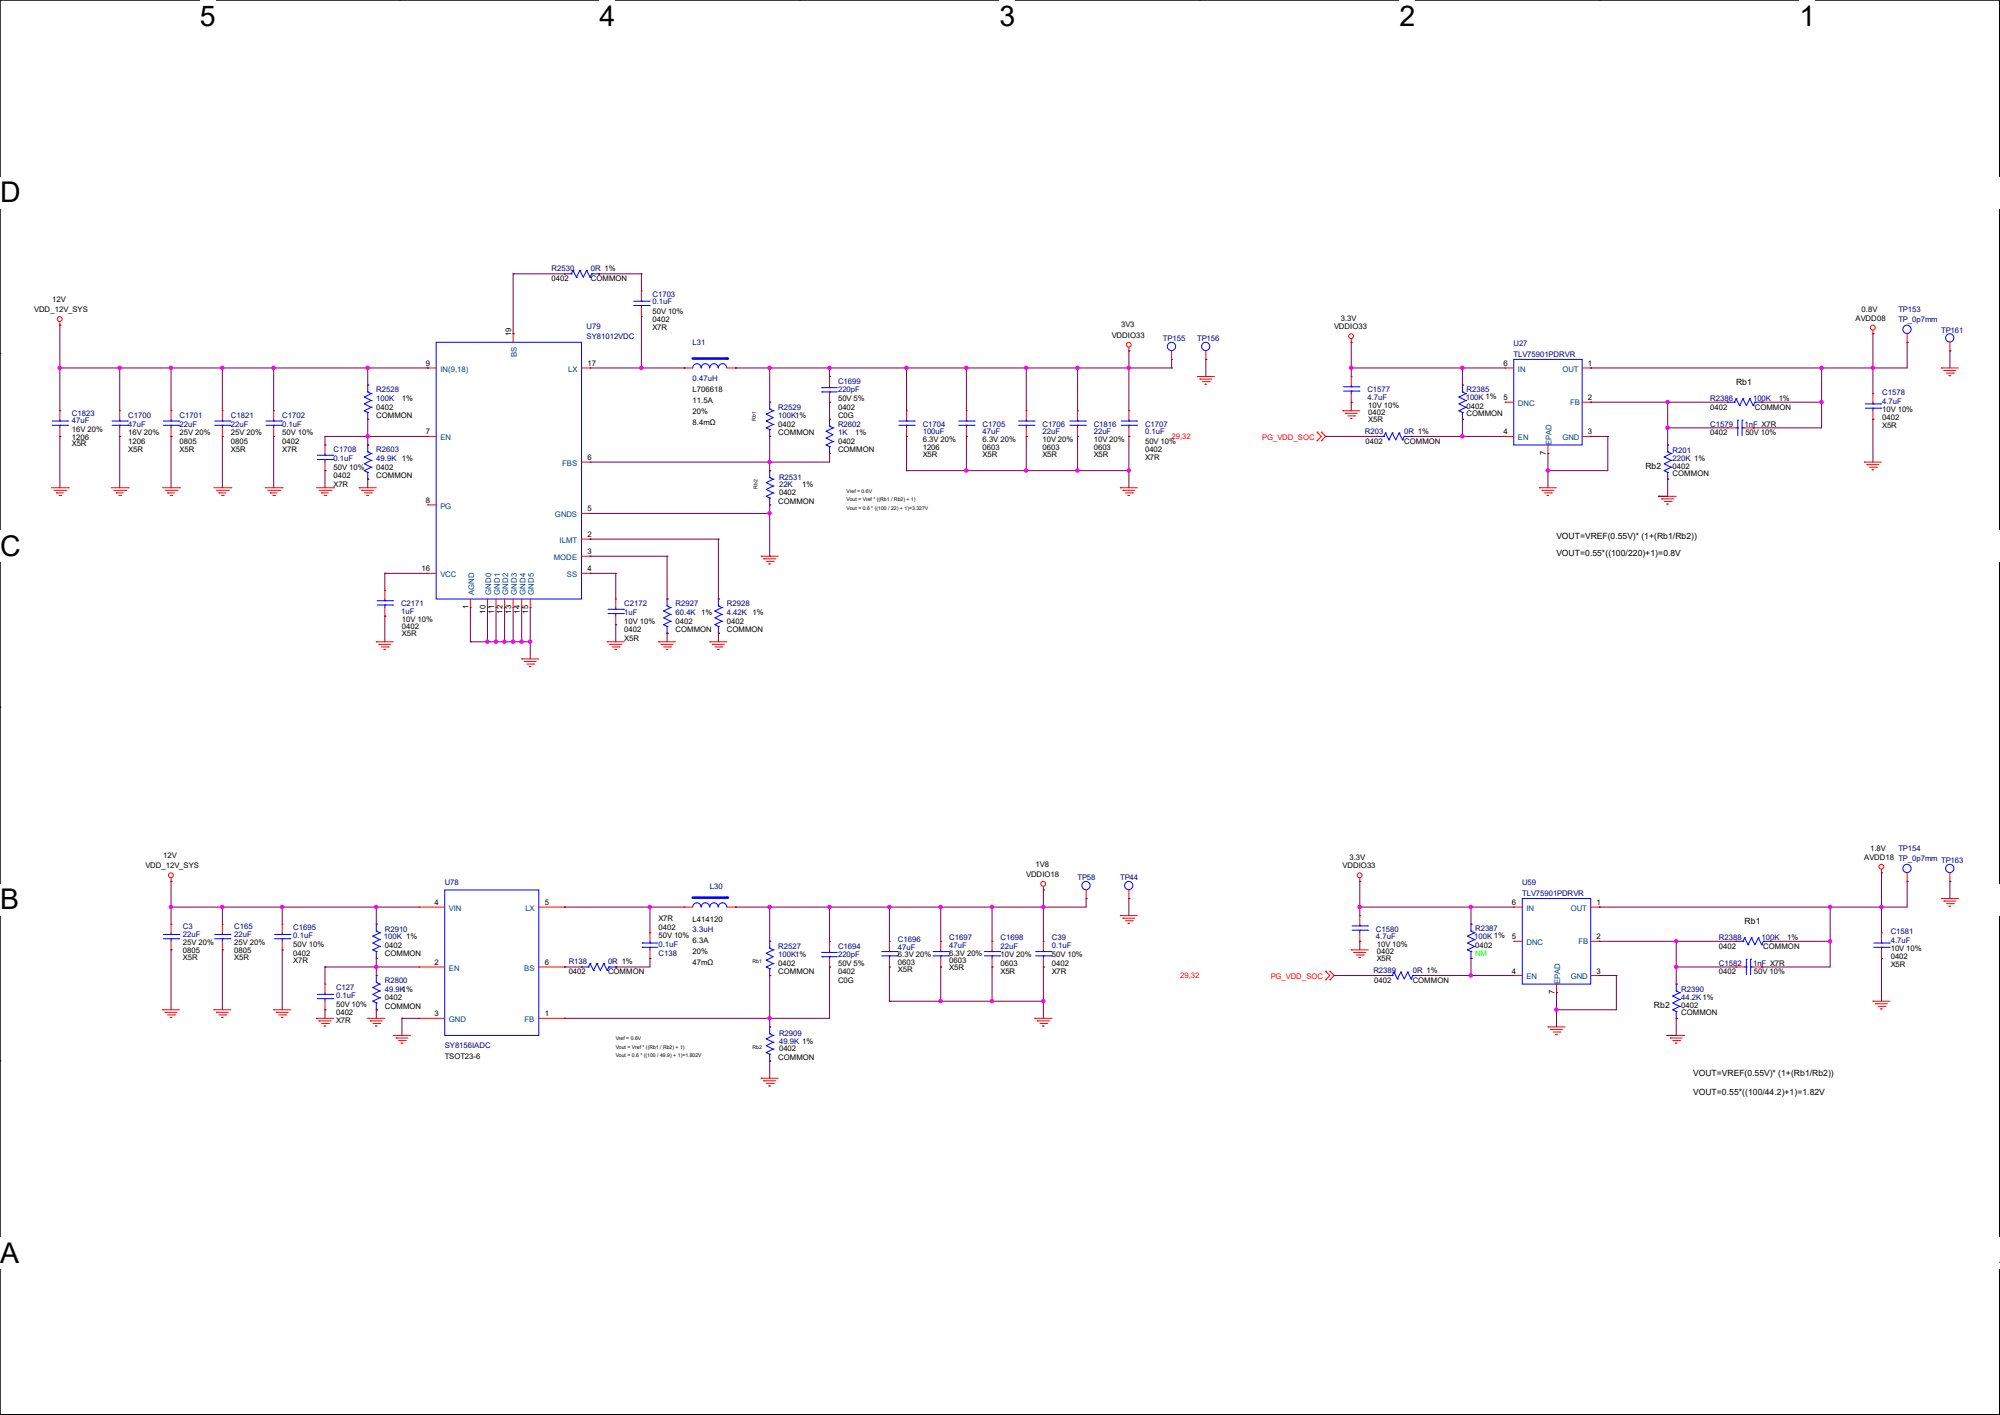
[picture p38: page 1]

D | D

Power on/off Sequence: VDD1>VDD2H>=VDD2L>VDDQ-200mV
VDD1: 1.70V--1.95V,Power for core1.
VDD2H:1.01V--1.12V,Power for core2 and Input Buffer.
VDD2L:0.87V--0.97V,Power for core2 and Input Buffer.
VDDQ: 0.47V--0.57V,Power for I/O Buffer.

D | D

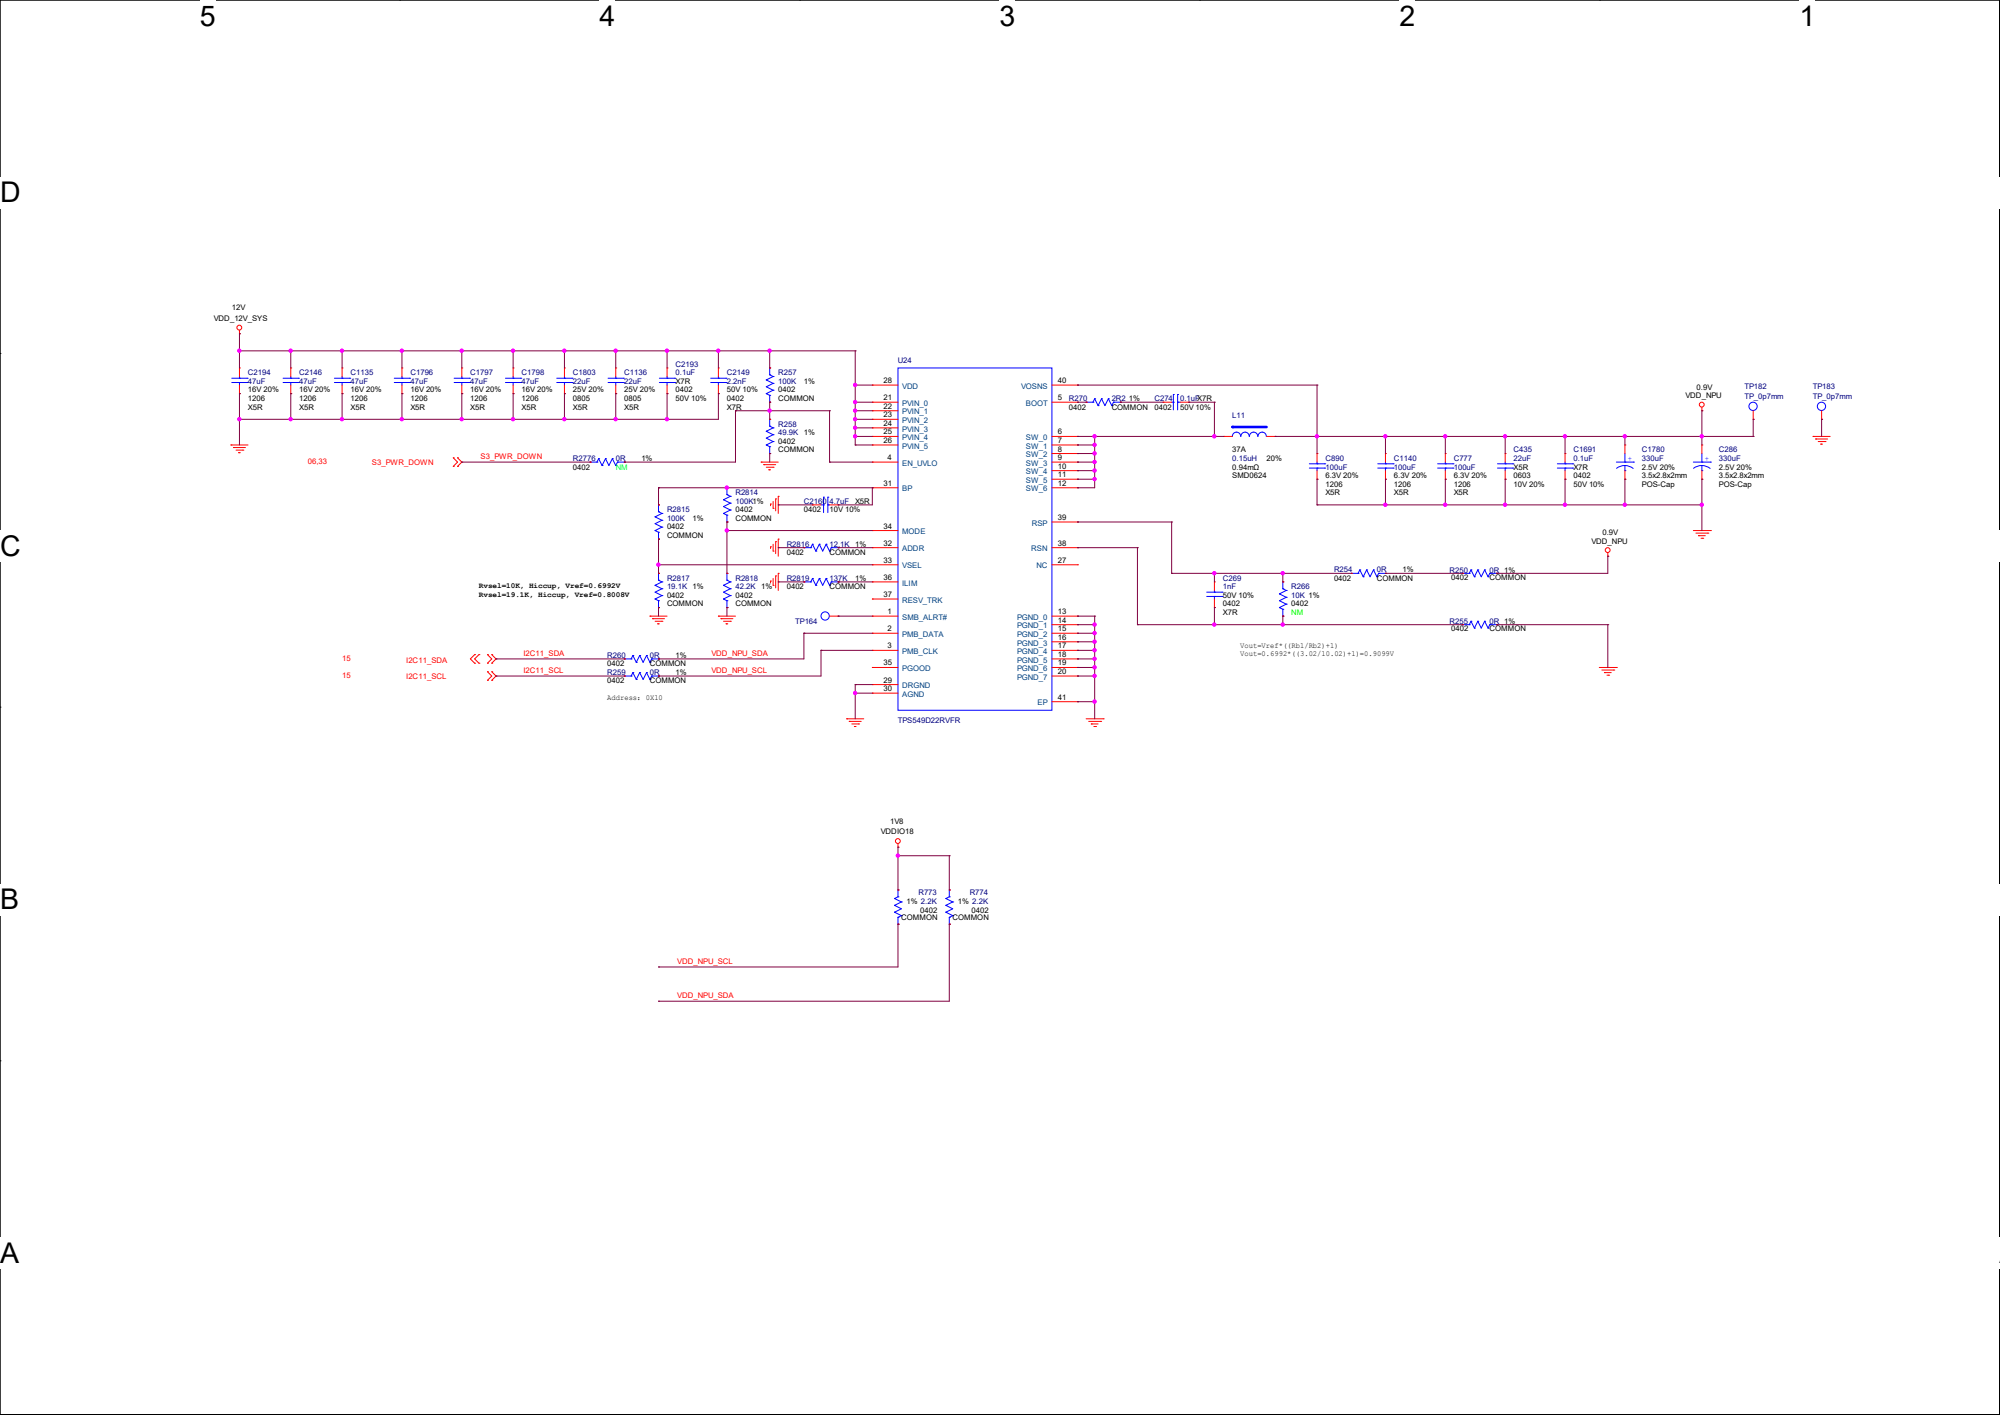
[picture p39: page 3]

# Debug UART

# Buzzer

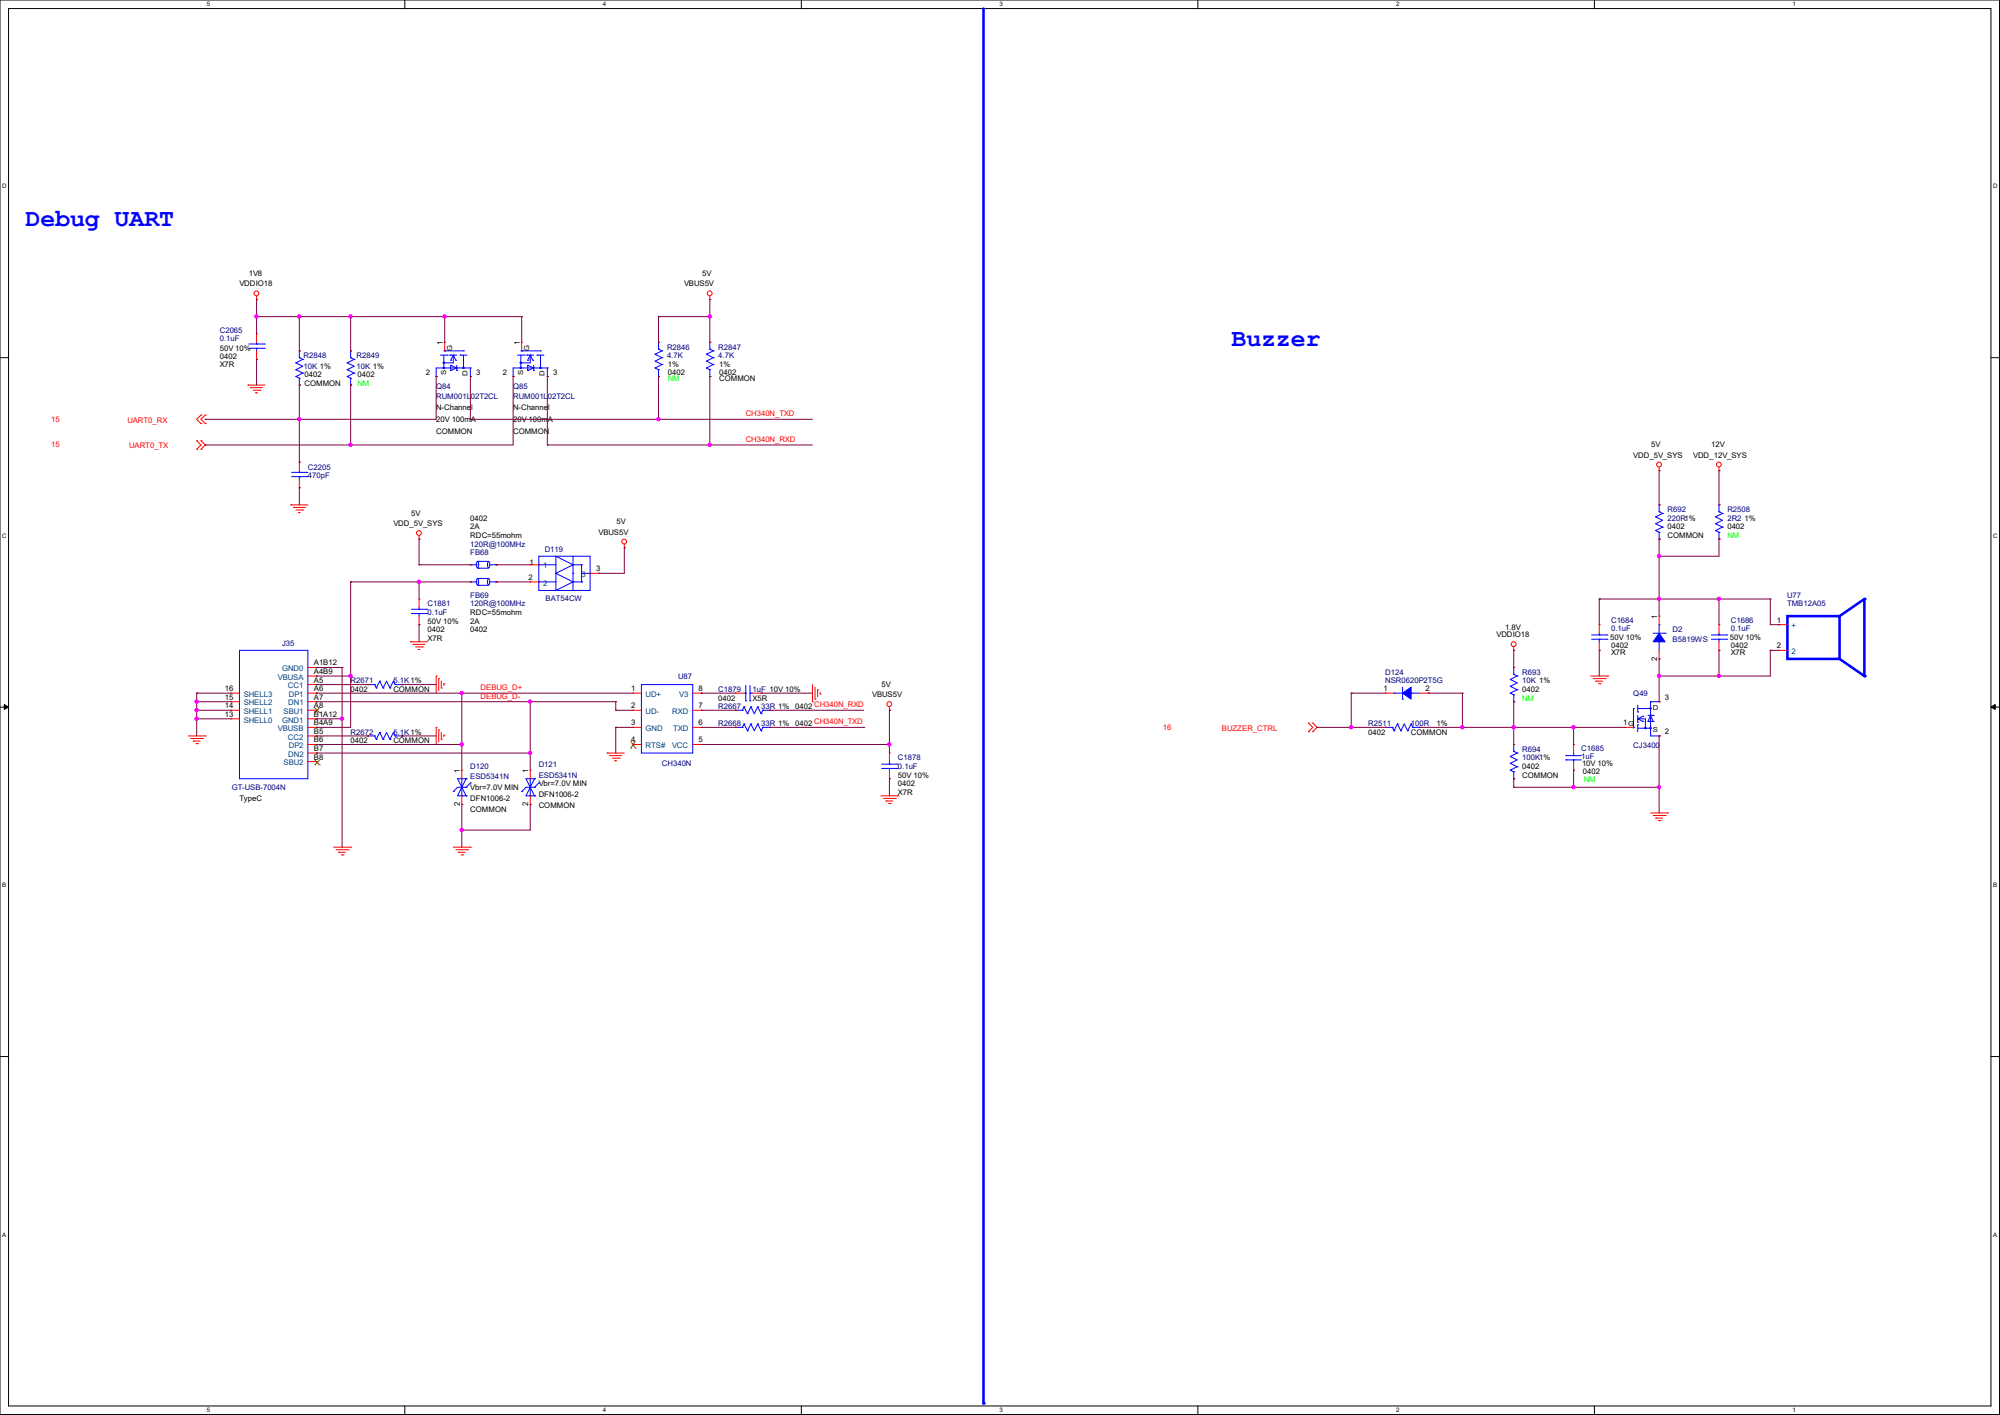
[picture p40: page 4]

1V8 5V VDDIO18 VBUS5V

5V VDD_5V_SYS

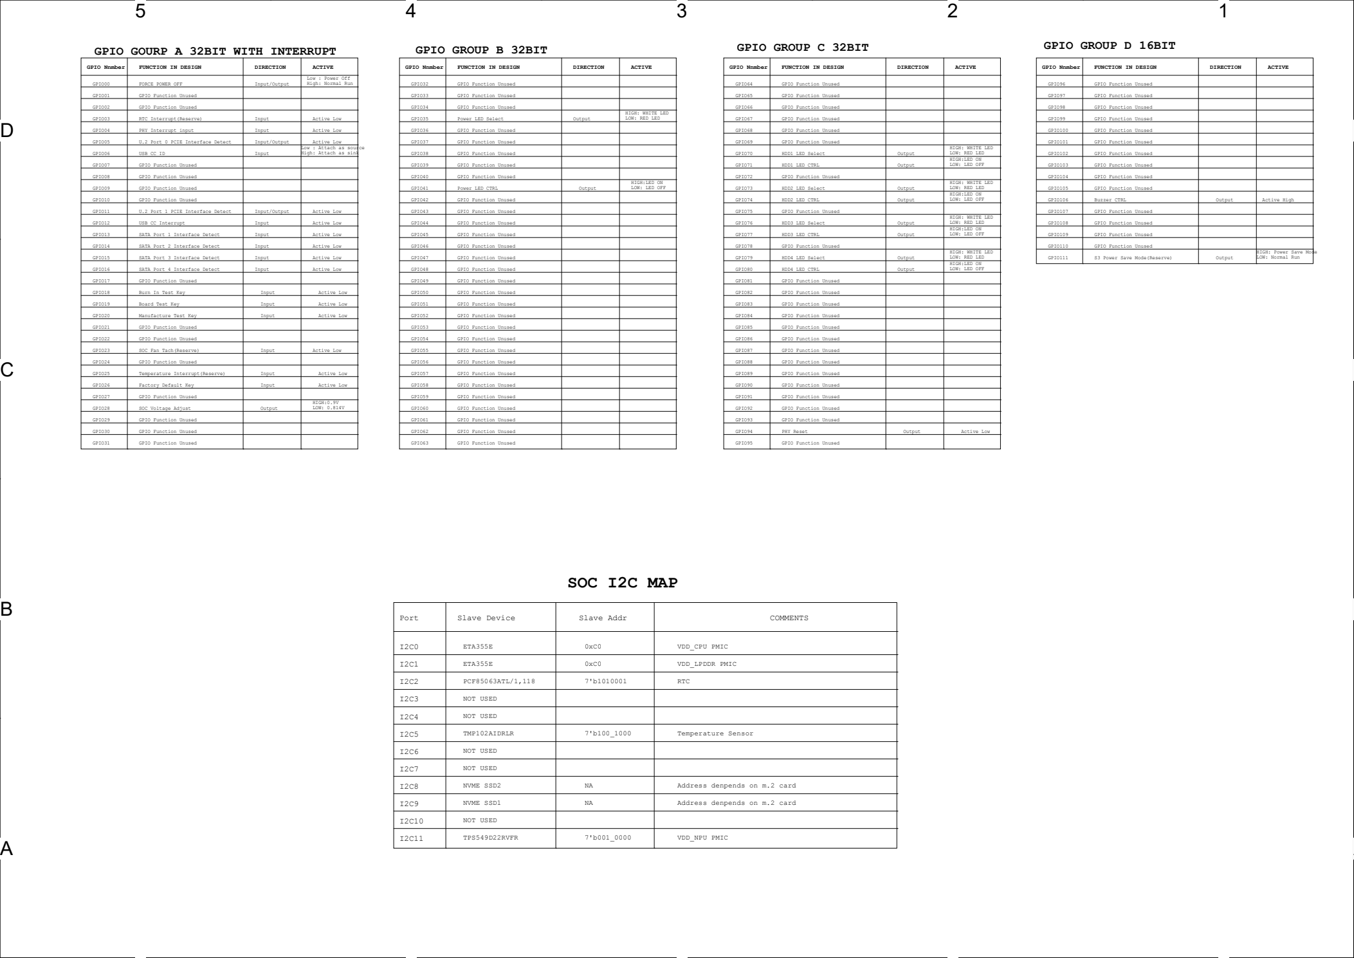
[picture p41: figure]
GPIO44; GPIO76; ACTIVE; GPIO Function Unused; FUNCTION IN DESIGN; S3 Power Save Mode(Reserve); GPIO68; GPIO11; GPIO86; GPIO77; GPIO89; GPIO93; GPIO08; USB CC ID; GPIO Nnmber; GPIO95; GPIO83; FORCE POWER OFF; GPIO103; GPIO25; GPIO97; GPIO63; GPIO14; GPIO101; GPIO102; GPIO02; GPIO65; GPIO66; GPIO69; GPIO36; GPIO75; GPIO72; Input/Output; GPIO104; GPIO47; GPIO05; GPIO61; GPIO73; GPIO78; GPIO40; U.2 Port 0 PCIE Interface Detect; GPIO28; GPIO39; GPIO99; GPIO20; GPIO98; GPIO GROUP D 16BIT; GPIO71; GPIO52; GPIO60; GPIO07; GPIO45; GPIO110; GPIO24; GPIO23; GPIO70; GPIO50; GPIO16; GPIO92; GPIO64; GPIO53; GPIO32; GPIO21; GPIO81; GPIO51; GPIO GROUP C 32BIT; GPIO37; Low : Power Off High: Normal Run; GPIO03; GPIO26; GPIO30; GPIO17; GPIO107; GPIO GROUP B 32BIT; GPIO10; HDD1 LED CTRL; GPIO GOURP A 32BIT WITH INTERRUPT; GPIO94; GPIO82; GPIO108; GPIO74; GPIO109; GPIO31; GPIO34; GPIO09; GPIO59; GPIO57; GPIO58; GPIO22; DIRECTION; GPIO13; GPIO18; GPIO00; GPIO80; GPIO100; GPIO106; GPIO111; PHY Interrupt input; GPIO96; GPIO49; GPIO38; GPIO84; GPIO79; GPIO43; GPIO54; GPIO56; GPIO12; GPIO62; PHY Reset; HDD1 LED Select; Factory Default Key; GPIO01; GPIO48; GPIO04; GPIO33; GPIO88; GPIO87; GPIO42; GPIO85; Buzzer CTRL; GPIO90; GPIO55; GPIO29; GPIO105; GPIO91; GPIO46; GPIO27; GPIO19; GPIO67; GPIO06; GPIO15; Output; HIGH: WHITE LED LOW: RED LED; HIGH:LED ON LOW: LED OFF; HIGH:LED ON; HDD2 LED CTRL; LOW: LED OFF; HDD2 LED Select; HDD3 LED CTRL; HDD3 LED Select; HDD4 LED CTRL; HDD4 LED Select; Input; Power LED CTRL; Power LED Select; GPIO41; GPIO35; Burn In Test Key; Board Test Key; Manufacture Test Key; Active Low; SOC Voltage Adjust; HIGH:0.9V; LOW: 0.814V; HIGH: Power Save Mode LOW: Normal Run; Active High; ETA355E; SOC I2C MAP; Port; Slave Device; Slave Addr; COMMENTS; VDD_CPU PMIC; VDD_LPDDR PMIC; PCF85063ATL/1,118; RTC; TMP102AIDRLR; NVME SSD2; TPS549D22RVFR; Temperature Sensor; NOT USED; NVME SSD1; Address denpends on m.2 card; VDD_NPU PMIC; Low : Attach as source High: Attach as sink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

Temperature Interrupt(Reserve) | Input | Active Low
U.2 Port 1 PCIE Interface Detect | Input/Output | Active Low
SATA Port 1 Interface Detect | Input | Active Low
SATA Port 2 Interface Detect | Input | Active Low
SATA Port 3 Interface Detect | Input | Active Low
SATA Port 4 Interface Detect | Input | Active Low

D

D

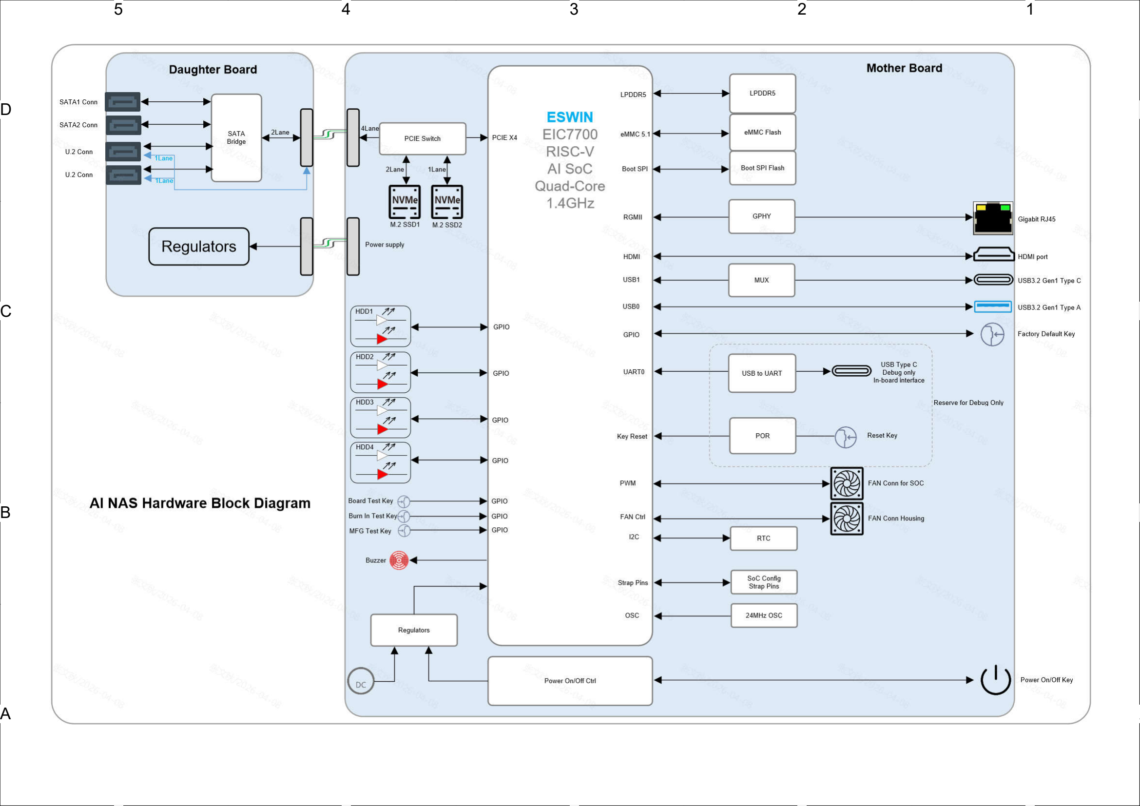
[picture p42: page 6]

C

C

B

B

A

A

D | D
DB

3.3V AUX POWER IN

D | D

## C2195 C2196 C2197 C2198 0R

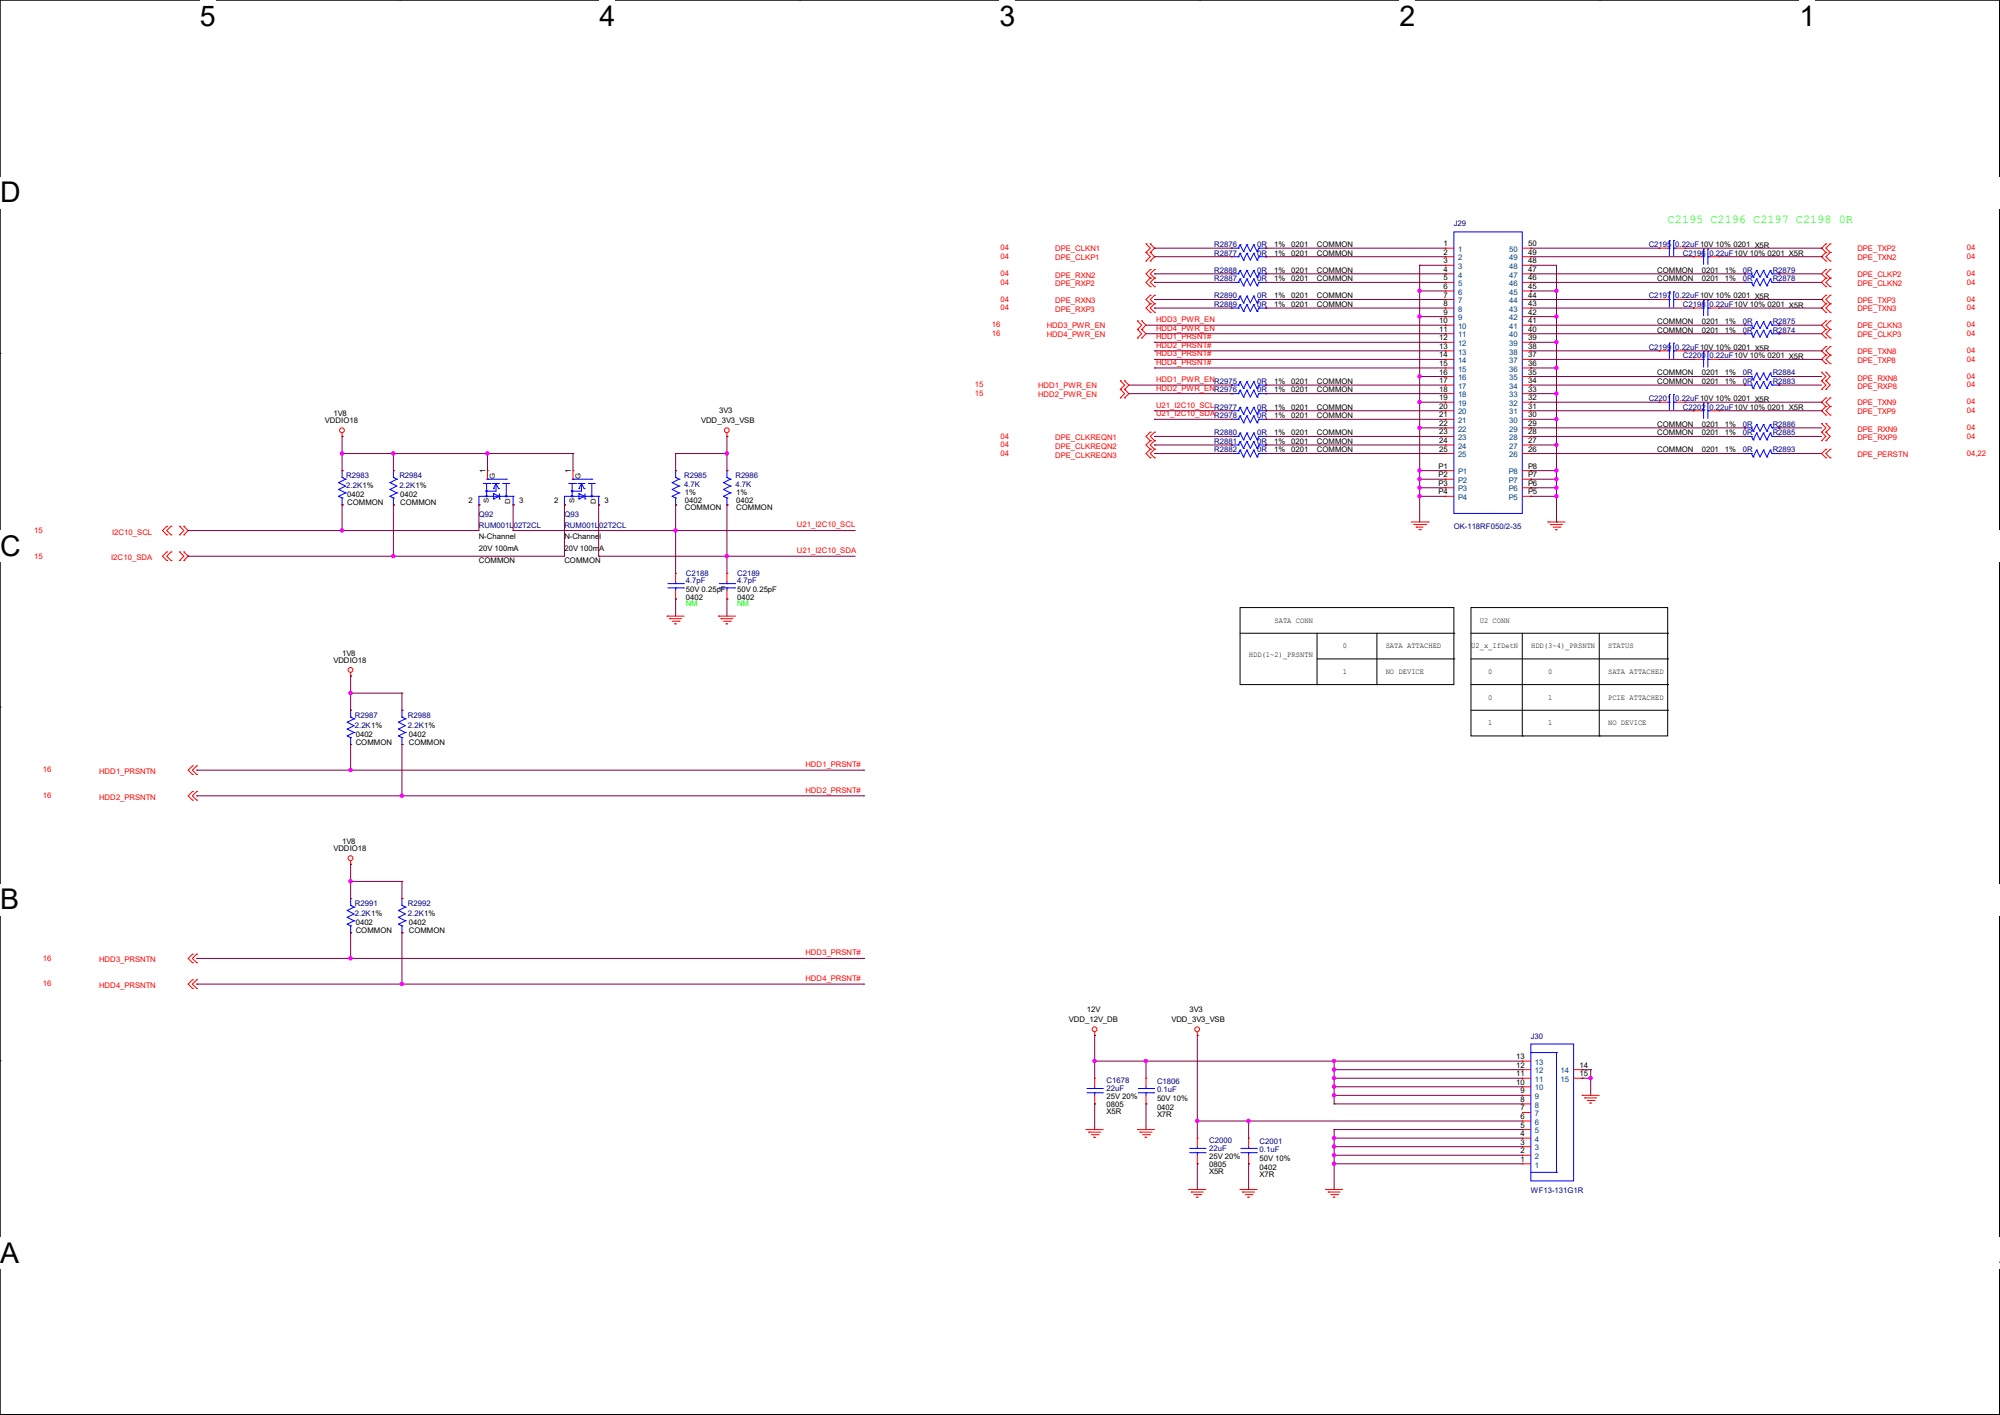
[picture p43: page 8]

D | D

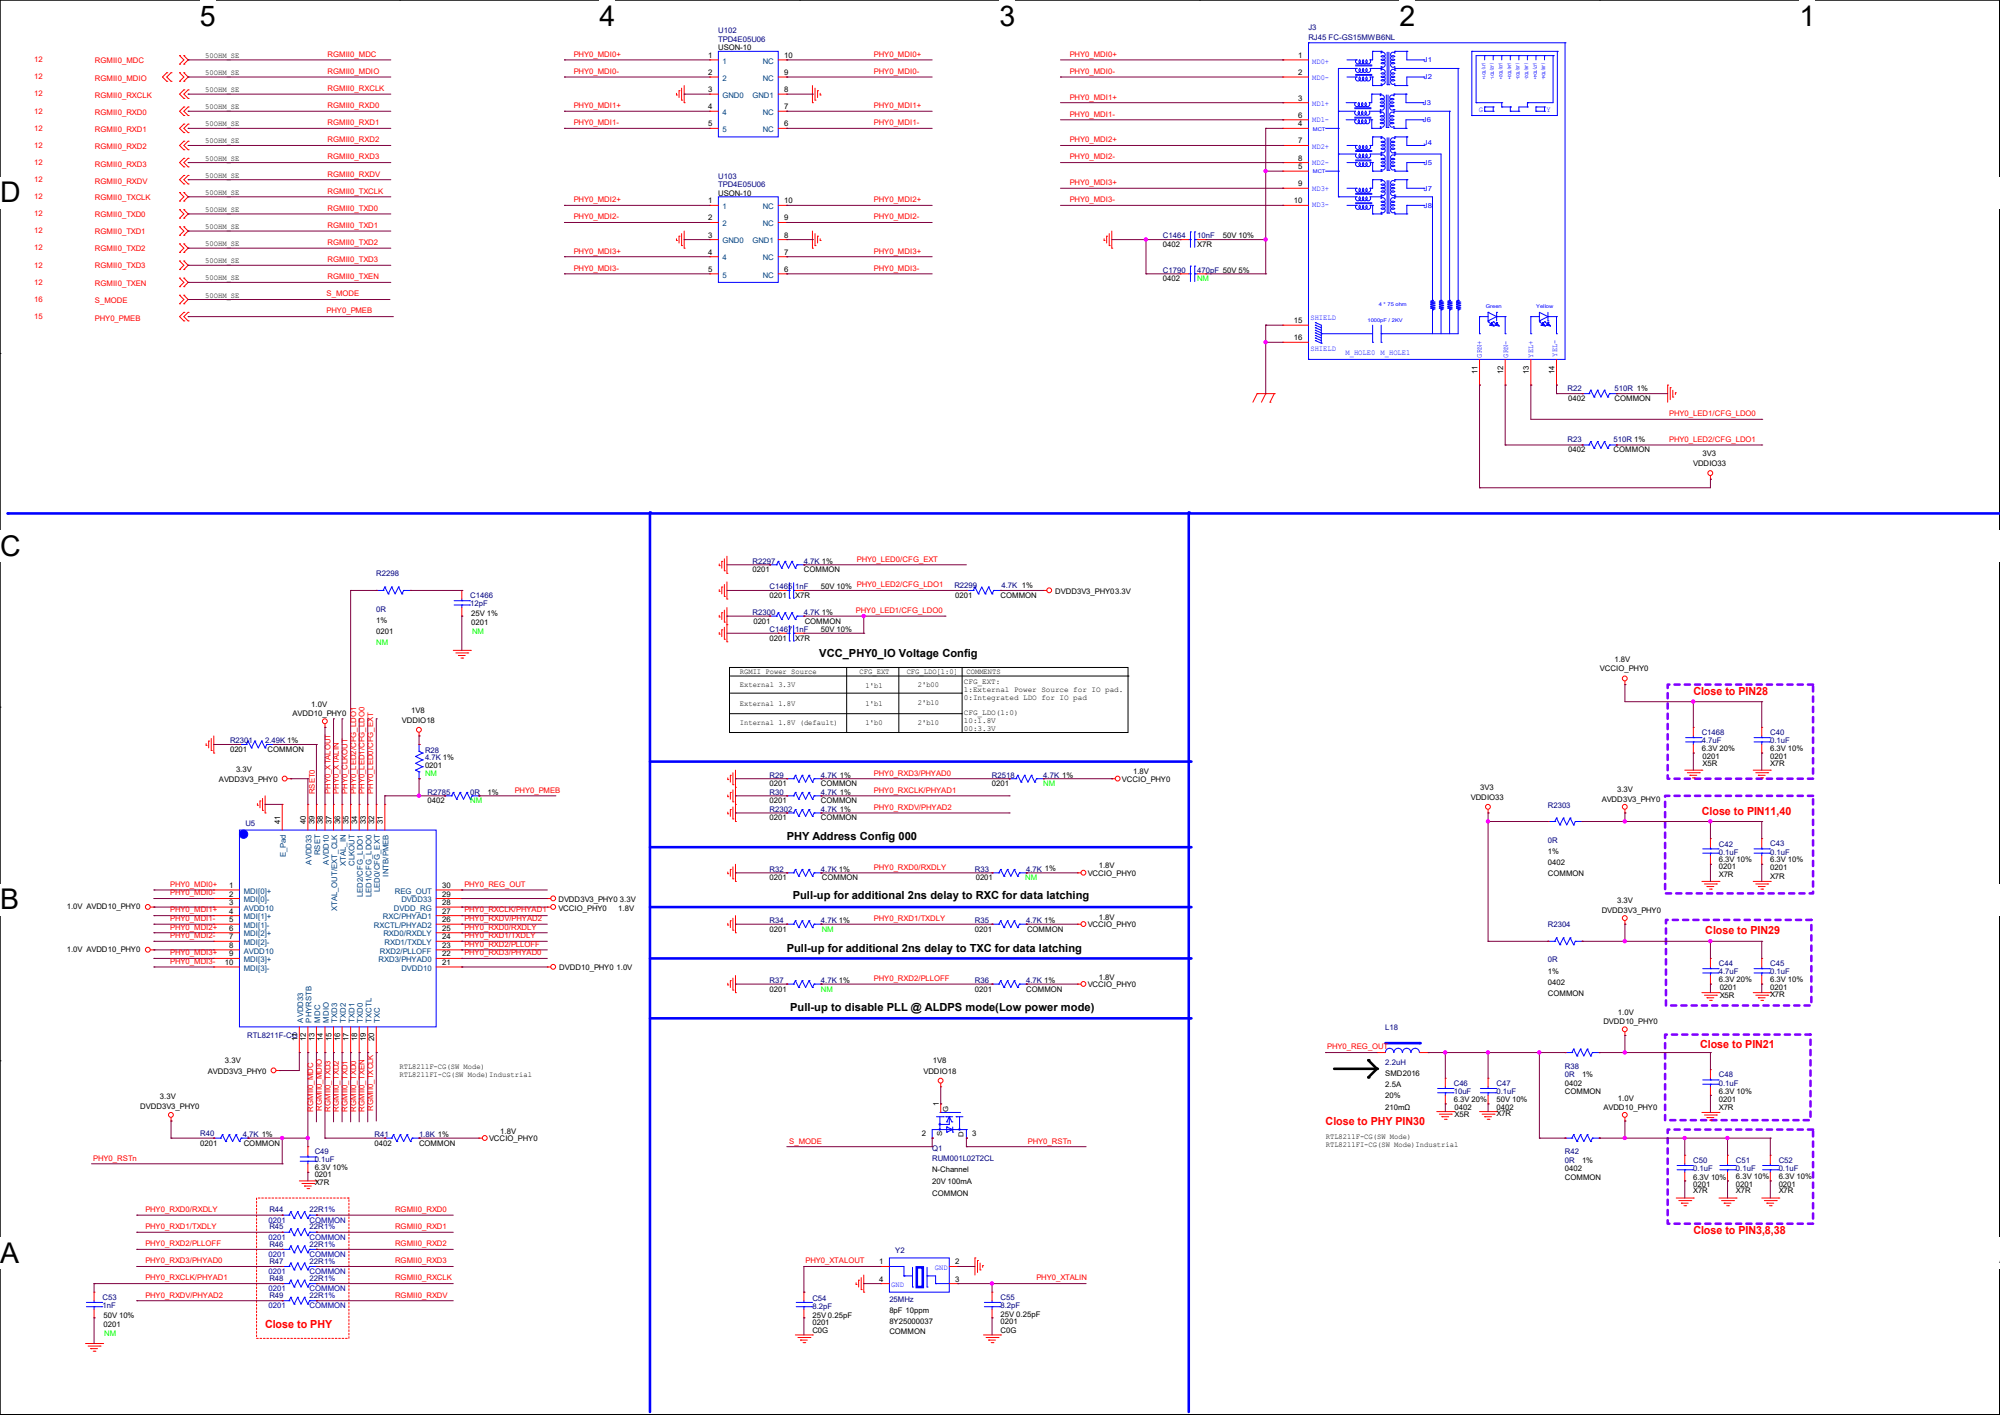
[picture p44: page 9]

COMMENTS
CFG_EXT:
1:External Power Source for IO pad.
0:Integrated LDO for IO pad

Pull-up for additional 2ns delay to RXC for data latching

Pull-up for additional 2ns delay to TXC for data latching

Pull-up to disable PLL @ ALDPS mode(Low power mode)

RTL8211F-CG(SW Mode)
RTL8211FI-CG(SW Mode)Industrial

D | D

D | D

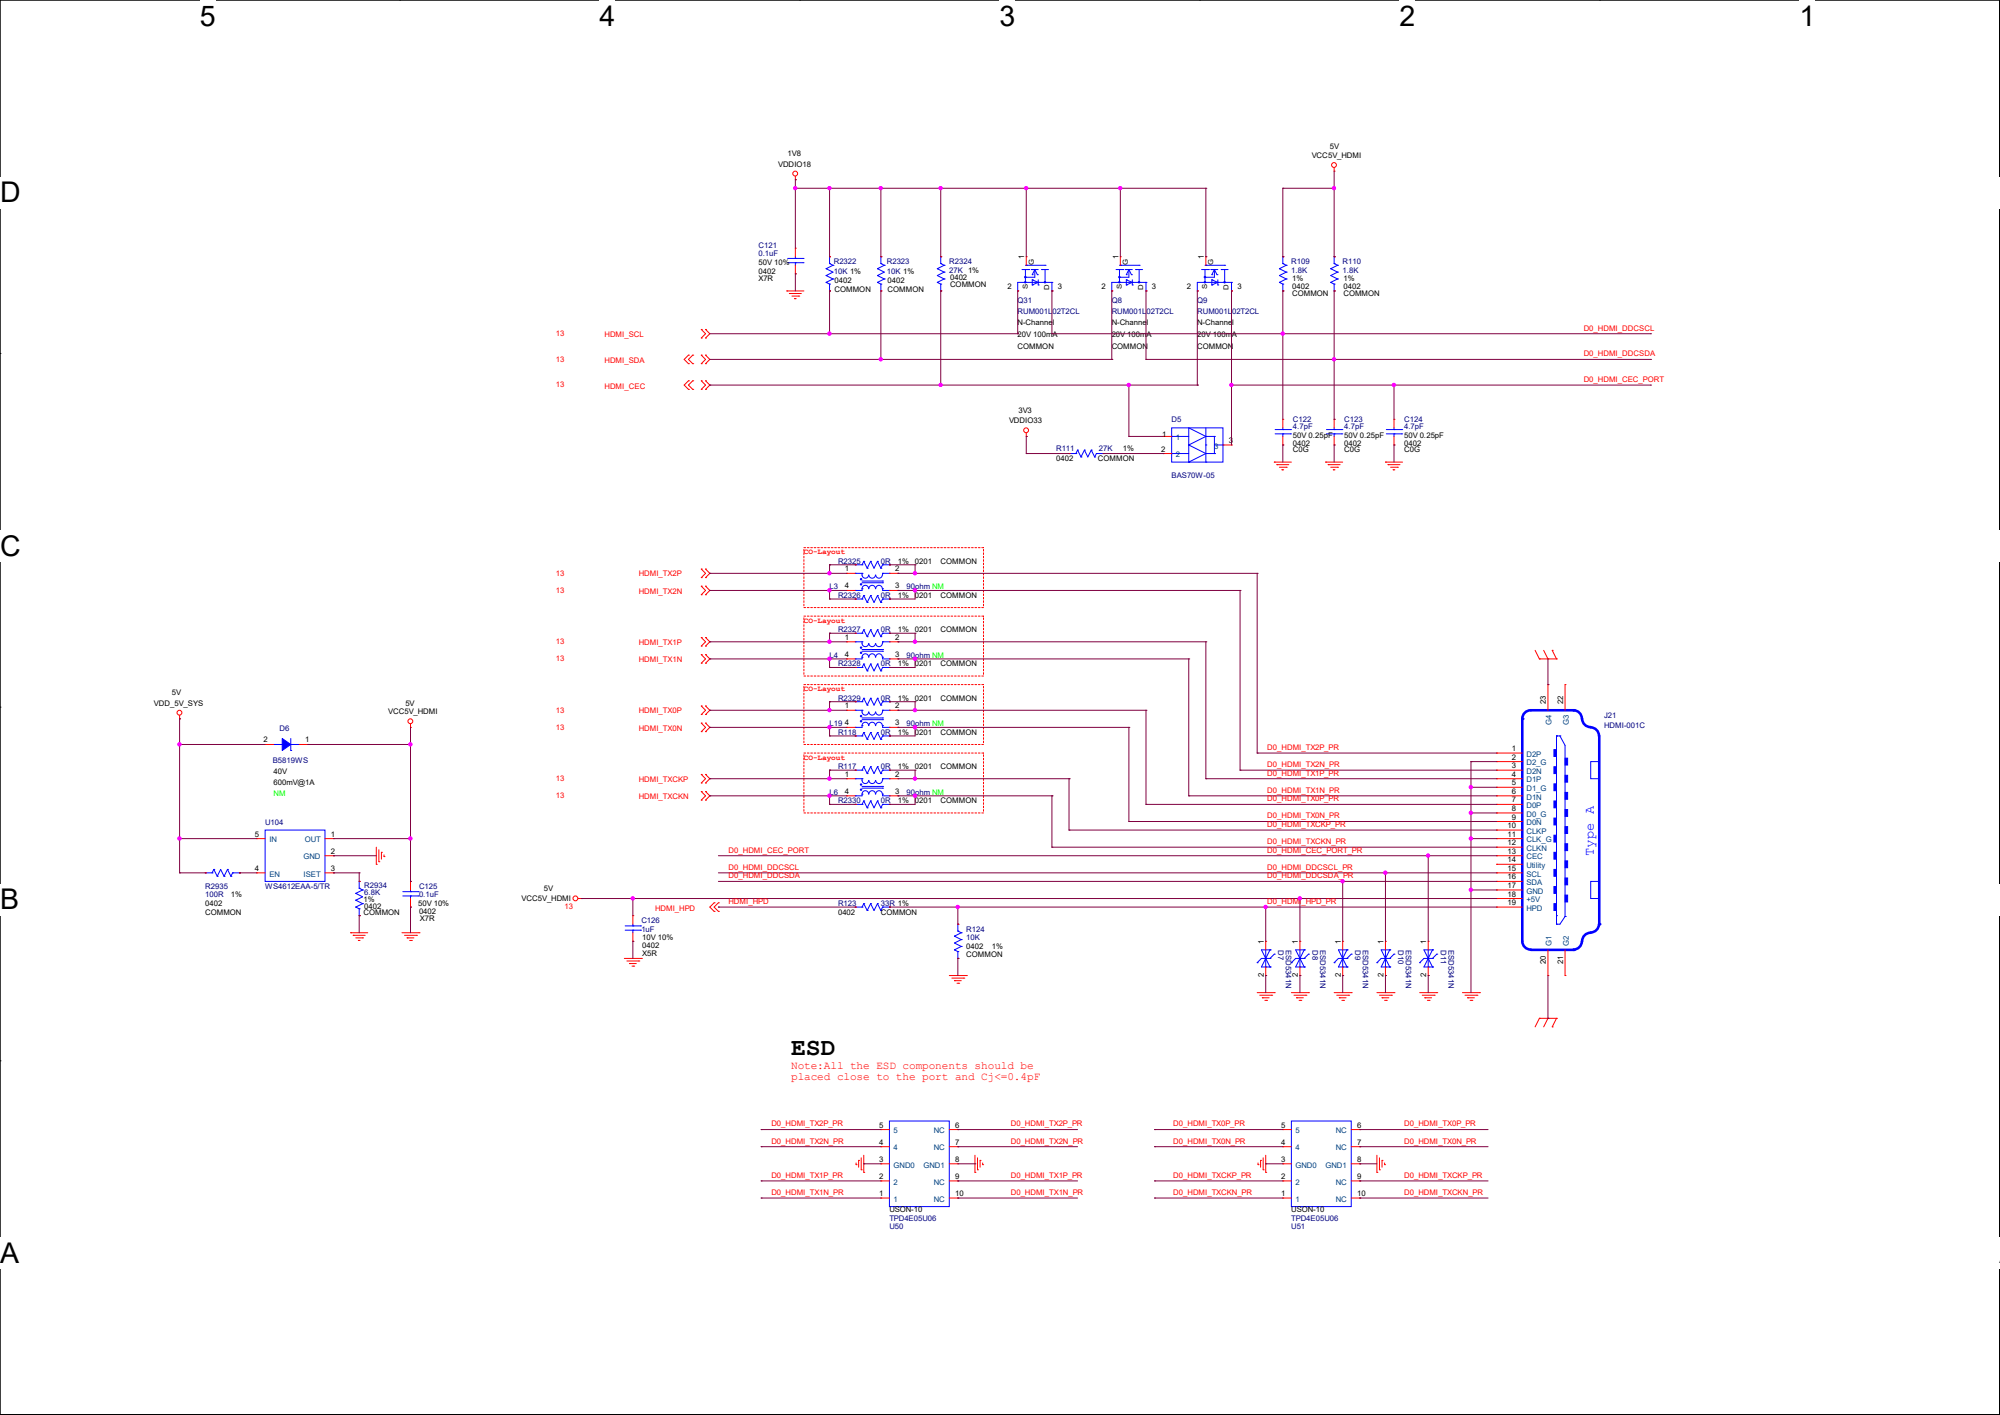
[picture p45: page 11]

Note:All the ESD components should be
placed close to the port and Cj<=0.4pF

D | D

# SY81012VDCAGND 1

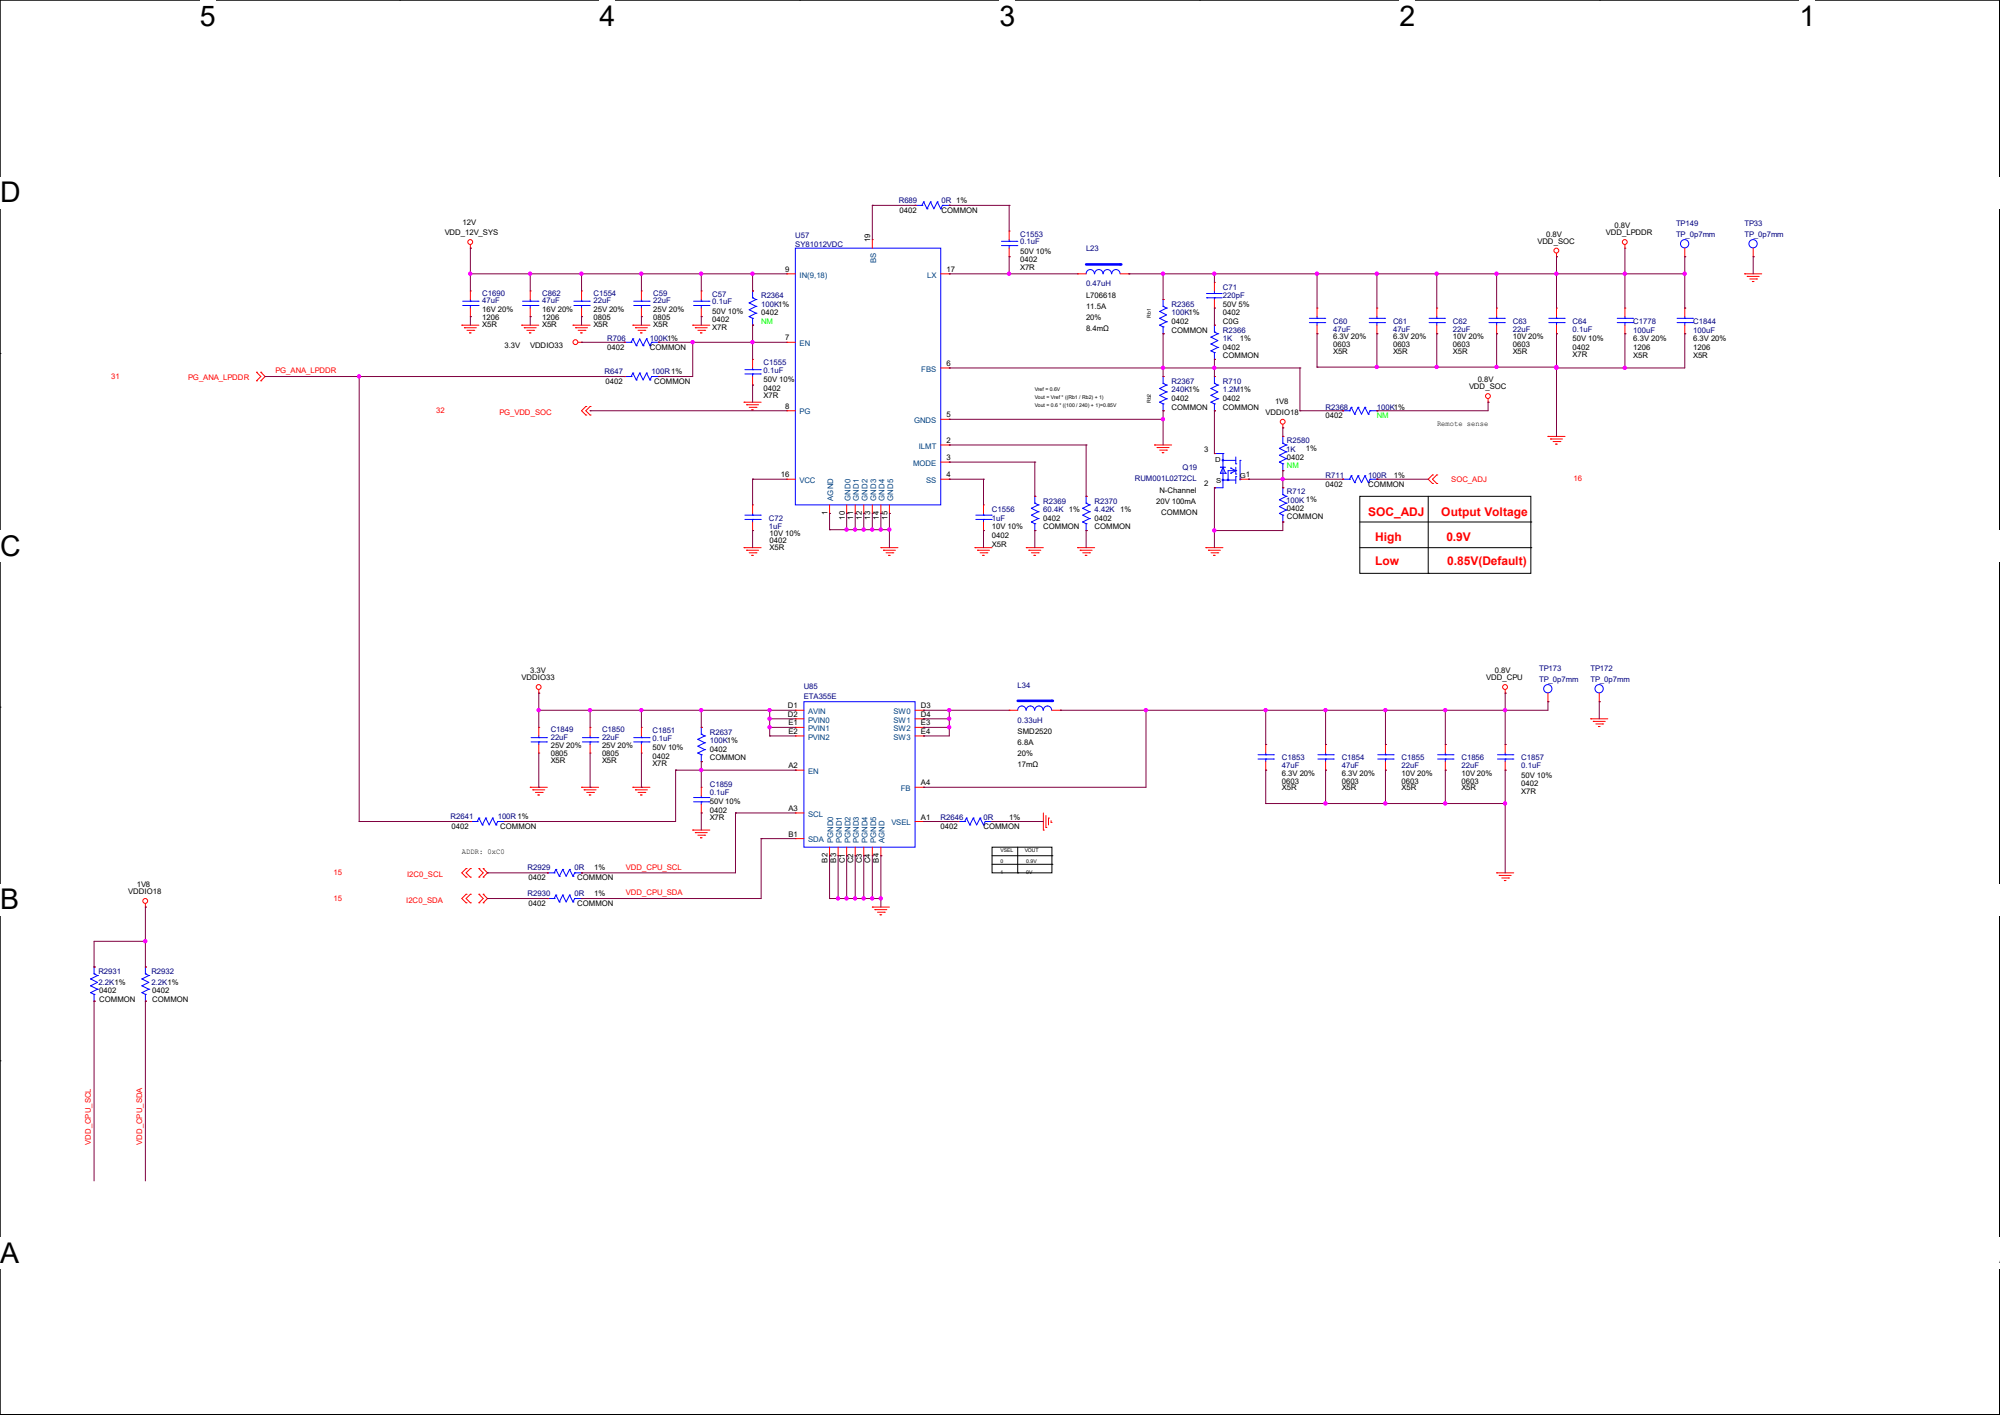
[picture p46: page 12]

D | D
C | C
B | B
A | A

# INTERNAL RESERVE

# FAN Cons

# KEYs

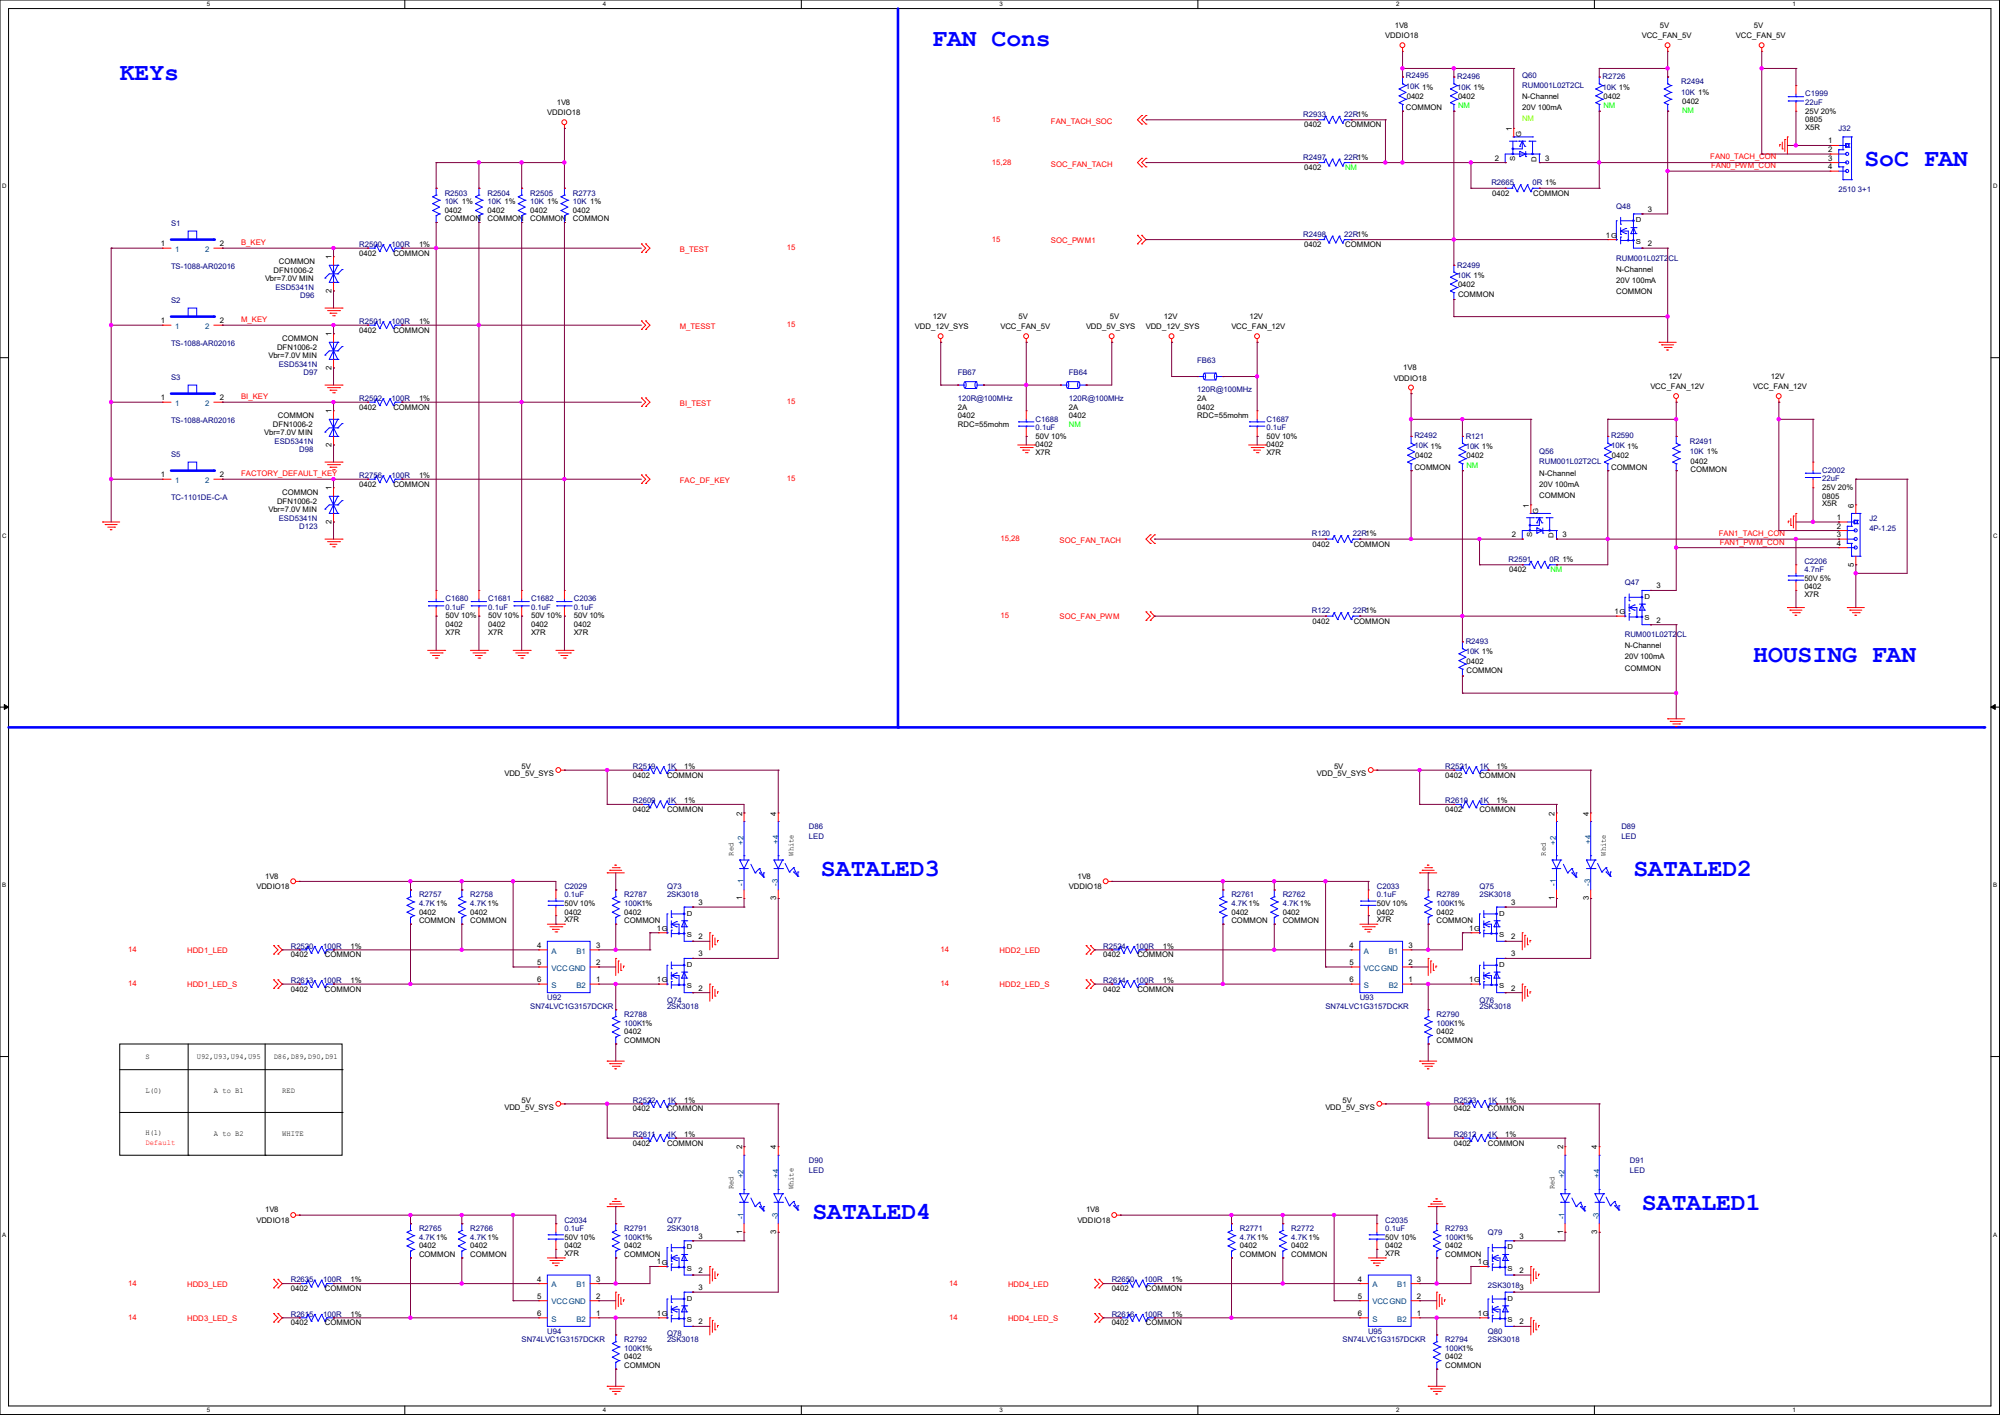
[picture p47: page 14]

Q47 | FAN1_PWM_CON | 4

D | D
Close to PIN 70,72,74 | Close to PIN 12,14,16,18

D | D

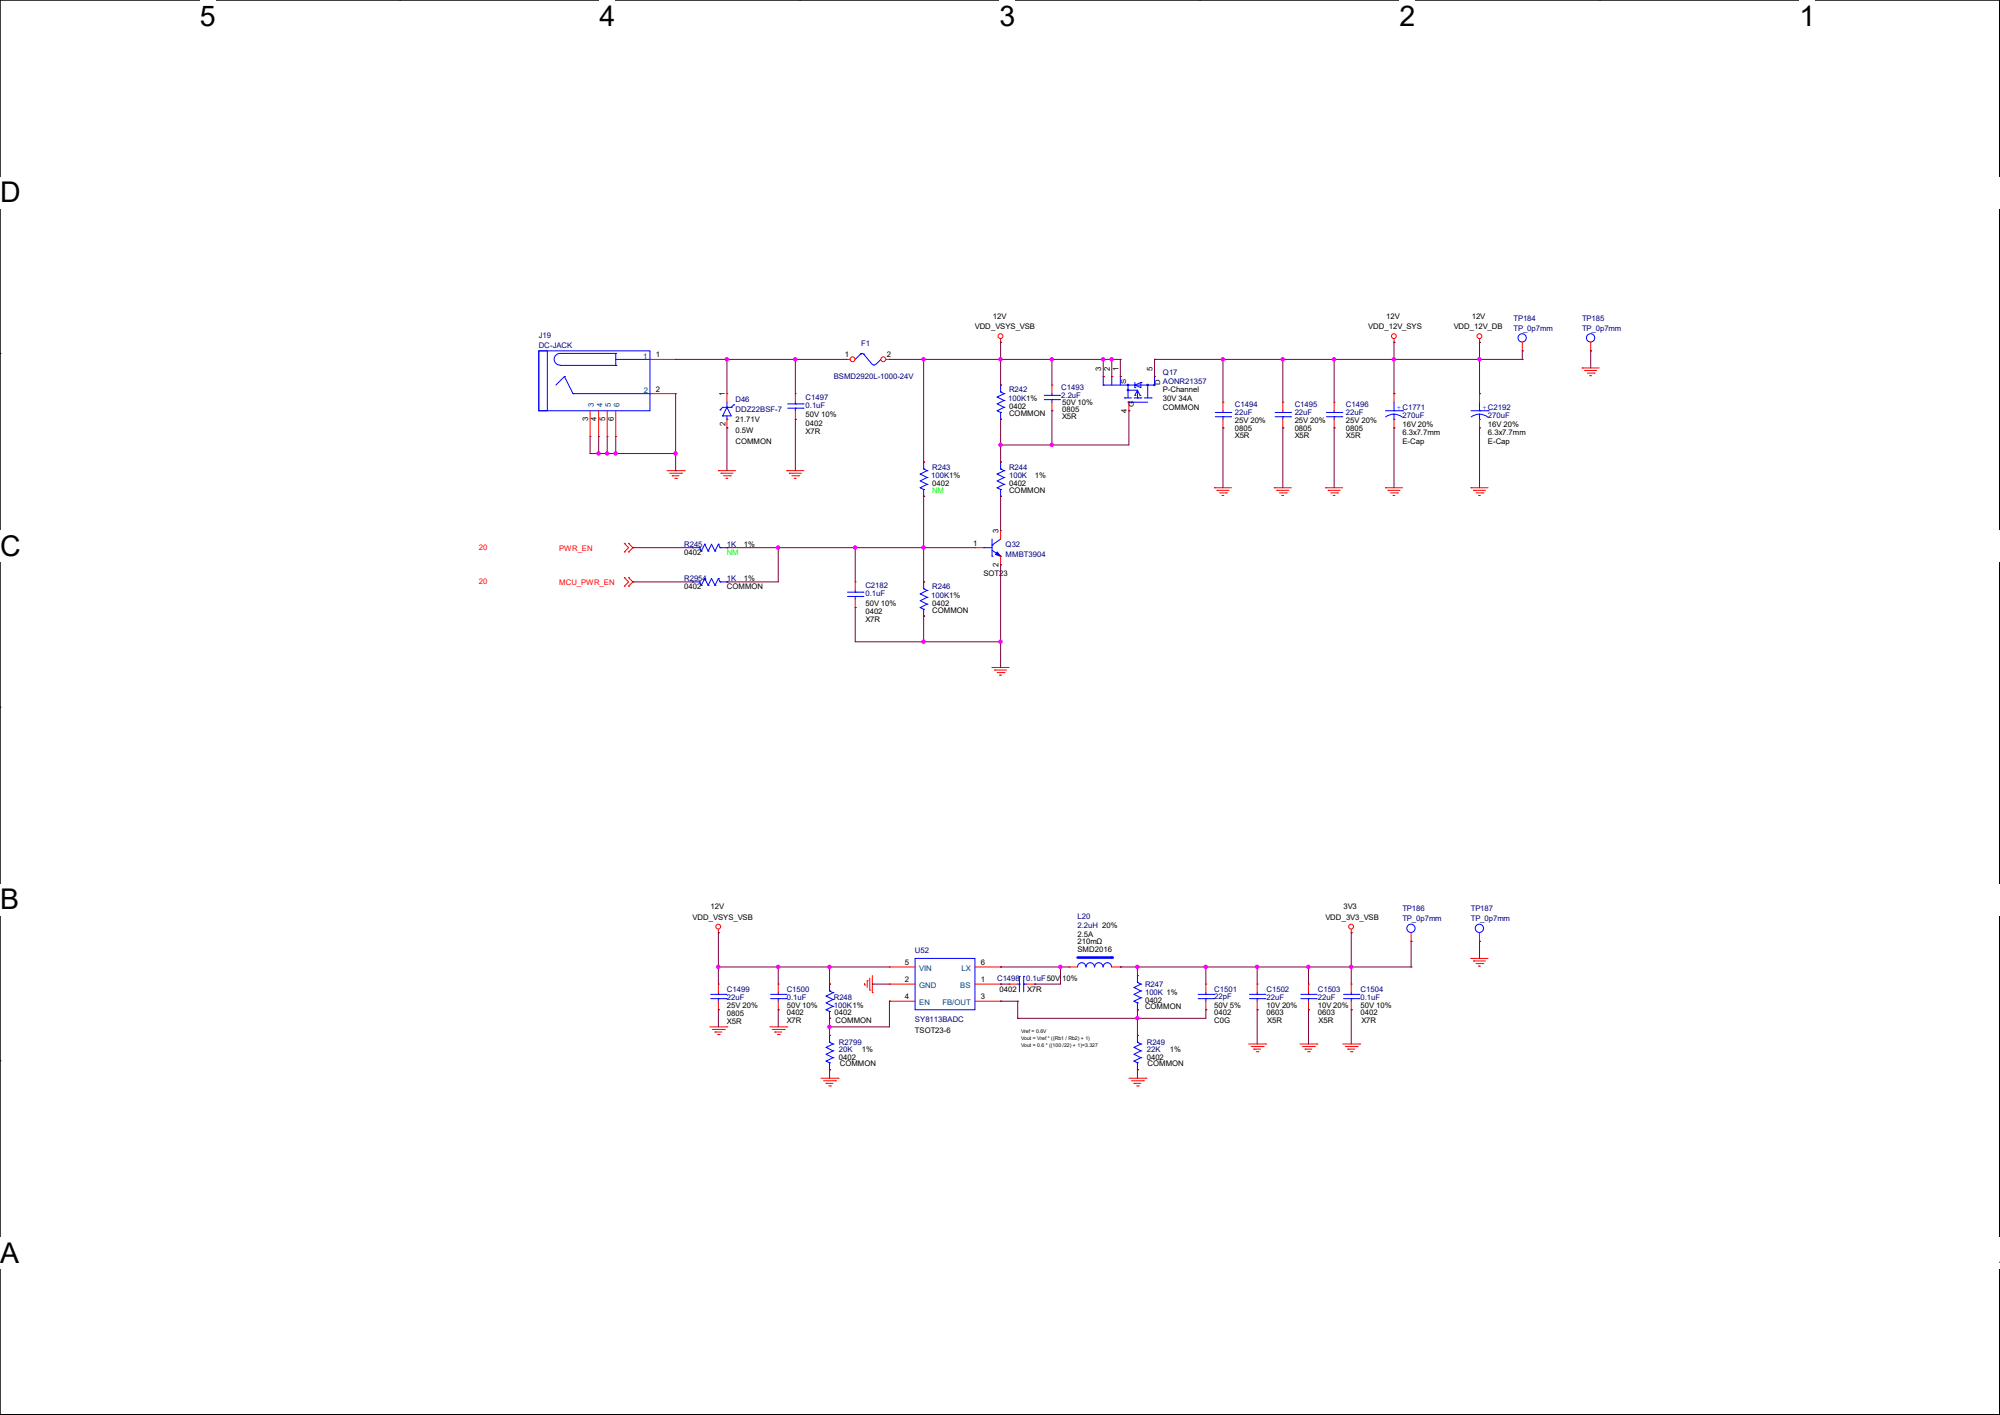
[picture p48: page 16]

D | D

## Heatsink 7700 Screw Hole

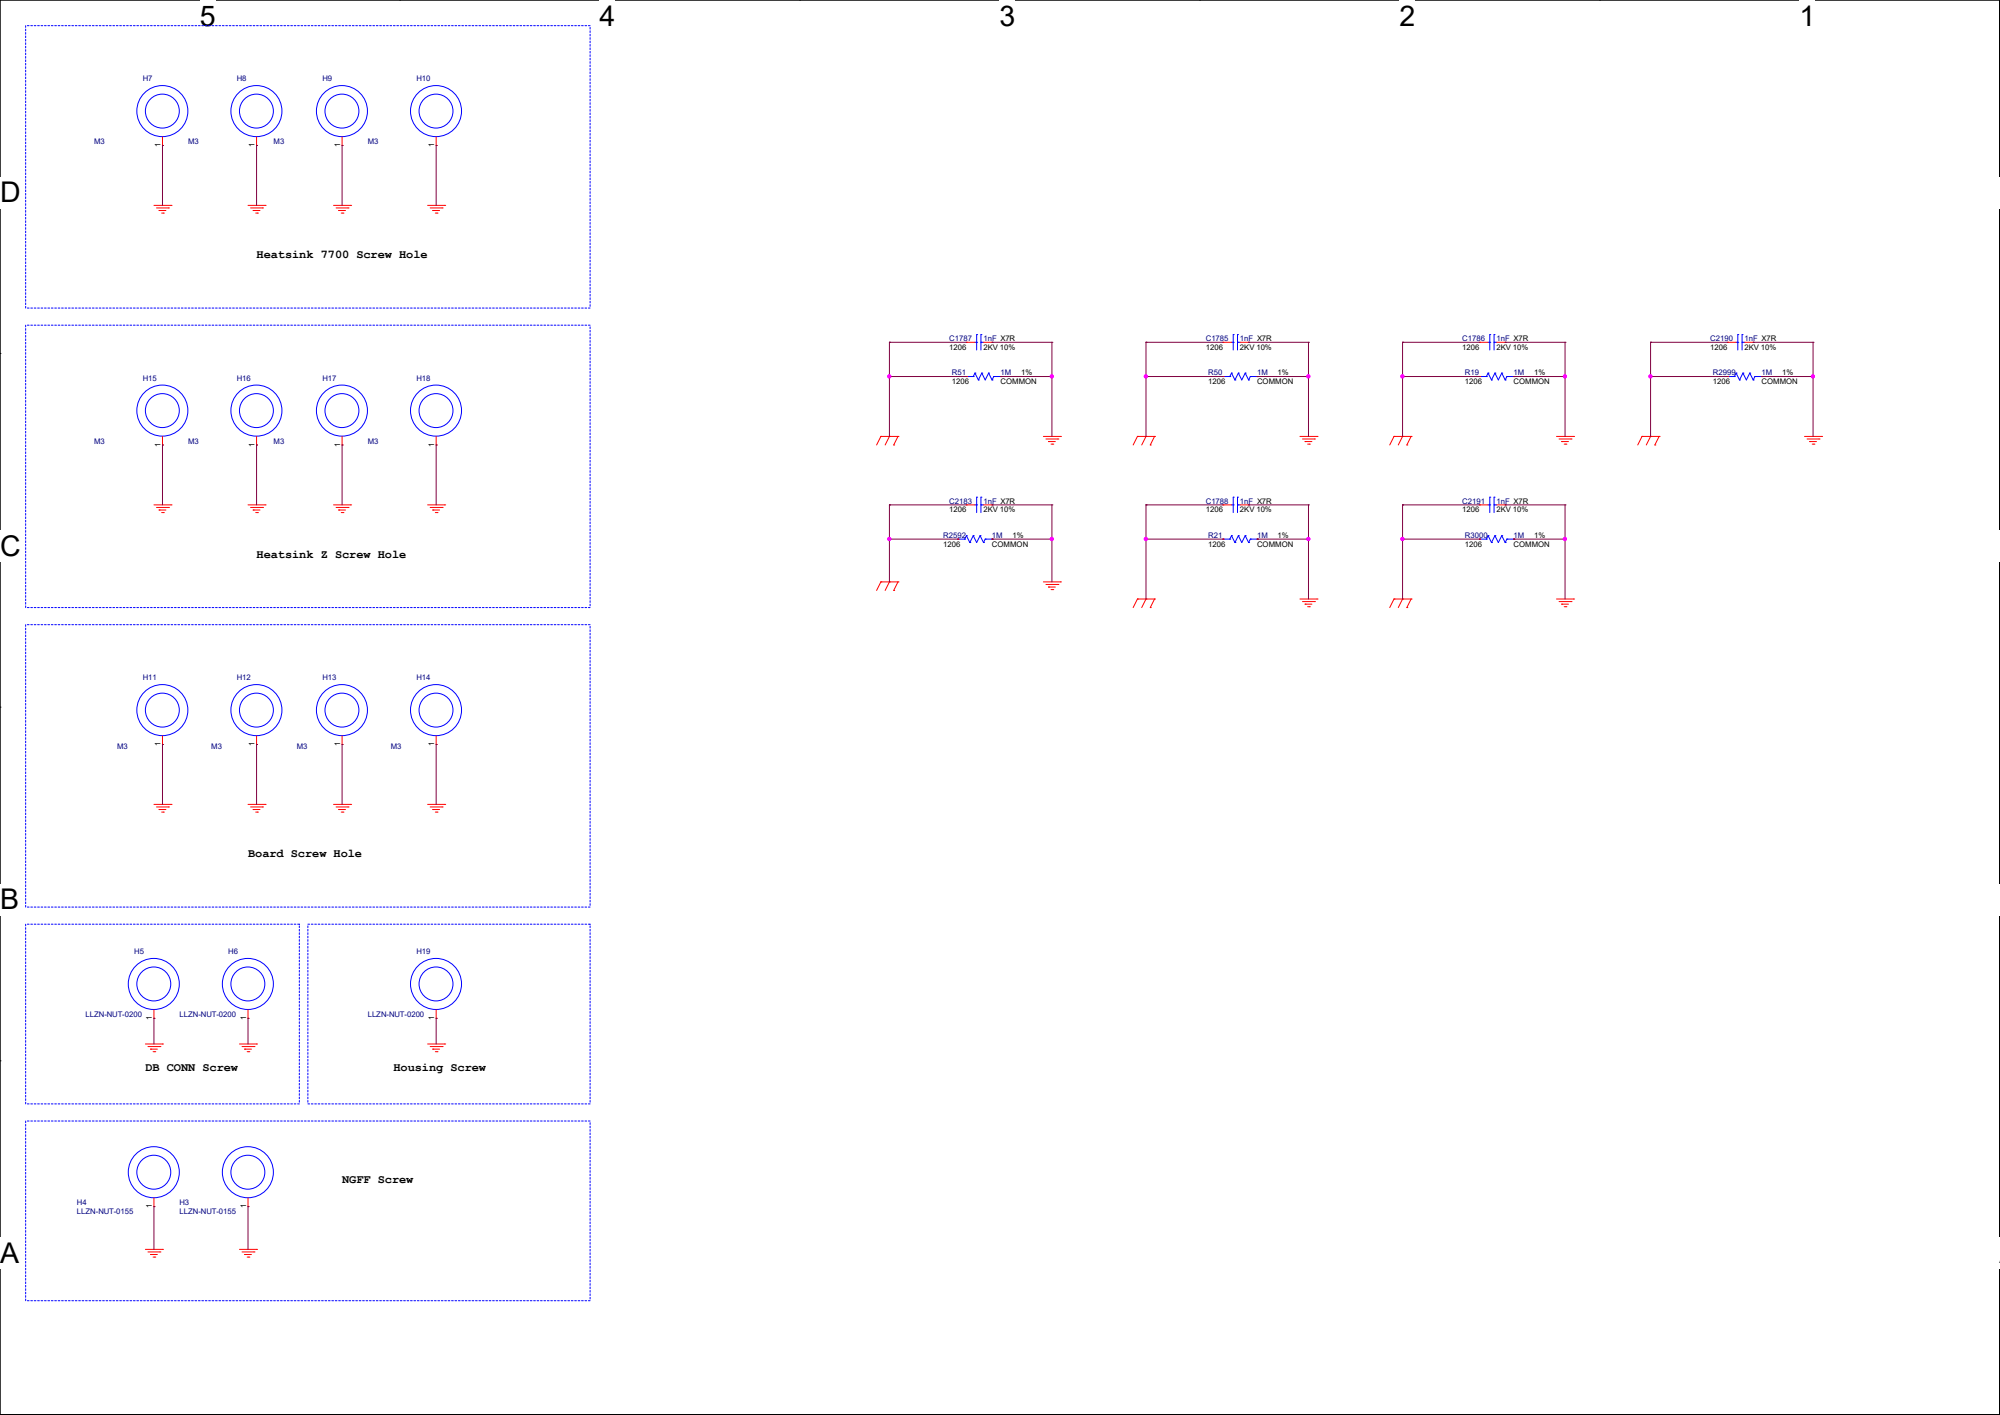
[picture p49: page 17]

D | D
C | C
B | B
A | A
A0 | 2026/04/07 | Zhangwenqiu | Initial Release
Issue Date | Author | Description
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

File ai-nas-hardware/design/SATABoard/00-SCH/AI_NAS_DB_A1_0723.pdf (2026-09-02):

D | D
C | C
B | B
A | A
A1 | 2026/04/07 | Zhangwenqiu | Initial Release
Issue Date | Author | Description

# Revision History

Version

DB CONN Screw; LLZN-NUT-0200 1

D | D


D | D

## U2_CON0


D | D

## SATA_CON1


SW perform uninstall HDD

SW change HDD*_PRSNTN to input to turn off the power of HDD*

D

D


D

D


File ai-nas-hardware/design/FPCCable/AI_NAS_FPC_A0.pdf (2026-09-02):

5

4

3

2

1

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

# Revision History

Version

5

4


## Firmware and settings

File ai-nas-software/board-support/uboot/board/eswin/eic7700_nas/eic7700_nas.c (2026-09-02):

// SPDX-License-Identifier: GPL-2.0
/*
 * eic7700 evb board init
 *
 * Copyright 2024, Beijing ESWIN Computing Technology Co., Ltd.. All rights reserved.
 * SPDX-License-Identifier: GPL-2.0
 *
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
 * Authors: Xiang Xu <xuxiang@eswincomputing.com>
 */
#include <common.h>
#include <dm.h>
#include <linux/delay.h>
#include <linux/io.h>
#include "env.h"
#include <errno.h>
#include <blk.h>
#include <net.h>
#include <stdlib.h>
#include <init.h>
#include <spi.h>
#include <spi_flash.h>
#include <dm/uclass-internal.h>
#include <dm/device-internal.h>
#include <dm/pinctrl.h>
#include <u-boot/crc.h>
#include <eic7700_common.h>
#include <eswin/cpu.h>
#include <asm/gpio.h>
#include <fdt_support.h>
#include <asm-generic/gpio.h>

int set_voltage_default(void)
{
	ofnode node;
	struct udevice *pinctrl;
	struct gpio_desc desc;

	node = ofnode_path("/config");
	if (!ofnode_valid(node)) {
		pr_err("Can't find /config node!\n");
		return -EINVAL;
	}
	if(uclass_get_device(UCLASS_PINCTRL, 0, &pinctrl)) {
		debug("%s: Cannot find pinctrl device\n", __func__);
		return -EINVAL;
	}
	if(pinctrl_select_state(pinctrl, "default")) {
		printf("Failed to set pinctrl state: %d\n", pinctrl_select_state(pinctrl, "default"));
		return -EINVAL;
	}
	if(gpio_request_by_name_nodev(node, "power-gpios", 0, &desc,
				   GPIOD_IS_OUT | GPIOD_IS_OUT_ACTIVE)) {
		pr_err("Can't request  \"power-gpios\" !\n");
		return -EINVAL;
	}
	dm_gpio_set_value(&desc, 0);
	return 0;
}

static int get_hardware_board_info(const char *node_name, HardwareBoardInfo_t *gHardware_Board_Info)
{
	HardwareBoardInfo_t gHardware_Board_InfoA;
	HardwareBoardInfo_t gHardware_Board_InfoB;
	struct spi_flash *flash = NULL;
	struct udevice *bus, *dev;
	uint64_t size = 0;
	uint32_t crc32ChecksumA, crc32ChecksumB;
	int ret;
	bool flaga, flagb;
	ret = uclass_get_device_by_name(UCLASS_SPI, node_name, &bus);
	if(ret) {
		return ret;
	}
	ret = spi_find_chip_select(bus, 0, &dev);
	if(ret) {
		printf("Invalid chip select :%d (err=%d)\n", 0, ret);
		return ret;
	}

	if (!device_active(dev)) {
		if(device_probe(dev))
			return -1;
	}
	flash = dev_get_uclass_priv(dev);
	if(!flash) {
		printf("SPI dev_get_uclass_priv failed\n");
		return -1;
	}

	size = sizeof(HardwareBoardInfo_t);
	memset((uint8_t *)&gHardware_Board_InfoA, 0, size);
	memset((uint8_t *)&gHardware_Board_InfoB, 0, size);
	printf("Get board info from flash\n");
	ret = spi_flash_read(flash, HARDWARE_BOARD_INFO_FLASH_MAIN_OFFSET, size, (void *)&gHardware_Board_InfoA);
	if(ret) {
		return ret;
	}
	ret = spi_flash_read(flash, HARDWARE_BOARD_INFO_FLASH_BACKUP_OFFSET, size, (void *)&gHardware_Board_InfoB);
	if(ret) {
		return ret;
	}
	crc32ChecksumA = crc32(0xffffffff,  (uint8_t *)&gHardware_Board_InfoA, sizeof(HardwareBoardInfo_t)-4);
	crc32ChecksumB = crc32(0xffffffff,  (uint8_t *)&gHardware_Board_InfoB, sizeof(HardwareBoardInfo_t)-4);
	flaga = crc32ChecksumA != gHardware_Board_InfoA.crc32Checksum || HARDWARE_BOARD_INFO_MAGIC_NUMBER != gHardware_Board_InfoA.magicNumber;
	flagb = crc32ChecksumB != gHardware_Board_InfoB.crc32Checksum || HARDWARE_BOARD_INFO_MAGIC_NUMBER != gHardware_Board_InfoB.magicNumber;
	if(flaga && flagb) {
		printf("ERROR: There is no valid hardware board information!!!\r\n");
		return -1;
	} else if(flaga) {
		memcpy(gHardware_Board_Info, &gHardware_Board_InfoB, size);
	} else if(flagb) {
		memcpy(gHardware_Board_Info, &gHardware_Board_InfoA, size);
	} else {
		if(gHardware_Board_InfoA.updateCount < gHardware_Board_InfoB.updateCount) {
			memcpy(gHardware_Board_Info, &gHardware_Board_InfoB, size);
		} else {
			memcpy(gHardware_Board_Info, &gHardware_Board_InfoA, size);
		}
	}
	return 0;
}

int hardware_info_env_set(void)
{
	uint8_t mac_addr[6];
	const char *node_name = "spi@51800000";
	HardwareBoardInfo_t gHardware_Board_Info;
	uint64_t size = sizeof(HardwareBoardInfo_t);
	memset((uint8_t *)&gHardware_Board_Info, 0, size);
	if(get_hardware_board_info(node_name, &gHardware_Board_Info)) {
		return 0;
	}
	memset(mac_addr, 0, 6);
	if (!eth_env_get_enetaddr("ethaddr", mac_addr) && is_valid_ethaddr(gHardware_Board_Info.ethernetMAC1)) {
		eth_env_set_enetaddr("ethaddr", gHardware_Board_Info.ethernetMAC1);
	}
	memset(mac_addr, 0, 6);
	if (!eth_env_get_enetaddr("eth1addr", mac_addr) && is_valid_ethaddr(gHardware_Board_Info.ethernetMAC2)) {
		eth_env_set_enetaddr("eth1addr", gHardware_Board_Info.ethernetMAC2);
	}

	char *boardSerialNumber = gHardware_Board_Info.boardSerialNumber;
	printf("boardSerialNumber %s\n",boardSerialNumber);
	return 0;
}

static int init_detect_gpios(void)
{
	int ret;
	int u2_det = 1;
	int detect = 0;
	int value = 0;
	int delay_time = env_get_ulong("hdd-spinup-mdelay", 10, 2000);
	ofnode node;
	struct gpio_desc desc;
	printf("hdd-spinup-mdelay : %d\n", delay_time);

	ofnode_for_each_compatible_node(node, "ai-nas,gpio-detect") {
		if (!ofnode_valid(node)) {
			printf("%s: Error parsing FDT node %s\n",
			      __func__, ofnode_get_name(node));
			break;
		}

		ret = gpio_request_by_name_nodev(node, "detect1-gpios", 0, &desc, GPIOD_IS_IN);
		if (ret == 0)
		{
			u2_det = dm_gpio_get_value(&desc);
		}

		ret = gpio_request_by_name_nodev(node, "detect-gpios", 0, &desc, GPIOD_IS_IN);
		if (ret != 0)
		{
			printf("Init %s failed, ret=%d\n", node.np->name, ret);
		}
		detect = dm_gpio_get_value(&desc);

		value = (u2_det && detect) ? 0 : 1;

		ret = dm_gpio_set_dir_flags(&desc, GPIOD_IS_OUT);
		if (ret) {
			printf("Failed to set output direction, ret=%d\n", ret);
			return ret;
		}
		ret = dm_gpio_set_value(&desc, value);
		if (ret) {
			return ret;
		}
		if(value)
			mdelay(delay_time);

	}
	return 0;
}

int misc_init_r(void)
{
	struct udevice *dev;

#ifdef CONFIG_ESWIN_PMP
	eswin_pmp_init();
#endif

#if defined(CONFIG_ESWIN_SPI)
	es_bootspi_write_protection_init();
#endif

	uclass_get_device_by_name(UCLASS_VIDEO, "display-subsystem", &dev);
	hardware_info_env_set();
	init_detect_gpios();

	eswin_update_bootargs();
	return 0;
}

void irq_mux_route(void)
{
	unsigned int val;

	/* Route all interrupts from default LPCPU/SCPU to MCPU
	 * I2C0 bit16
	 * I2C1 bit15
	 * RTC  bit14~13
	 * SPI  bit11~10
	 * DMA  bit9
	 * MPMP bit8
	 * TIMER1 bit5~4
	 * TIMER2 bit3~2
	 * TIMER3 bit1~0
	 *
	 * Route GPIO, TIMER0 to LPCPU
	*/

	val = 0x1040;
	writel(val,(void *)(0x51810000+0x3c0));
}

int board_init(void)
{
	irq_mux_route();
	return 0;
}

int board_late_init(void)
{
	return 0;
}

int ft_board_setup(void *blob, struct bd_info *bd)
{
	return eic770x_fdt_fixup_matched_memory_banks(blob, bd);
}

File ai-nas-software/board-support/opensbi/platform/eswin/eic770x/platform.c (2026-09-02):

// SPDX-License-Identifier: BSD-2-Clause
/*
 *
 * Copyright 2024 Beijing ESWIN Computing Technology Co., Ltd.
 *
 * Authors:
 *   XuXiang <xuxiang@eswincomputing.com>
 *   LinMin <linmin@eswincomputing.com>
 *   NingYu <ningyu@eswincomputing.com>
 *   HuangYifeng <huangyifeng@eswincomputing.com>
 *
 */

#include <libfdt.h>
#include <sbi/riscv_encoding.h>
#include <sbi/sbi_const.h>
#include <sbi/sbi_console.h>
#include <sbi/sbi_platform.h>
#include <sbi/sbi_system.h>
#include <sbi/sbi_timer.h>
#include <sbi/riscv_io.h>
#include <sbi_utils/irqchip/plic.h>
#include <sbi_utils/serial/uart8250.h>
#include <sbi_utils/timer/aclint_mtimer.h>
#include <sbi_utils/ipi/aclint_mswi.h>
#include <sbi_utils/fdt/fdt_pmu.h>
#include <sbi_utils/fdt/fdt_helper.h>
#include <sbi/riscv_asm.h>
#include <sbi_utils/fdt/fdt_fixup.h>
#include <sbi/sbi_hart.h>
#include "eic770x_uart.h"
#include "eic770x_mailbox.h"

/* clang-format off */
#ifdef BR2_CHIPLET_1
#ifdef BR2_CHIPLET_1_DIE0_AVAILABLE
#define EIC770X_HART_COUNT				4
#define	DIE_REG_OFFSET				0
#else
#define EIC770X_HART_COUNT				8
#define	DIE_REG_OFFSET				0x20000000
#endif
#else //BR2_CHIPLET_2
#define EIC770X_HART_COUNT				8
#define	DIE_REG_OFFSET				0
#endif

#define EIC770X_ACLINT_MSWI_ADDR			0x2000000
#define EIC770X_ACLINT_MTIMER_ADDR			0x2000000
#define EIC770X_ACLINT_MTIMER_FREQ			1000000
//#define EIC770X_ACLINT_MTIMER_FREQ			2000000

#define EIC770X_PLIC_ADDR				0xc000000
#define EIC770X_PLIC_NUM_SOURCES		520
#define EIC770X_PLIC_NUM_PRIORITIES		7

#define EIC770X_UART0_ADDR				(0x50900000UL + DIE_REG_OFFSET)
#define EIC770X_UART2_ADDR				(0x50920000UL + DIE_REG_OFFSET)
#define EIC770X_UART_RESET_ADDR			(0x51828434UL + DIE_REG_OFFSET)
#define EIC770X_UART_LSPCLK_ADDR			(0x51828200UL + DIE_REG_OFFSET)

#define EIC770X_UART_BAUDRATE			115200

#define EIC770X_UART_CLK       (200000000UL)

/* Full tlb flush always */
#define EIC770X_TLB_RANGE_FLUSH_LIMIT		0

/* system reset register */
#define EIC770X_SYS_RESET_ADDR	0x51828300UL
#define EIC770X_SYS_RESET_VALUE	0x1ac0ffe6

/* lpcpu mailbox2 */
#define EIC770X_LPCPU_MAILBOX_BASE_DIE0		0x50a20000UL
#define EIC770X_LPCPU_MAILBOX_BASE_DIE1		(EIC770X_LPCPU_MAILBOX_BASE_DIE0 + 0x20000000)
#define EIC770X_LPCPU_PM_SHUTDOWN_CMD		0x6F6666

/* clang-format on */

static struct plic_data plic = {
	.addr = EIC770X_PLIC_ADDR,
	.num_src = EIC770X_PLIC_NUM_SOURCES,
};

static struct aclint_mswi_data mswi = {
        .addr = EIC770X_ACLINT_MSWI_ADDR,
        .size = ACLINT_MSWI_SIZE,
        .first_hartid = 0,
        .hart_count = EIC770X_HART_COUNT,
};

static struct aclint_mtimer_data mtimer = {
	.mtime_freq = EIC770X_ACLINT_MTIMER_FREQ,
	.mtime_addr = EIC770X_ACLINT_MTIMER_ADDR +
		      0xbff8,
	.mtime_size = ACLINT_DEFAULT_MTIME_SIZE,
	.mtimecmp_addr = EIC770X_ACLINT_MTIMER_ADDR +
			 0x4000,
	.mtimecmp_size = ACLINT_DEFAULT_MTIMECMP_SIZE,
        .first_hartid = 0,
	.hart_count = EIC770X_HART_COUNT,
	.has_64bit_mmio = false,
};

#ifdef BR2_CHIPLET_1
#ifdef BR2_CHIPLET_1_DIE0_AVAILABLE
static u32 eic770x_hart_index2id[EIC770X_HART_COUNT] = {
	[0] = 0,
	[1] = 1,
	[2] = 2,
	[3] = 3,
};
#else
#ifdef BR2_CLUSTER_4_CORE
static u32 eic770x_hart_index2id[EIC770X_HART_COUNT] = {
	[0] = -1,
	[1] = -1,
	[2] = -1,
	[3] = -1,
	[4] = 4,
	[5] = 5,
	[6] = 6,
	[7] = 7,
};
#else
static u32 eic770x_hart_index2id[EIC770X_HART_COUNT] = {
	[0] = -1,
	[1] =  1,
	[2] = -1,
	[3] = -1,
	[4] = -1,
	[5] = -1,
	[6] = -1,
	[7] = -1,
};
#endif
#endif
#endif

#ifdef BR2_CHIPLET_2
static u32 eic770x_hart_index2id[EIC770X_HART_COUNT] = {
	[0] = 0,
	[1] = 1,
	[2] = 2,
	[3] = 3,
	[4] = 4,
	[5] = 5,
	[6] = 6,
	[7] = 7,
};
#endif

static void eic770x_modify_dt(void *fdt)
{
	fdt_cpu_fixup(fdt);

	fdt_fixups(fdt);

	/*
	 * SiFive Freedom U540 has an erratum that prevents S-mode software
	 * to access a PMP protected region using 1GB page table mapping, so
	 * always add the no-map attribute on this platform.
	 */
	/*当需要在resever memory中使能CMA内存时，需要关闭该函数的调用*/
	/*fdt_reserved_memory_nomap_fixup(fdt);*/
}
static int eic770x_system_reset_check(u32 type, u32 reason)
{
	switch (type) {
	case SBI_SRST_RESET_TYPE_SHUTDOWN:
	case SBI_SRST_RESET_TYPE_COLD_REBOOT:
	case SBI_SRST_RESET_TYPE_WARM_REBOOT:
		return 1;
	}

	return 0;
}

static int lpcpu_mailbox2_send_pm_shutdown(unsigned long lpcpu_base)
{
	eswin_mailbox_reg_t *mbox_reg;
	eswin_mbox_msg_t msg;
	u64 msg_data;

	if (!lpcpu_base)
		return -1;

	mbox_reg = (eswin_mailbox_reg_t *)lpcpu_base;
	msg_data = EIC770X_LPCPU_PM_SHUTDOWN_CMD;

	eswin_mailbox_add_data(&msg, (u8 *)&msg_data, 8);
	eswin_mailbox_send_irq(mbox_reg, &msg, ESWIN_MAIBOX_LPCPU_IRQ_BIT);

	return 0;
}

static void lpcpu_notify_pm_shutdown()
{
#ifdef BR2_CHIPLET_1
#ifdef BR2_CHIPLET_1_DIE0_AVAILABLE
	lpcpu_mailbox2_send_pm_shutdown(EIC770X_LPCPU_MAILBOX_BASE_DIE0);
	sbi_printf("Send PM_SHUTDOWN message to die0 lpcpu\n");
#else
	lpcpu_mailbox2_send_pm_shutdown(EIC770X_LPCPU_MAILBOX_BASE_DIE1);
	sbi_printf("Send PM_SHUTDOWN message to die1 lpcpu\n");
#endif
#else // BR2_CHIPLET_2
	lpcpu_mailbox2_send_pm_shutdown(EIC770X_LPCPU_MAILBOX_BASE_DIE0);
	lpcpu_mailbox2_send_pm_shutdown(EIC770X_LPCPU_MAILBOX_BASE_DIE1);
	sbi_printf("Send PM_SHUTDOWN message to die0 and die1 lpcpu\n");
#endif
	return;
}

/* tell stm32 on the carrier to shut down the power */
static int eic770x_core_shutdown(void)
{
	Message shutdown_reply = {
		.header = FRAME_HEADER,
		.msg_type = MSG_NOTIFLY,
		.cmd_type = CMD_POWER_OFF,
		.data_len = 0x0,
		.tail = FRAME_TAIL,
	};
	sbi_printf("%s\n", __func__);

	transmit_message(&shutdown_reply);
	sbi_timer_mdelay(3000);
	lpcpu_notify_pm_shutdown();
	return 0;
}

static int eic770x_cold_reset(void)
{
	Message shutdown_reply = {
		.header = FRAME_HEADER,
		.msg_type = MSG_NOTIFLY,
		.cmd_type = CMD_RESTART,
		.data_len = 0x0,
		.tail = FRAME_TAIL,
	};
	sbi_printf("%s\n", __func__);
	transmit_message(&shutdown_reply);
	sbi_timer_mdelay(3000);
	/*When it is not a DVB board, reboot can still be done, but there is no real power off/power on action at that time.*/
	writel(EIC770X_SYS_RESET_VALUE, (volatile void *)EIC770X_SYS_RESET_ADDR);
	return 0;
}

static int eic770x_core_reset(void)
{
	sbi_printf("%s\n", __func__);
	writel(EIC770X_SYS_RESET_VALUE, (volatile void *)EIC770X_SYS_RESET_ADDR);
	return 0;
}

static void eic770x_system_reset(u32 type, u32 reason)
{
	switch (type) {
	case SBI_SRST_RESET_TYPE_SHUTDOWN:
		eic770x_core_shutdown();
		break;
	case SBI_SRST_RESET_TYPE_COLD_REBOOT:
		eic770x_cold_reset();
		break;
	case SBI_SRST_RESET_TYPE_WARM_REBOOT:
		eic770x_core_reset();
		break;
	}

	sbi_hart_hang();
}

static struct sbi_system_reset_device eic770x_reset = {
	.name = "eswin_eic770x_reset",
	.system_reset_check = eic770x_system_reset_check,
	.system_reset = eic770x_system_reset
};
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

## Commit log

2026-09-02 init: AI NAS monorepo，整合 ai-nas-hardware 与 ai-nas-software
    [AI_NAS_DB_A1_0723.DSN, AI_NAS_DB__A2_PCB.brd, AI_NAS_FPC_A0.DSN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]
2026-09-02 ci: 修复镜像工作流 action 引用（wearerequired/mirror-action 已不存在，改用 git-mirror-action@v1）
2026-09-02 ci: 改用 shell 脚本镜像（HTTPS 克隆公开源仓 + SSH 推送 Gitee），去除第三方 action 依赖
2026-09-02 feat(sdk): 整理 AI NAS SDK 至 ai-nas-software 并按开源规范脱敏
    - 提取 eic7700-ai-nas 板级配置到 board-support/（linux/uboot/opensbi，保持上游目录结构）
    - linux: defconfig、设备树（含完整递归依赖链 6 个文件）、leds-ainas.h、NPU 固件
    - uboot: defconfig、board/eswin/eic7700_nas
    - opensbi: platform/eswin/eic770x
    - 固件仅保留本项目使用的 secboot_eic7700_ai_nas 与默认 DDR 固件，
    剔除其余 9 个板卡 secboot 变体与 ddr_low_freq/ddr_no_logo
    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
2026-09-02 docs: 补充许可证归属、脱敏说明与安全警告
    - NOTICE.md: 声明各目录许可（Mulan PSL v2 / GPL-2.0 / GPL-2.0+ / BSD-2-Clause）；
    标注二进制固件授权待确认；说明作者署名依许可证要求予以保留
    - README.md: 按许可证分区说明目录结构、submodule 挂载方式、构建步骤与可配置变量
    - SECURITY.md: 新增默认弱口令 eswin/eswin 风险与缓解措施
    - .gitignore: 补充构建产物与 submodule 挂载点忽略规则
2026-09-02 chore: 新增 .gitattributes 锁定行尾，避免脚本在 Linux 下因 CRLF 无法执行
2026-09-09 docs: 在 README 增加 GitHub Releases 二进制下载链接
2026-09-09 docs: 精简开源文档说明并调整脱敏表述
2026-09-10 docs: 将 OMV7 部署说明移入 GitHub Releases，从仓库移除
2026-09-10 docs(hardware): 移除 OMV7 部署说明条目（已迁移至 GitHub Releases）

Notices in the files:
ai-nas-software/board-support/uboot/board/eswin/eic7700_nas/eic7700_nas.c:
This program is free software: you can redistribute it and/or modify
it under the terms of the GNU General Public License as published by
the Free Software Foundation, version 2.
